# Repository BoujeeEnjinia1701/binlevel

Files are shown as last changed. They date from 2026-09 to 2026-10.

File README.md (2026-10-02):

# BinLevel

     

**Area:** Smart Cities · **TRL:** 3 of 9 (proof of concept on paper) · **Value-engineering target:** about $60 USD · **Difficulty:** 1 of 5

A fill-level sensor for public and communal bins that reports when bins need emptying so collection routes serve full bins, not empty ones.

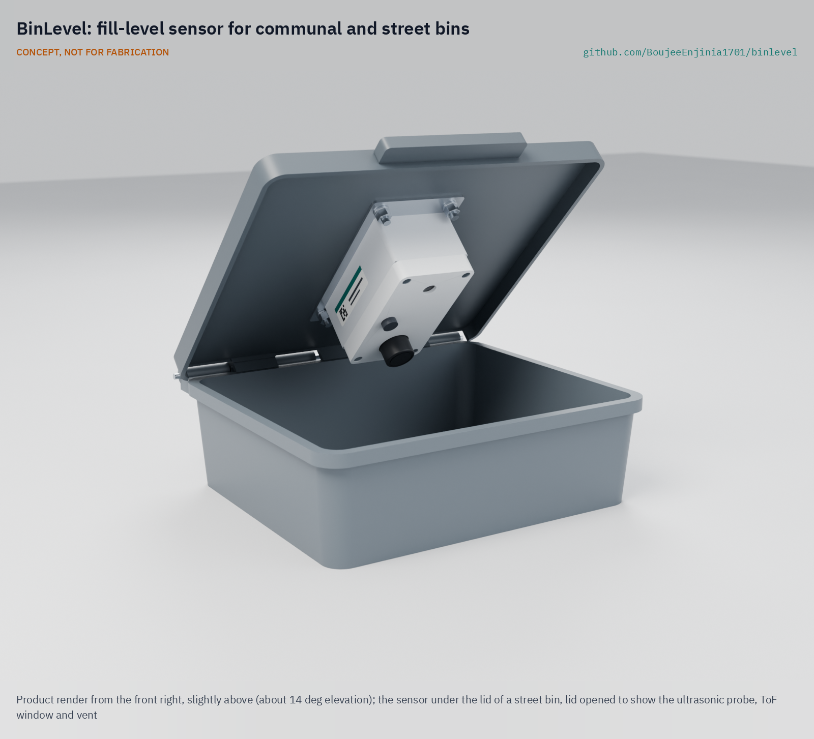
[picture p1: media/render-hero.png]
BinLevel: fill-level sensor for communal and street bins, product render


[Exploded render](media/render-exploded.png) · [Detail render](media/render-detail.png) · [Interactive 3D model](media/viewer.html) · [Concept blueprint (PDF)](media/concept-blueprint.pdf) · [General arrangement BNL-DWG-001 (PDF)](cad/drawings/BNL-DWG-001.pdf) · [Sizing note](docs/04-calcs/01-sizing.md) · [Prototype build plan](docs/05-build-plan.md) · [Design decisions](docs/06-design-decisions.md) · [Review note](docs/REVIEW.md)

## Concept rationale

A collection crew on a fixed timetable cannot tell a full bin from an empty one until it arrives. A small sensor under the lid that measures the distance down to the waste, and says so by radio a few times a day, gives the planner that knowledge before the truck leaves. BinLevel uses the same principle as commercial bin sensors (ultrasonic ranging, tilt and temperature) but adds a cheap time-of-flight sensor for the top of the bin, runs for a decade or more on one primary lithium cell (about 16 years in the worst radio case on paper), and sends only levels, never images or sound.

It is open and garage-buildable because the towns, campuses and community groups that most need better collection are least able to pay per-bin subscriptions for closed sensors. Every part is an off-the-shelf module in a stock enclosure, the payload format is documented, and it talks to any LoRaWAN network, including the lab's TwinKit gateway and The Things Network.

## Burning platform

The world produced about 2.56 billion tonnes of municipal waste in 2022, and the World Bank expects 3.86 billion tonnes by 2050 under business as usual ([World Bank, *What a Waste 3.0*](https://www.worldbank.org/en/publication/what-a-waste)). UNEP estimates the global direct cost of waste management at about USD 252 billion in 2020, rising to about USD 361 billion once the hidden costs of pollution, poor health and climate change are counted ([UNEP, 2024](https://www.unep.org/resources/global-waste-management-outlook-2024)).

The money does not reach everyone. Collection rates are as low as 31 % in Sub-Saharan Africa and 67 % in South Asia, and public spending on waste in most low- and middle-income countries is well below 0.15 % of GDP, against about 0.3 to 0.5 % needed for basic collection ([World Bank](https://www.worldbank.org/en/publication/what-a-waste)). With budgets this tight, a truck trip to a half-empty bin is a trip not made to an overflowing one.

## Where it could be used

### By industry

| Industry | Use |
| --- | --- |
| Municipal waste services and contractors | Plan daily routes around communal containers that are near full; confirm each emptying |
| Housing estates and property managers | Call for collection only when shared 660 to 1,100 L bins need it |
| Markets, ports and transport hubs | Watch high-turnover bins that fill unpredictably with trading and passenger peaks |
| Parks, beaches and tourism | Seasonal litter bins that sit empty in winter and overflow on summer weekends |
| Universities, hospitals and industrial sites | Campus bins and recycling points on private LoRaWAN networks |
| Recycling and deposit schemes | Glass, paper and textile banks that must be emptied before they overflow |

### By country or region

| Country or region | Why it matters there |
| --- | --- |
| Sub-Saharan Africa | Waste collection rates are as low as 31 % ([World Bank](https://www.worldbank.org/en/publication/what-a-waste)); sending scarce trucks to full communal points first stretches the service. |
| South Asia, including India | Collection rates are about 67 % ([World Bank](https://www.worldbank.org/en/publication/what-a-waste)); dense markets and housing produce fast, uneven fill that fixed timetables miss. |
| European Union | Each person generated about 517 kg of municipal waste in 2024 ([Eurostat](https://ec.europa.eu/eurostat/statistics-explained/index.php?title=Municipal_waste_statistics)); high labor costs make every avoided lift valuable. |
| England, United Kingdom | Councils dealt with 1.26 million fly-tipping incidents in 2024/25, 62 % of them household waste ([Defra](https://www.gov.uk/government/statistics/fly-tipping-statistics-for-england/fly-tipping-statistics-for-england-2024-to-2025)); clearing communal bins before they overflow helps keep side waste off the street. |
| United States | Americans generated 292.4 million tons of municipal waste in 2018, about 4.9 lb (2.2 kg) per person per day ([US EPA](https://www.epa.gov/facts-and-figures-about-materials-waste-and-recycling/national-overview-facts-and-figures-materials)); parks and campuses run large fleets of street bins. |

## What sparked the idea

The starting point was Philadelphia's 2009 rollout of 500 solar-powered BigBelly compactors, which replaced about 700 wire baskets on the promise that sensor-reported fullness would cut collections from 17 trips a week to five ([US EPA](https://archive.epa.gov/international/jius/web/html/bigbelly_trash_compactors.html)). In July 2010 City Controller Alan Butkovitz reported that collections averaged about 10 a week, that each compactor had cost about $3,700, and that the city had relied solely on the maker's claims without independent verification ([NBC10 Philadelphia](https://www.nbcphiladelphia.com/news/local/bigbelly-trash-compactors-a-big-fat-waste-of-money-controller/2140012/)). Both sides agreed that knowing how full a bin is saves trips; the dispute was over how much, and only the vendor held the data. BinLevel separates that knowledge from the bin: a sensor with about $55 of parts, roughly 1.5 % of the price of one of those compactors, that fits containers a city already owns, with an open payload so the city can check the savings itself.

## Problem

Fixed collection schedules empty half-full bins while others overflow. Cities and communities have no cheap, open way to know how full each bin is before the truck leaves.

## Concept

A sealed box under the bin lid measures the distance to the waste every 15 minutes with an ultrasonic transducer, backed by a time-of-flight sensor for the top of the bin. It sends fill level, temperature, emptying events and battery state in an 11-byte LoRaWAN uplink every hour (every 2 hours at SF12), or at once when the bin passes a set level (default 80 %). A primary lithium C cell lasts about 16 years in the worst radio case on paper, so the 10-year design life is set by seals and plastics. Parts cost $59.00 (indicative), within the $60 value-engineering target; the unit weighs about 350 g, inside its 400 g target. No camera, no microphone.

Full design precis: [docs/02-concept.md](docs/02-concept.md). Requirements, including those not yet met (IP69K washing and radio inside steel containers) and those at risk (accuracy on real waste and hot lids): [docs/03-requirements.md](docs/03-requirements.md). Sizing calculations: [docs/04-calcs/01-sizing.md](docs/04-calcs/01-sizing.md). Decisions by Amish: [docs/decisions/0001-trl2-review-decisions.md](docs/decisions/0001-trl2-review-decisions.md) and [docs/decisions/0002-recommendations-accepted.md](docs/decisions/0002-recommendations-accepted.md); design for construction, accepted on 2026-10-02: [docs/decisions/0003-design-for-construction.md](docs/decisions/0003-design-for-construction.md). Every open and made decision: [docs/06-design-decisions.md](docs/06-design-decisions.md).

## Key components

- Stock IP67 enclosure (115 x 65 x 55 mm) held on four press-in studs in a 2 mm aluminium plate, bolted under the lid with four stainless tamper-resistant M6 bolts
- Sealed 40 kHz ultrasonic transducer (main range, from about 0.25 m to the container floor)
- Near-range time-of-flight sensor (top 0.4 m of the bin, where the 80 % threshold lies)
- RAK3172 (STM32WL) LoRaWAN module, the same radio family as FieldNode
- Carrier board with accelerometer (emptying and lid events), temperature sensor and nanopower regulator
- Li-SOCl2 C cell, multi-year life
- Flexible antenna inside the box; the first pilot uses plastic containers only, and an external lid antenna for steel containers is a later option

The working bill of materials is in [bom/bom.csv](bom/bom.csv).

## Building the prototype

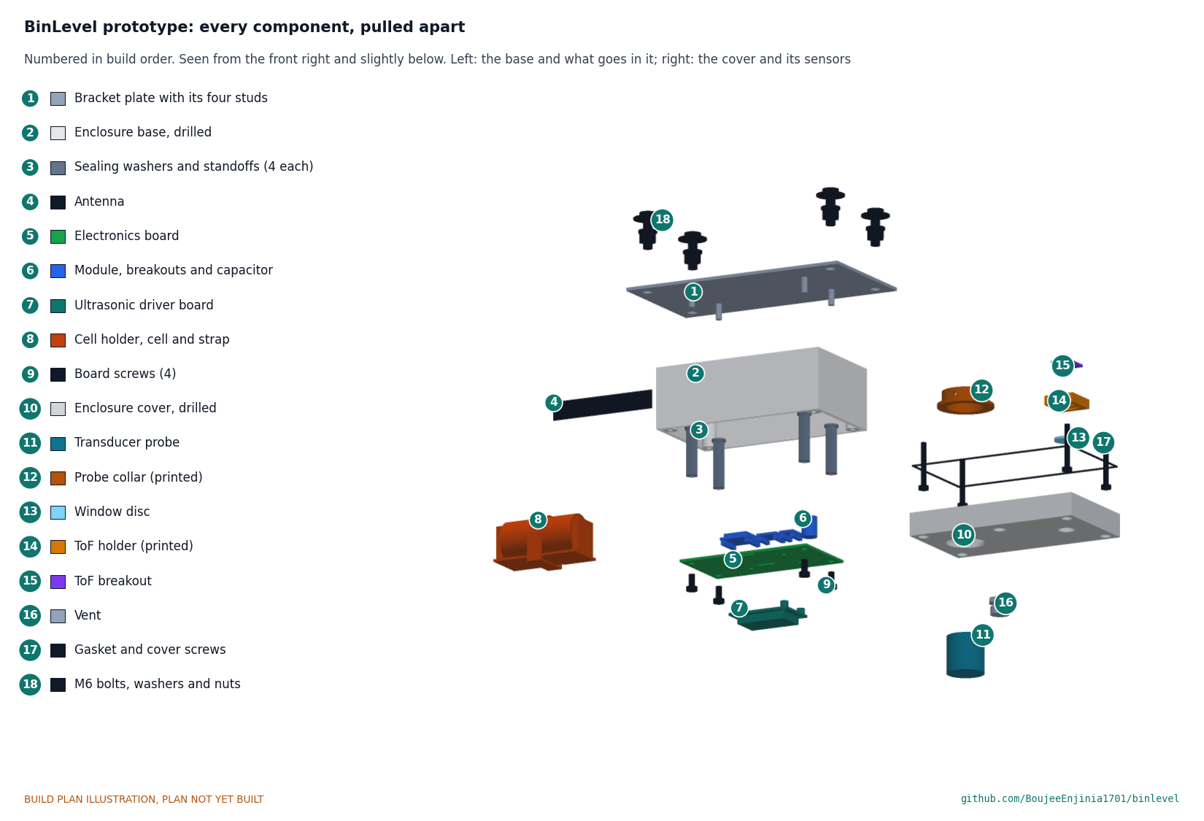
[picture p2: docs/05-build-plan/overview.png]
Every component of the BinLevel prototype, pulled apart and numbered in build order


The prototype build plan ([docs/05-build-plan.md](docs/05-build-plan.md)) shows how to make each component and fit it to the next, with a making sketch for every made part and a picture for every assembly step. The box hangs under a flat aluminium plate on four pressed-in studs; the electronics board, cell and antenna sit in the box's base, and the transducer, light sensor window and vent sit in its downward-facing cover. The work is drilling thin aluminium and plastic, two small 3D prints, bonding and soldering bought breakout boards, for about $59 in parts. It is a plan, not yet built: building and testing to it is TRL 4 work.

## Safety

> The Li-SOCl2 cell is a primary lithium cell: never charge, short, crush or overheat it, fuse it, and recycle spent cells through a battery collection point, never in the bin. Bins hold sharp objects and biological waste: install and service sensors only on emptied, cleaned containers with cut-resistant gloves and eye protection, and deburr drilled lids. The temperature alert is a maintenance aid, not fire detection.

## Repository layout

| Folder | Contents |
| --- | --- |
| `docs/` | Problem, concept, requirements, calculations and design decisions |
| `cad/src/` | build123d Python source, the source of truth for all geometry |
| `cad/step/`, `cad/stl/` | Exported models for FreeCAD, other CAD tools and printing |
| `cad/drawings/` | 2D sketches and dimensioned drawings |
| `bom/` | Bill of materials |
| `electronics/` | KiCad schematics and PCB layouts |
| `firmware/` | Microcontroller code |
| `media/` | Renders, perspectives and photos |
| `build-log/` | Dated prototyping notes |

## Documentation

Controlled documents follow the portfolio [documentation standard](.kit/STANDARDS.md). Each carries a document ID (BNL-PRC-001 for the precis), a version and a revision history. Branded PDFs are built with `python .kit/render.py` and attached to GitHub Releases when a document is tagged, for example `BNL-PRC-001/v1.0`.

## Credits

Designed by Amish Chadha. See [CONTRIBUTORS.md](CONTRIBUTORS.md) for roles. To cite this design, use [CITATION.cff](CITATION.cff) (GitHub shows it as "Cite this repository").

AI assistance (Claude) was used to accelerate concept renders, prototype documentation and first-pass sizing calculations. Design direction and all decisions are Amish Chadha's, recorded in this repository's decision records (`docs/decisions/`).

## Licenses

- **Hardware** (CAD, drawings, BOM, electronics): [CERN-OHL-S v2](LICENSE)
- **Software** (firmware, scripts, notebooks): [MIT](LICENSE-SOFTWARE)

A project of the [Design Molecule](https://designmolecule.com) lab.

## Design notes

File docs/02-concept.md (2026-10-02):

---
doc_id: BNL-PRC-001
title: BinLevel design precis
project: BinLevel
doc_type: Design precis
version: "0.7"
status: Draft
date: '2026-10-02'
author: Amish Chadha
license: CERN-OHL-S-2.0
revisions:
- version: "0.1"
  date: '2026-09-25'
  author: Amish Chadha
  change: Initial scaffold
- version: "0.2"
  date: '2026-09-25'
  author: Amish Chadha
  change: Concept for TRL 2 with components, first-order numbers, safety and open questions
- version: "0.3"
  date: '2026-09-25'
  author: Amish Chadha
  change: Design choices adopted for TRL 3 (BNL-DDR-001); numbers checked against BNL-CAL-001; 11-byte payload, nanopower regulator, 5 min temperature reads and cell strap added
- version: "0.4"
  date: '2026-09-25'
  author: Amish Chadha
  change: Recommendations accepted by Amish (DDR-002)
- version: "0.5"
  date: '2026-09-30'
  author: Amish Chadha
  change: Design for construction (BNL-DDR-003); 55 mm box, box fixings and printed sensor mounts added; mass, envelope and cost from BNL-CAL-001 v0.3
- version: "0.6"
  date: '2026-10-01'
  author: Amish Chadha
  change: Budget treated as a value-engineering target
- version: "0.7"
  date: '2026-10-02'
  author: Amish Chadha
  change: "Open decisions of 2026-10-02 carried in: steel containers out of the first pilot, galvanic isolation, data layer, fill rate left to the server, first partner to approach"
---

# BinLevel design precis

## Summary

BinLevel is a small sealed box bolted under the lid of a communal or public bin. Every 15 minutes it measures the distance down to the waste with a sealed ultrasonic transducer, backed by a time-of-flight (ToF) sensor for the top of the bin, and turns it into a fill percentage. It sends the level, temperature, tilt events and battery state by LoRaWAN every hour (every 2 hours at SF12), or at once when the bin passes a set level. A primary lithium C cell would last about 16 years in the worst radio case on paper, so seals and plastics, not the cell, set the 10-year design life. Parts cost is $59.00 (indicative), within the $60 value-engineering target, and the unit weighs about 350 g, inside the 400 g target (BNL-CAL-001). The design is constructable (BNL-DDR-003), and the prototype build plan BNL-BLD-001 shows how to build it. It carries no camera and no microphone.

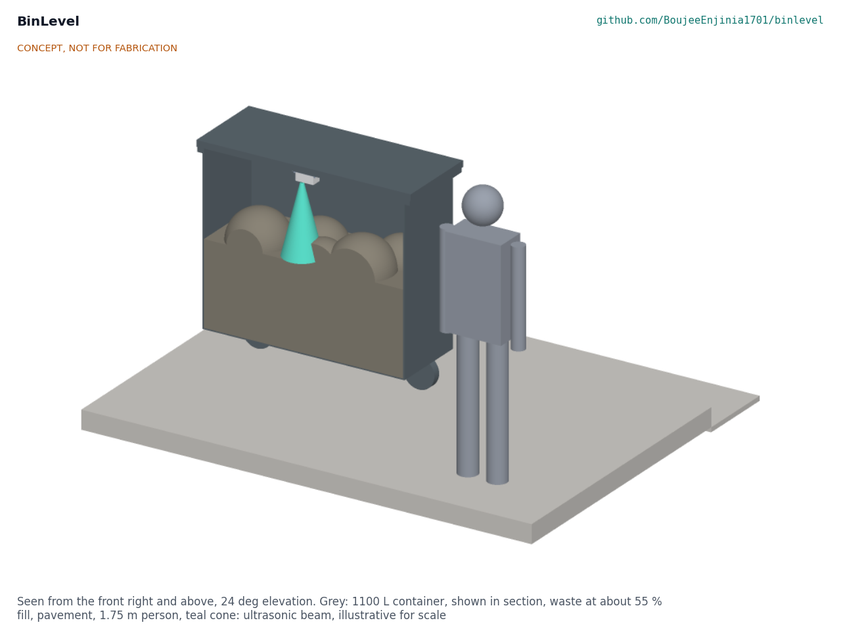
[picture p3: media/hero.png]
Figure 1. BinLevel under the lid of an 1,100 L communal container, shown in section, with a 1.75 m person for scale. Concept, not for fabrication.


## How it works

1. **Measure.** The microcontroller wakes every 15 minutes, switches on the ultrasonic transducer and takes five pings, then reads the ToF sensor. It keeps the median ultrasonic distance and uses the ToF reading when the surface is closer than the ultrasonic blind zone (about 0.25 m, estimate).
2. **Interpret.** Distance is converted to fill percentage against the empty depth stored at installation. A fill above the threshold (default 80 %) or an abnormal temperature, read every 5 min, triggers an immediate uplink. The heat rule is 70 °C, or a rise of 15 K in 15 min counted only while the unit is above 50 °C, so a sunny lid does not raise false alarms.
3. **Sense events.** A low-power accelerometer wakes the controller when the bin is tipped (emptying confirmed) or when the lid is opened (usage count), so the service gets proof of collection without a driver app.
4. **Report.** A LoRaWAN Class A uplink of 11 bytes carries fill %, raw distance, temperature, event counters and battery voltage. Any LoRaWAN network server can receive it: the lab's TwinKit gateway, The Things Network or a city network.
5. **Plan.** The server passes levels to a route planner, which schedules the bins that are full or will be full before the next round (Figure 2).

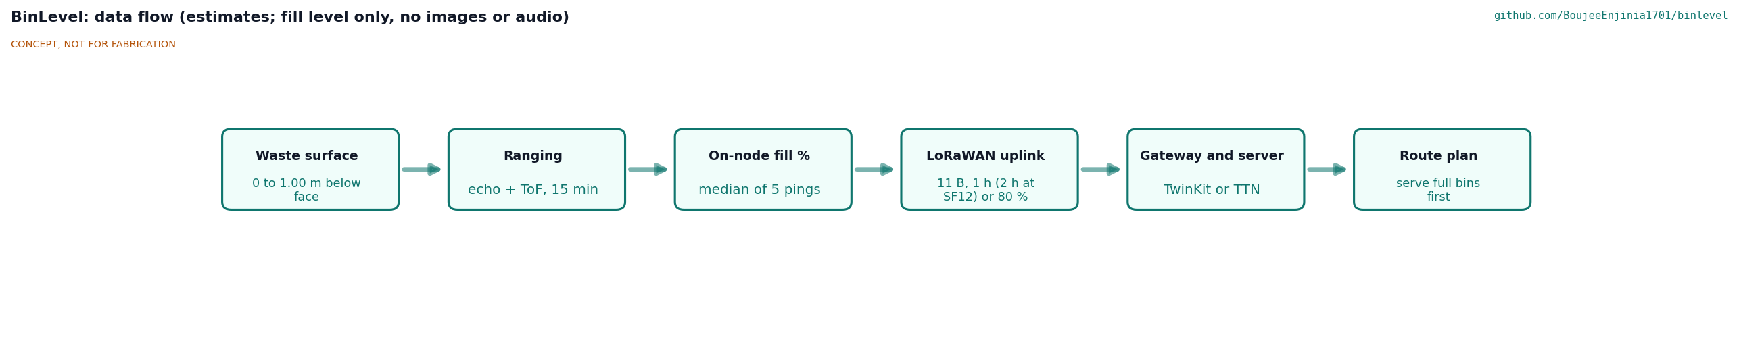
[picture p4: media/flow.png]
Figure 2. Data flow from waste surface to route plan. Values are estimates. Fill level only; no images or audio.


## Main components

Numbers match the exploded view (Figure 3) and `bom/bom.csv`. Main dimensions and interfaces are on the general arrangement drawing BNL-DWG-001 (`cad/drawings/BNL-DWG-001.pdf`), generated from `cad/src/model.py`.

| No. | Component | Role |
| --- | --- | --- |
| 1 | Enclosure, IP67 ABS or PC, about 115 x 65 x 55 mm, cover facing down | Protects electronics; holes for transducer, ToF window and vent in the cover |
| 2 | Aluminium bracket plate, 2 mm 5052 class, and four stainless tamper-resistant M6 x 20 bolts on a 130 x 60 mm pattern | Fixes the unit under the lid; bolts pass through the lid |
| 3 | Sealed 40 kHz ultrasonic transducer (JSN-SR04T class) with driver | Main range sensor, about 0.25 to 1.5 m (estimate) |
| 4 | Near-range ToF sensor (VL53L1X class) behind a window | Top of bin and overfill, about 0.03 to 0.4 m (estimate) |
| 5 | LoRaWAN module, RAK3172 (STM32WL) | Controller and radio in one module, as in FieldNode |
| 6 | Carrier board with accelerometer, temperature sensor, nanopower regulator, load switch and buffer capacitor (a prototyping board with breakouts for the first prototype) | Joins the parts; powers sensors only while measuring; keeps the module below 3.6 V |
| 7 | Li-SOCl2 primary cell, C size, 3.6 V, about 8.5 Ah nominal, with strapped holder and fuse | Multi-year energy store |
| 8 | Flexible 868/915 MHz antenna | Radio antenna inside the enclosure (external lid antenna for steel bins is a later option; not in the first pilot) |
| 9 | Gasket and vent membrane | Keeps water and condensation out |
| 10 | Box fixings: four press-in studs in the plate, sealing washers and standoffs | Hold the box to the plate and carry the board |
| 11 | Printed probe collar and ToF holder, window disc | Hold the sensors in the cover |

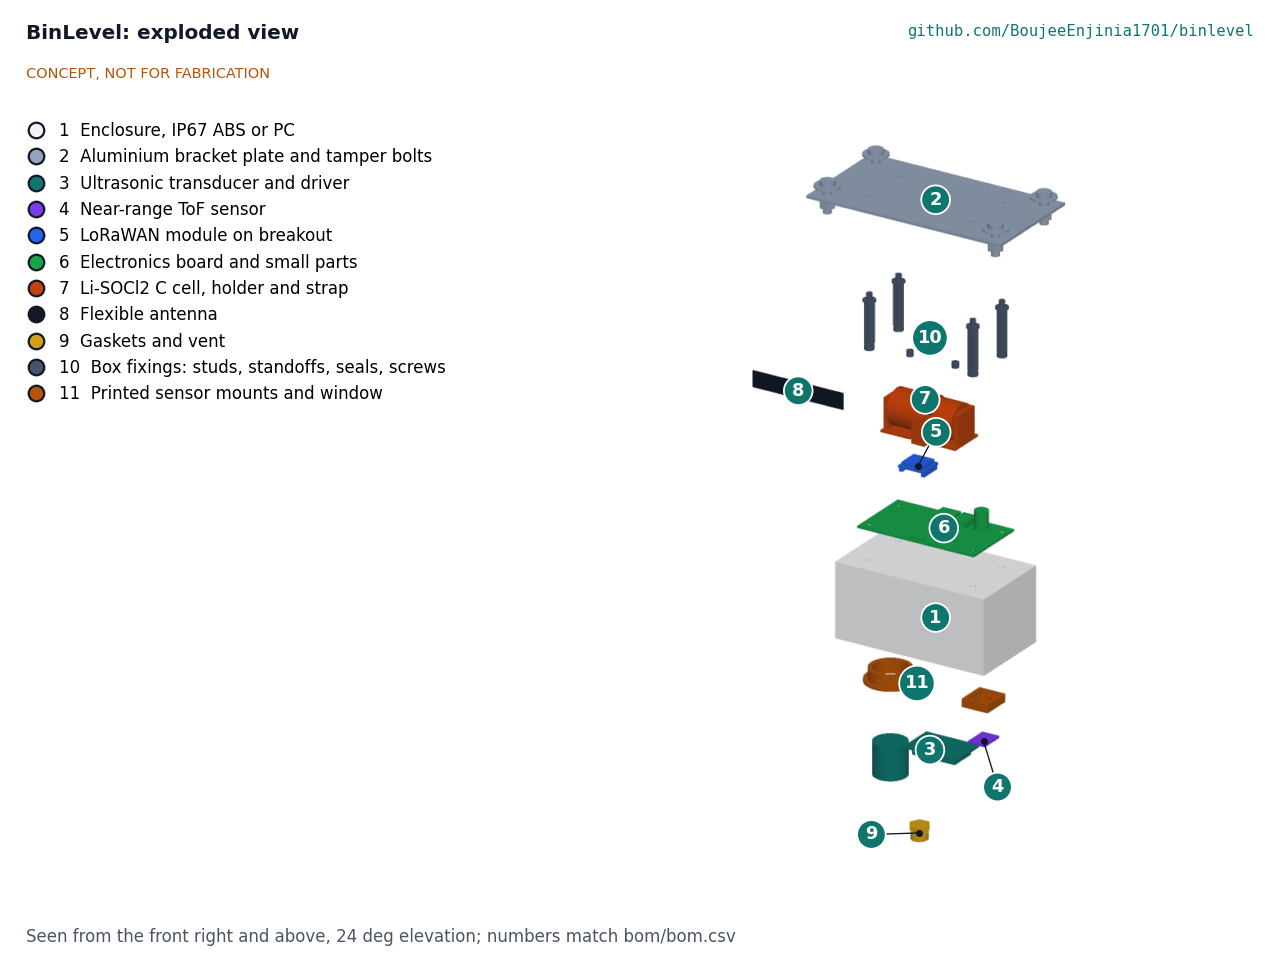
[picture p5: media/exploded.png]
Figure 3. Exploded view with BOM numbers. Concept, not for fabrication.


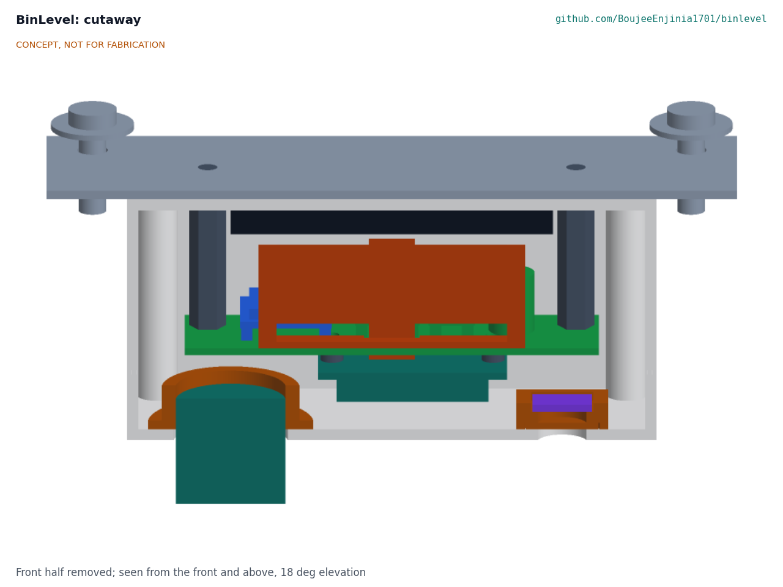
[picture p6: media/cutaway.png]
Figure 4. Cutaway of the sensor unit showing the cell, carrier PCB, module, transducer and ToF sensor. Concept, not for fabrication.


## First-order numbers

The numbers below are from the sizing note BNL-CAL-001, which checks every requirement against the parametric model `cad/src/model.py`. They are paper estimates, not measurements.

### Energy budget

Sleep current is 6.0 µA for the whole unit (module 2.0 µA, accelerometer 2.0 µA, temperature sensor 0.5 µA, regulator and leakage 0.5 µA, buffer capacitor 1.0 µA). Each ranging cycle takes 7.5 mAs; each uplink transmits at +14 dBm at an assumed 45 mA. Usable capacity is taken as 60 % of nominal, with self-discharge of 1 % of nominal a year.

Table 1. Daily charge use and life, with two alert uplinks a day (BNL-CAL-001, section C).

| Item | SF9, hourly uplink | SF12, uplink every 2 h |
| --- | --- | --- |
| Sleep (6.0 µA x 24 h) | 0.144 mAh | 0.144 mAh |
| Ranging (96 cycles) and temperature reads | 0.201 mAh | 0.201 mAh |
| Uplinks | 0.086 mAh (26 x 0.21 s airtime) | 0.278 mAh (14 x 1.48 s airtime) |
| Self-discharge (C cell) | 0.233 mAh | 0.233 mAh |
| **Total** | **0.664 mAh per day** | **0.856 mAh per day** |
| Life on C cell (5.1 Ah usable) | 21.0 years | 16.3 years |
| Life on AA cell (1.56 Ah usable) | 8.5 years | 6.2 years |

The cell is not the limit on life; seals, the transducer membrane and the enclosure plastic under UV and heat are. The design target is therefore stated as 10 years (R4). The AA cell would meet the 5-year minimum but not the 10-year target, which is why the C cell is adopted (DDR-001, D3).

A fresh Li-SOCl2 cell rests at 3.67 V, above the RAK3172 module's 3.6 V maximum ([RAK3172 datasheet](https://docs.rakwireless.com/product-categories/wisduo/rak3172-module/datasheet/)), so the carrier includes a nanopower 3.3 V regulator. The cell carries the transmit pulse; a 1,000 µF low-leakage capacitor covers the voltage delay of a passivated cell.

### Radio airtime

The payload is 11 bytes (it was 12 at TRL 2), so that it fits the 11-byte limit of the slowest US915 data rate. It takes about 0.21 s at SF9 and about 1.48 s at SF12 (125 kHz). Hourly uplinks with two alerts use about 5.4 s per day at SF9, well inside TTN's 30 s daily fair use, but 38.6 s at SF12, which would exceed it. SF11 hourly uses 21.4 s. The firmware therefore stretches the routine interval to 2 hours at SF12 only (20.8 s per day) and keeps threshold alerts immediate (DDR-001, D6, as refined by DDR-002).

### Link

With a 10 dB fade margin and an urban path-loss model, a sensor in an HDPE container reaches a gateway about 0.8 km away at SF9 and 1.3 km at SF12. Inside a steel container the range falls to about 0.35 km even at SF12; an external lid antenna restores 1.3 to 2.1 km. Steel containers are left out of the first pilot, which uses plastic containers only (decided by Amish, 2026-10-02; DDR-001, O1); the antenna is revisited once the link loss inside a steel container has been measured.

### Measurement

- The transducer face is 1.00 m above the floor of an 1,100 L container. At 80 % fill the surface is 0.20 m below the face, inside the ultrasonic blind zone (about 0.25 m, estimate), which is why the ToF sensor covers the top 0.4 m. The two sensors overlap between 60 % and 75 % fill.
- The instrument error, with speed of sound compensated from the on-board temperature, is about 10 mm for the ultrasonic sensor and 20 mm for the ToF sensor, against the ±101 mm (±10 % of depth) accuracy target. Accuracy on real waste is limited by the surface, not by the sensor.
- An ultrasonic beam of 15° half-angle (assumed) covers a patch about 0.54 m across at the floor. Mounted at the lid center, the beam clears the walls for half-angles up to about 26°.
- The temperature is read every 5 min (not only with each 15 min ranging), so a heat alert reaches the server within about 7.5 min.

### Mass and cost

- Mass about 350 g: enclosure 94 g, 2 mm aluminium plate 63 g, bolts, nuts and washers 36 g, box fixings 22 g, cell, holder and strap 59 g, transducer, board, module, printed mounts and small parts about 76 g. This is inside the 400 g limit of R16. The 1.5 mm stainless bracket of BNL-PRC-001 v0.3 weighed 183 g and made the unit about 435 g; Amish chose the aluminium bracket on 2026-09-25 (DDR-002).
- Envelope below the lid 150 x 80 x 71.5 mm.
- Parts cost $59.00 at prototype quantities (indicative prices; see `bom/bom.csv`), inside the $60 value-engineering target. The gateway is shared across many bins and not included.

## Key design choices (decided by Amish, 2026-09-25)

Each choice below was decided by Amish on 2026-09-25 (go with recommendation) and is recorded in [decisions/0001-trl2-review-decisions.md](decisions/0001-trl2-review-decisions.md) (BNL-DDR-001) and [decisions/0002-recommendations-accepted.md](decisions/0002-recommendations-accepted.md) (BNL-DDR-002).

1. **Ultrasonic plus ToF, rather than ultrasonic alone or ToF alone (D2).** Ultrasonic tolerates dust and dirt on the face and is the method used by commercial bin sensors ([Sensoneo](https://www.sensoneo.com/products/ultrasonic-bin-sensor/)). Low-cost sealed transducers cannot see the top 0.25 m, where the full threshold lies, so a ToF sensor covers that zone for about $5.
2. **Lid underside mounting (D8).** Keeps the unit out of the waste, out of sight and away from vandals. The cost is that lid opening moves the sensor, which the accelerometer detects and skips.
3. **Primary Li-SOCl2 C cell, not rechargeable or solar (D3).** No charging electronics, no panel to break on a tipped bin, and very low self-discharge.
4. **LoRaWAN on an STM32WL-class module (D4).** The RAK3172 shares the radio core and firmware approach adopted for FieldNode, so decoders and gateway set-up are common. The RAK3172-T variant (-40 to 85 °C) is named for sites colder than -20 °C (DDR-002). NB-IoT would avoid gateways but needs a SIM subscription per bin.
5. **Stock enclosure at TRL 2 to 3 (D9).** Keeps the build garage-friendly; a potted or IP69K design is a later option.
6. **Relationship to FieldNode and TwinKit (D5).** BinLevel does not use the FieldNode enclosure, panel or LiFePO4 cell: at $126 the FieldNode core costs more than twice the BinLevel value-engineering target and would not fit under a lid. It reuses FieldNode's radio module family, payload conventions and decoder so both sit on the same TwinKit gateway.
7. **First target container (D1), thresholds (D6) and temperature alert (D7).** The 660 to 1,100 L communal container is the design case; the default fill threshold is 80 %, the routine interval 1 h (2 h at SF12 only, DDR-002), and the heat alert 70 °C or a 15 K rise in 15 min. BNL-CAL-001 found that the ungated rate-of-rise trigger could fire when sun breaks through cloud, so under DDR-002 the rise counts only above 50 °C; the requirement R6 upper limit is also raised to 70 °C to match hot dark lids.
8. **Aluminium bracket (DDR-002).** A 2 mm 5052-class aluminium plate replaces 1.5 mm stainless, taking the unit from about 435 g to 334 g so that it meets R16 (350 g after the design for construction, BNL-DDR-003). The bolts stay stainless; galvanic isolation between them and the plate: nothing is fitted for the prototype, and for deployments the plate is anodised before the studs are pressed in (decided by Amish, 2026-10-02).

## Safety

> **Safety:** The Li-SOCl2 cell is a primary lithium cell with high energy density. Never charge it, short it, crush it or heat it above its rated limit; a damaged cell can vent toxic, corrosive gas or catch fire. Fit a fuse or PTC in series, use a holder that prevents reverse insertion, and dispose of spent cells through a battery recycler, never in the bin itself.

> **Safety:** Bins can hold sharp objects, needles, broken glass and biological waste. Fit and service sensors only on emptied and cleaned containers, wear cut-resistant gloves and eye protection, and keep drill swarf out of the container. Drilling a lid leaves sharp edges; deburr them.

> **Safety:** Bins can catch fire from hot ash or discarded batteries. The temperature alert in R9 is a maintenance aid and must not be relied on as fire detection. The unit itself contains a lithium cell, which adds fuel to a bin fire.

> **Safety:** Keep clear of the lifting mechanism of collection trucks when installing or testing on containers in service.

## Open questions

- [ ] Can a sealed low-cost transducer survive years of condensation and food acids, or is a potted industrial transducer needed?
- [ ] Does the ToF window fog or foul too quickly to be useful? A heater is ruled out (a 20 mW heater would use 156 times the energy budget, BNL-CAL-001); is a hydrophobic coating or a wiper enough?
- [ ] What is the real link loss inside HDPE and steel containers? BNL-CAL-001 assumes 10 dB and 30 dB. Steel containers are left out of the first pilot until this is measured (decided 2026-10-02; BNL-DDR-001, O1).
- [ ] Is IP67 enough for the first partner's washing practice? The first partner to approach is a municipal waste service or its contractor using EN 840 plastic communal containers in a city with public LoRaWAN coverage, by default a European city on EU868; its washing practice is asked before committing (decided 2026-10-02).
- [x] Which route planner and data layer should the pilot use? TwinKit as the data layer, feeding a standard open-source vehicle routing tool; a city system only if the pilot partner already runs one (decided 2026-10-02).
- [x] Should the payload also carry a rolling fill-rate estimate? No: the server estimates the fill rate from the history, and the spare payload byte stays free (decided 2026-10-02).

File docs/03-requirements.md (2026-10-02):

---
doc_id: BNL-REQ-001
title: BinLevel requirements
project: BinLevel
doc_type: Requirements
version: "0.7"
status: Draft
date: '2026-10-02'
author: Amish Chadha
license: CERN-OHL-S-2.0
revisions:
- version: "0.1"
  date: '2026-09-25'
  author: Amish Chadha
  change: Initial scaffold
- version: "0.2"
  date: '2026-09-25'
  author: Amish Chadha
  change: First measurable requirements for TRL 2, with status against the concept
- version: "0.3"
  date: '2026-09-25'
  author: Amish Chadha
  change: Status checked by calculation (BNL-CAL-001); adopted defaults from BNL-DDR-001 written into R3 and R9; 11-byte payload
- version: "0.4"
  date: '2026-09-25'
  author: Amish Chadha
  change: Recommendations accepted by Amish (DDR-002)
- version: "0.5"
  date: '2026-09-30'
  author: Amish Chadha
  change: Design for construction (BNL-DDR-003); R1, R14 and R16 figures updated from BNL-CAL-001 v0.3; no status changed
- version: "0.6"
  date: '2026-10-01'
  author: Amish Chadha
  change: Budget treated as a value-engineering target
- version: "0.7"
  date: '2026-10-02'
  author: Amish Chadha
  change: "R10 note: steel containers left out of the first pilot (decided 2026-10-02, BNL-DEC-001)"
---

# BinLevel requirements

These requirements are the TRL 3 design basis. The design choices behind them were decided by Amish on 2026-09-25 (go with recommendation; BNL-DDR-001 and BNL-DDR-002). Under DDR-002, R6's upper limit is raised from 60 to 70 °C, R9's rate-of-rise rule counts only above 50 °C, and R3's 2 h interval applies at SF12 only; no other target changed. Under BNL-DDR-003 (design for construction, 2026-09-30, accepted by Amish on 2026-10-02) the box grows to 55 mm and gains studs, standoffs and printed sensor mounts; the mass, envelope, geometry and cost figures below are updated and no requirement changed status. Status is from the sizing note BNL-CAL-001 v0.3, which checks each requirement against the parametric model: two are not met (R5, R10 in steel containers), two are at risk (R2, R6), two can only be settled by test (R7, R12) and ten are met (six by calculation, four by design). See the notes under Table 1.

Table 1. Requirements.

| ID | Requirement | Target | Verification (TRL 3 or later) | Status at TRL 3 (BNL-CAL-001) |
| --- | --- | --- | --- | --- |
| R1 | Measure distance from lid to waste surface over the full depth of the target container | 0.03 to 1.5 m below the sensor face | Calculation and datasheet review; later bench test in a container | Met: 0 to 1.00 m needed; ultrasonic from 0.25 m, ToF to 0.4 m, overlapping between 60 % and 75 % fill (datasheet ranges to confirm) |
| R2 | Report fill level accurately on real mixed waste | Within ±10 % of container depth for 90 % of readings | Error budget; later field comparison against manual dip readings | **At risk**: instrument error about 10 mm (ultrasonic) and 20 mm (ToF) of the ±101 mm allowance; the waste surface is unknown |
| R3 | Report often enough to plan routes, and quickly when full | Routine uplink at least every 2 h (default 1 h, 2 h at SF12 only); threshold alert within 20 min of crossing the set fill level (default 80 %) | Timing calculation | Met: worst-case alert 17.5 min |
| R4 | Run for years on one battery | 5 years or more in the worst radio case (SF12); 10 years design target | Power budget calculation | Met: 16.3 years on a C cell at SF12; enclosure and seals, not the cell, limit life |
| R5 | Survive rain, condensation and washing | IP67 minimum; IP69K target where containers are pressure washed | Enclosure datasheet; later spray test | **Not met for IP69K**: stock IP67 box (DDR-001, D9) |
| R6 | Operate across the climate range | -20 to +70 °C inside the container (raised from +60 °C, DDR-002); RAK3172-T for sites colder than -20 °C | Heat balance and datasheet review | **At risk**: a dark lid reaches about 67 °C on a 40 °C day, 3 K inside the limit; the standard module is rated only down to -20 °C; transducer rating and condensation unverified |
| R7 | Survive lifting, tipping and lid slams | Repeated shocks of the emptying cycle without loosening; target IK08 impact on the enclosure | Load calculation; later drop and shake test | Not verifiable at TRL 3: 85 N at 20 g against about 4,200 N per bolt; loosening and impact need a test |
| R8 | Detect and report emptying and lid events | Tip event from the accelerometer reported with the next uplink | Firmware logic review | Met by design |
| R9 | Warn of abnormal heat in the bin | Alert uplink within 15 min when temperature exceeds 70 °C, or rises more than 15 K in 15 min while above 50 °C (gate added, DDR-002) | Timing calculation and heat balance | Met on paper: alert within 7.5 min with temperature read every 5 min; sun through cloud starts the unit at about 43 °C, below the gate, and above it the worst sun rise is 10.9 K; maintenance aid only, not a fire detector |
| R10 | Connect over open LoRaWAN within radio rules | LoRaWAN 1.0.x Class A; EU868, US915 and IN865 plans; within duty cycle and TTN's 30 s per day fair use | Airtime and link calculation; later range test | **Not met in steel containers** with the internal antenna (about 0.35 km at SF12); met in HDPE containers: 20.8 s per day at SF12, 11-byte payload fits US915 DR0, about 0.8 to 1.3 km range |
| R11 | Protect privacy | No camera or microphone; payload limited to fill, distance, temperature, tilt, events and battery | Design review of BOM and payload | Met by design |
| R12 | Install without wiring or tools beyond a drill | Fit to a lid in 10 min or less with four bolts or rivets; no cables | Timed trial at TRL 4 | Not verifiable at TRL 3: four through-bolts on a 130 x 60 mm pattern, no cables |
| R13 | Resist casual tampering and theft | Mounted inside the lid; tamper-resistant fasteners | Design review | Met by design |
| R14 | Low cost and buildable | Parts cost at or under the $60 value-engineering target per sensor at prototype quantities (a hypothetical control target); no custom tooling | Priced BOM | Within the value-engineering target: $59.00 (indicative, $1.00 under, BNL-DDR-003); $67.00 with the external antenna option ($7.00 over) |
| R15 | Open and interoperable | Documented payload format and open decoder; works with any LoRaWAN network server | Documentation review | Met by design: candidate 11-byte layout in BNL-CAL-001 |
| R16 | Light and compact | 400 g or less; no larger than 160 x 90 x 100 mm below the lid, including bracket | Mass calculation from the model, then weighing | Met: about 350 g with a 2 mm aluminium plate and the 55 mm box (DDR-003; 334 g before, 435 g with 1.5 mm stainless); 150 x 80 x 71.5 mm |

Notes on requirements not met or at risk:

- **R2 at risk.** Ultrasonic echoes from bags, boxes and bulky items are uneven, and the waste surface is rarely flat. The mitigation is to take the median of several pings and to combine the two sensors, but accuracy on real waste is unknown until measured.
- **R5 not met for IP69K.** A low-cost stock enclosure is typically rated IP67. Where containers are washed with hot pressure water, a sealed potted design or an IP69K enclosure is needed, which raises cost.
- **R6 at risk.** The upper limit is now 70 °C (DDR-002), above the about 67 °C a dark lid reaches in hot sun, but the margin is only 3 K and the transducer's rating is unconfirmed. The RAK3172-T (-40 to 85 °C) is named for cold sites.
- **R10 not met in steel containers.** An antenna inside a steel container loses about 30 dB (assumed). HDPE containers are fine within about 1 km of a gateway. Amish decided on 2026-10-02 to leave steel containers out of the first pilot, which uses plastic containers only; the external lid antenna is revisited once the link loss inside a steel container has been measured (DDR-001, O1; BNL-DEC-001). R10 stays not met in steel containers.

## Assumptions

- Target container: 1,100 L four-wheel communal container (DDR-001, D1), lid underside 1.07 m above the inner floor and transducer face 1.00 m above it (from the parametric model).
- Fill level is reported as a percentage of the distance from the sensor face to the container floor, measured at installation.
- Worst radio case is spreading factor 12 at 125 kHz with an 11-byte payload (1.48 s airtime per uplink); typical urban case is SF9 (0.21 s).
- A dark lid may reach about 67 °C on a 40 °C day in full sun (BNL-CAL-001, section H; to be measured).

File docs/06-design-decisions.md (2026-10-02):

---
doc_id: BNL-DEC-001
title: BinLevel design decisions register
project: BinLevel
doc_type: Design decisions register
version: "0.3"
status: Draft
date: '2026-10-02'
author: Amish Chadha
license: CERN-OHL-S-2.0
revisions:
  - version: "0.1"
    date: '2026-09-30'
    author: Amish Chadha
    change: Register opened with the open decisions from the review note, the decision records and the build plan work
  - version: "0.2"
    date: '2026-10-01'
    author: Amish Chadha
    change: Budget treated as a value-engineering target
  - version: "0.3"
    date: '2026-10-02'
    author: Amish Chadha
    change: Amish approved the recommendations for open decisions 1 to 8 (BNL-DDR-003 accepted); moved to decisions made
---

# BinLevel design decisions register

Every design decision still to be made, and every decision made, in one place. Each decision is argued in full in its decision record under `docs/decisions/`; this register is the index Amish works from. The build plan (`docs/05-build-plan.md`) describes the design as it stands and does not list open decisions.

## Open decisions

None. All open decisions were decided on 2026-10-02.

## To confirm when parts are bought

| # | What to confirm | Why it matters | Source |
| --- | --- | --- | --- |
| 1 | The stock box: 115 x 65 x 55 mm outside, a 15 mm deep cover, corner towers about 9 mm across at about 51 and 26 mm from the centre lines, and a flat base floor | The board size, the stud positions and the sealing washers depend on it | BNL-DDR-003, P1, P4 and P8 |
| 2 | The transducer probe's diameter (24 mm assumed), its cable plug and its temperature rating | Sets the 25 mm hole and the collar bore; R6 is at risk on the rating | BNL-DDR-003, P5; BNL-CAL-001, section H |
| 3 | The driver board's size and mounting holes (about 41 x 28 mm assumed) | Sets the four driver holes in the electronics board and its clearance to the probe and the holder | BNL-DDR-003, P3 |
| 4 | The light sensor breakout's size, holes and sensor position (13 x 18 mm, sensor underneath, assumed) | Sets the holder pocket | BNL-DDR-003, P6 |
| 5 | The press-in stud's hole size, minimum sheet thickness and push-out rating in 2 mm 5052 aluminium (4.2 mm and about 900 N assumed) | The plate holes and the fixing check | BNL-CAL-001, [J3] |
| 6 | The cell holder takes a C cell with room for the strap slots | Cell retention at 20 g | BNL-CAL-001, [J2] |

## Value engineering

Value-engineering target: USD 60 (a hypothetical control target, not a limit). Estimated cost of the constructable design: USD 59 (USD 1 under the target). Main cost drivers and savings worth trying:

- The largest lines are the primary lithium cell and holder (USD 9), the LoRaWAN module (USD 9), the electronics board and small parts (USD 8), the ultrasonic transducer with driver (USD 7) and the enclosure (USD 6).
- Making the design constructable (BNL-DDR-003) took the parts from USD 55 to USD 59, adding box fixings (USD 2.50) and printed sensor mounts and window (USD 1.50) and respecifying lines 1, 2, 3, 6, 7 and 9.
- The external lid antenna for steel containers would add about USD 8 and bring the estimate to USD 67, USD 7 over the target. Steel containers are left out of the first pilot (decided 2026-10-02), so it is not in the estimate.
- Savings worth trying: confirm prices at TRL 4, and a cheaper generic box.

## Decisions made

| Date | Decision | Decided by | Record |
| --- | --- | --- | --- |
| 2026-09-25 | TRL 2 review items D1 to D10: communal containers first, ultrasonic plus ToF, C cell, LoRaWAN on RAK3172, FieldNode and TwinKit reuse, 80 % and 1 h defaults, heat alert, lid mounting with four tamper bolts, stock IP67 box, no budget change | Amish: "i accept all your recommendations, go with them across all repos." | [BNL-DDR-001](decisions/0001-trl2-review-decisions.md), [BNL-DDR-002](decisions/0002-recommendations-accepted.md) |
| 2026-09-25 | 2 mm 5052-class aluminium bracket; R6 upper limit 70 °C with the RAK3172-T for cold sites; heat rate rule counted only above 50 °C; 11-byte payload and 5 min temperature reads; 2 h interval at SF12 only; budget stays $60 | Amish, same instruction | [BNL-DDR-002](decisions/0002-recommendations-accepted.md), N1 to N6 |
| 2026-09-30 | Design for construction: box held on four studs and standoffs, no tabs, M6 x 20 bolts, 55 mm box, prototyping board on standoffs, printed sensor mounts, vent, plugged sensor leads | Made under Amish's 2026-09-30 instruction to make the design physically buildable ("fix the design assumptions to match and be physically feasible"); open for his review. The changes themselves were accepted on 2026-10-02 (below) | [BNL-DDR-003](decisions/0003-design-for-construction.md) |
| 2026-10-02 | Design for construction accepted: the changes P1 to P11 (box on studs and standoffs, no tabs, M6 x 20 bolts, 55 mm box, prototyping board, printed sensor mounts, vent, plugs), as made | Amish: "i approve your recommendations for all 555 open decisions." | BNL-DDR-003 |
| 2026-10-02 | Cell swap: accepted that a swap means lowering the electronics board on its four screws, since the cell lasts about 16 years | Amish: "i approve your recommendations for all 555 open decisions." | BNL-DDR-003, A2 |
| 2026-10-02 | Steel containers are left out of the first pilot, which uses plastic containers only; the external lid antenna is revisited once the link loss inside a steel container has been measured | Amish: "i approve your recommendations for all 555 open decisions." | BNL-DDR-001 and BNL-DDR-002, O1 |
| 2026-10-02 | First partner to approach: a municipal waste service or its contractor using EN 840 plastic communal containers in a city with public LoRaWAN coverage, by default a European city on the EU868 band; ask how the containers are washed before committing | Amish: "i approve your recommendations for all 555 open decisions." | BNL-DDR-001 and BNL-DDR-002, O2 |
| 2026-10-02 | Galvanic isolation: nothing fitted for the prototype; for deployments the plate is anodised before the studs are pressed in | Amish: "i approve your recommendations for all 555 open decisions." | BNL-DDR-002, Consequences; review note 2026-09-25 |
| 2026-10-02 | Pilot data layer: TwinKit, feeding a standard open-source vehicle routing tool; a city system only if the pilot partner already runs one | Amish: "i approve your recommendations for all 555 open decisions." | BNL-PRC-001, open questions |
| 2026-10-02 | Fill-rate estimate: left to the server; the spare payload byte stays free | Amish: "i approve your recommendations for all 555 open decisions." | BNL-PRC-001, open questions |
| 2026-10-02 | Renders: the 45 degree pose and the street bin accepted for renders only; the device label added as a note under BOM line 1; the renders are redrawn to the constructable design at the next render session | Amish: "i approve your recommendations for all 555 open decisions." | Review note 2026-09-26, items 1, 2 and 7 |

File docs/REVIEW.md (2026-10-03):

# Review note: BinLevel

## Session 2026-09-25: /populate to a strong TRL 2

### What was done

- `docs/01-problem.md` (BNL-PRB-001 v0.2): problem, why it matters (cited), users and context, target containers, operating environment, constraints (including privacy and LoRaWAN airtime rules), out of scope, prior work with sources, open questions; co-design checklist kept.
- `docs/03-requirements.md` (BNL-REQ-001 v0.2): 16 measurable requirements (R1 to R16) with targets, verification and concept status; assumptions.
- `docs/02-concept.md` (BNL-PRC-001 v0.2): how it works, numbered components, energy budget, radio airtime, measurement geometry, mass and cost, proposed design choices, safety, open questions.
- `cad/src/concept_media.py`: massing model of the lid-mounted sensor unit (nine BOM parts) with an 1,100 L communal container shown in section, waste, pavement, an illustrative ultrasonic beam and a 1.75 m person as context. The sensor is modeled at the origin and the context is shifted, because the kit's cutaway cutter is centered on z = 0.
- `media/`: `hero.png`, `concept-blueprint.png`, `.pdf` and `.svg`, `cutaway.png`, `exploded.png` with BOM callouts, `flow.png` (data flow, estimates), `model.glb` and `viewer.html`. Temporary `media/_views*` folders removed.
- `bom/bom.csv`: nine lines numbered to match the exploded view, with indicative USD prices; `bom/bom-notes.md` updated.
- `README.md`: hero image and links line; Concept rationale, Burning platform, Where it could be used (by industry, by country or region), What sparked the idea expanded with cited figures; Problem, Concept and Key components updated; Safety section added.
- `docs/pdf/`: branded PDFs of the three controlled documents.

### Key results (estimates, to be checked at TRL 3)

| Quantity | Estimate | Requirement |
| --- | --- | --- |
| Range coverage | Ultrasonic 0.25 to 1.5 m plus ToF 0.03 to 0.4 m | R1 met by design |
| Reading and report interval | Ranging every 15 min; uplink every 1 h (SF9) or 2 h (SF11 to SF12); alert at once on threshold | R3 met |
| Daily charge use | about 0.61 mAh (SF9) to 0.76 mAh (SF12) | |
| Battery life, C cell | about 23 years (SF9) to 18 years (SF12); seals limit life, so 10 years is the design target | R4 met on paper |
| Battery life, AA cell option | about 10 years (SF9) to 7 years (SF12) | R4 minimum met |
| Uplink airtime | about 5 s per day (SF9 hourly); about 18 s per day (SF12, 2-hourly); TTN limit 30 s | R10 met on airtime |
| Mass and size | about 250 g; 150 x 80 x 63 mm below the lid | R16 met |
| Parts cost | about $55 per sensor, gateway excluded | R14 met, within $60 budget |

Requirements not met or at risk:

- **R2 (accuracy on real waste) at risk:** uneven surfaces, bags and cardboard scatter the echo; no data yet.
- **R5 (IP69K for pressure washing) not met:** the stock enclosure is IP67.
- **R10 (radio) at risk in steel containers:** an internal antenna under a steel lid will be heavily shielded; an external antenna is needed.
- **R6 and R7 unverified:** transducer and ToF window condensation, and shock from tipping, are not yet assessed.

### Proposed, awaiting Amish

Update 2026-09-25: items 1 to 7 are "Decided by Amish, 2026-09-25: go with recommendation" (BNL-DDR-001, BNL-DDR-002). Items 8 and 9 had no recommendation and remain "Proposed, awaiting Amish".

1. **First target container.** Options: (a) 660 to 1,100 L four-wheel communal containers; (b) street litter bins of 50 to 240 L; (c) both from the start. Recommendation: (a), because each container serves many households and a lift is costly; (b) follows with the same electronics and a smaller bracket.
2. **Sensing method.** Options: (a) ultrasonic plus near-range ToF (about $5 more); (b) ultrasonic only, with any reading inside the blind zone reported as "full or blocked"; (c) ToF only (cheapest and smallest, but sensitive to a fouled window). Recommendation: (a), because the default 80 % threshold on an 1,100 L container lies inside the ultrasonic blind zone.
3. **Cell size.** Options: (a) C-size Li-SOCl2 (about $9, about 18 years worst case); (b) AA-size (about $4, about 7 years worst case). Recommendation: (a) for margin in cold climates and a 10-year service interval; revisit (b) for litter bins.
4. **Radio.** Options: (a) LoRaWAN on an STM32WL-class module shared with FieldNode; (b) NB-IoT (no gateway, but a SIM subscription per bin); (c) both variants. Recommendation: (a).
5. **Relationship to FieldNode and TwinKit.** Proposed: reuse FieldNode's radio module family, payload conventions and decoder, but not its enclosure, panel or cell; use TwinKit as the reference gateway and data layer. Both repos should be checked for consistency when their READMEs settle.
6. **Default fill threshold and reporting interval:** 80 % and 1 h (2 h at SF11 to SF12).
7. **Temperature alert:** 70 °C or a rise of 15 K in 15 min, as a maintenance aid only.
8. **Steel containers:** external lid antenna as an optional variant, or exclude steel containers from the first pilot.
9. **First partner and region for co-design and a pilot.**

No change to `project.yaml`: the pitch and problem remain accurate, and the parts cost is within `budget_usd` ($60).

### Safety concerns

- Primary lithium (Li-SOCl2) cell: must never be charged; fused; can vent toxic, corrosive gas or ignite if crushed, shorted or overheated; must be recycled, not binned.
- Sharp objects, needles and biological waste inside bins during installation and service; sharp edges on drilled lids.
- Bin fires: the unit adds a lithium cell to a fire-prone location, and its temperature alert must not be presented as fire detection.
- Work near collection trucks' lifting gear.

### Problems and notes

- The kit's `cutaway_parts` builds its cutter centered on z = 0, so parts far above the origin were not cut. The model keeps the sensor at the origin and shifts the context instead. Worth fixing in the kit (suggestion only).
- The hero note line is generated by the kit and reads "Grey: ... teal cone: ultrasonic beam (illustrative) for scale"; the beam is not a scale reference. Cosmetic.
- WebSearch was unavailable; every cited figure was checked by fetching the source page. No independent (non-vendor) study of collection savings from fill sensors was verified, so vendor savings figures appear only as labeled vendor claims in the problem statement, not in the burning platform.
- The legacy `cad/src/model.py` placeholder is untouched (TRL 3 work).

### Recommended next step

Review this note and the media, then decide items 1 to 3. If approved, run `/advance-trl3` to check the energy budget against named part datasheets, the link budget through plastic and steel lids, and the blind-zone geometry, and to produce the parametric model and drawing sheet.

## Session 2026-09-25: TRL 3

### What was done

- `docs/decisions/0001-trl2-review-decisions.md` (BNL-DDR-001 v0.1): ten items (D1 to D10) adopted as recommended for TRL 3 under Amish's 2026-09-25 instruction, open for his review; two items (O1, O2) remain "Proposed, awaiting Amish".
- `docs/04-calcs/01-sizing.md` (BNL-CAL-001 v0.1) and `docs/04-calcs/sizing.py`: measurement geometry, instrument accuracy, energy and battery life, supply voltage and pulses, airtime and payload, link budget, timing, lid temperature, mass, shock and cost, with a results table for R1 to R16. The script imports the model and reads the BOM and budget; every quoted number carries a tag from its output.
- `cad/src/model.py`: parametric build123d model of the nine BOM parts and a lid patch, with `PARAMS` and `derived()`. Exports `cad/step/` and `cad/stl/` for `binlevel-assembly`, `sensor-unit` and `bracket`.
- `cad/src/sheets.py` and `cad/drawings/BNL-DWG-001.svg`, `.pdf` and `.png`: general arrangement at Rev P1, 1:2, marked "CONCEPT, NOT FOR FABRICATION" and "PRELIMINARY, NOT FOR FABRICATION". The concept blueprint keeps BNL-DWG-010, so DWG-001 was free.
- `bom/bom.csv` and `bom/bom-notes.md`: all nine lines priced with a supplier or supplier type; total $55.00 against the $60 budget.
- `cad/src/concept_media.py` now builds from `model.py`; all media refreshed (hero, blueprint, cutaway, exploded, flow, GLB viewer), checked by eye, and temporary `media/_views*` folders removed.
- BNL-PRB-001, BNL-PRC-001 and BNL-REQ-001 moved to v0.3; `README.md` and `project.yaml` (trl: 3, trl_target: 3, evidence list) updated; PDFs rebuilt in `docs/pdf/`.

### Requirements at TRL 3 (BNL-CAL-001, Table 6)

| Status | Requirements | Key value |
| --- | --- | --- |
| **Not met** | R5 sealing | Stock IP67 box; IP69K not reached |
| **Not met** | R10 radio, steel containers | Internal antenna: about 0.35 km at SF12 with 10 dB fade margin; HDPE containers 0.8 km (SF9) to 1.3 km (SF12) |
| **Not met** | R16 mass | About 435 g against 400 g (1.5 mm stainless bracket 183 g); size met at 150 x 80 x 61 mm |
| At risk | R2 accuracy on waste | Instrument error 9.6 mm (ultrasonic), 20 mm (ToF) of 101 mm; waste surface unknown |
| At risk | R6 climate range | Dark lid about 67 °C on a 40 °C day; standard module rated only to -20 °C |
| At risk | R9 heat alert | Latency 7.5 min with 5 min reads, but sun through cloud raises the unit 15.4 K in 15 min |
| Not verifiable at TRL 3 | R7 shock, R12 install time | 85 N at 20 g against about 4,200 N per bolt |
| Met | R1, R3, R4, R14 (calculation); R8, R11, R13, R15 (design) | Alert 17.5 min; 16.3 years on a C cell at SF12; $55.00 |

Key numbers: worst-case draw 35.7 µA including self-discharge; 1.48 s per SF12 uplink and 20.8 s per day; transducer face 1.01 m above the floor and 80 % fill 0.20 m below it.

Changes to the TRL 2 concept that follow from the calculations: payload 12 to 11 bytes (US915 DR0 limit); nanopower regulator on the carrier (fresh cell 3.67 V against the module's 3.6 V maximum); temperature read every 5 min so the heat alert meets 15 min; cell strapped in its holder; bracket modeled at 1.5 mm, the thinnest in the TRL 2 range. TRL 2 life and mass estimates were optimistic (18 years and 250 g became 16.3 years and 435 g).

### Decisions recorded (BNL-DDR-001)

Decided by Amish, 2026-09-25: go with recommendation (previously adopted for TRL 3, open for his review): D1 660 to 1,100 L communal containers first; D2 ultrasonic plus ToF; D3 C-size Li-SOCl2 cell; D4 LoRaWAN on an STM32WL-class module; D5 reuse FieldNode's radio family, payload conventions and decoder, with TwinKit as reference gateway; D6 80 % threshold and 1 h interval (2 h at SF11 and SF12); D7 heat alert at 70 °C or 15 K in 15 min, maintenance aid only; D8 lid underside mounting; D9 stock IP67 enclosure; D10 no change to budget, pitch or problem (none was recommended).

### Still awaiting Amish

Update 2026-09-25: items 3 to 7 are "Decided by Amish, 2026-09-25: go with recommendation" (BNL-DDR-002). O1 and O2 remain "Proposed, awaiting Amish".

1. **O1, steel containers.** (a) External lid antenna variant (about $8, total $63.00, over budget) or (b) exclude steel containers from the first pilot. No recommendation was made.
2. **O2, first partner and region** for co-design and a pilot; also sets the radio plan. No preference stated.
3. **New, R16 mass.** Options: (a) 2 mm aluminium bracket, unit about 334 g; (b) relax R16 to 450 g and keep stainless; (c) perforated stainless bracket. Recommendation: (a). Decided by Amish, 2026-09-25: go with recommendation; applied.
4. **New, R6 upper limit.** Recommendation: raise to 70 °C to match dark lids in hot sun, and name the RAK3172-T for cold sites. Decided by Amish, 2026-09-25: go with recommendation; applied.
5. **New, R9 rate-of-rise rule.** Recommendation: count the 15 K rise only when the temperature is already above 50 °C, keeping the 70 °C absolute alert. Decided by Amish, 2026-09-25: go with recommendation; applied.
6. **New, payload of 11 bytes and 5 min temperature reads.** Applied to the design basis because R10 (US915) and R9 (15 min) require them. Decided by Amish, 2026-09-25: go with recommendation.
7. Suggestion only: SF11 hourly uses 21.4 s a day, inside TTN's 30 s, so the 2 h stretch could apply at SF12 only. Decided by Amish, 2026-09-25: go with recommendation; applied.

### Cross-repo consistency

- FieldNode (FND REVIEW, TRL 3): STM32WL-class module, LoRaWAN, TwinKit first; consistent with D4 and D5. FieldNode's 20-byte payload exceeds the 11-byte US915 DR0 limit found here; FieldNode's own rule stretches the interval from SF10. Noted, FieldNode not edited.
- TwinKit (TWK REVIEW): 8-channel LoRaWAN concentrator; consistent. Its budget question (O1 there) does not affect BinLevel, whose gateway is outside the BOM.

### Safety concerns

- Li-SOCl2 cell: never charge; fused; strapped so it cannot shake loose under the emptying shock; can vent toxic, corrosive gas if crushed, shorted or overheated; recycle, never bin.
- Hot lids: about 67 °C on dark lids in hot sun, still below the cell's rating but hot to touch during service.
- The heat alert may give false alarms (R9) and must never be presented as fire detection.
- Sharp objects and biological waste in bins; deburr drilled lids; keep clear of truck lifting gear.

### Gaps and notes

- No citations were flagged as unchecked in the TRL 2 note. WebFetch confirmed the RAK3172 supply range, sleep current and temperature ratings, the VL53L1X field of view and 4 m maximum, and the TTN note on the US915 400 ms dwell limit. The 11-byte US915 DR0 limit is from the LoRaWAN Regional Parameters and could not be re-fetched this session (the TTN page request was not approved in time). The JSN-SR04T range, beam angle and temperature rating are estimates, not checked against a datasheet.
- The kit's cutaway cuts at the mean Y of the parts; with the sensor at the origin and the container shifted, the section shows the cell, board, module, transducer and antenna, as at TRL 2. The hero note line is generated by the kit and ends "for scale" after the beam cone, which is not a scale reference (cosmetic, kit unchanged).
- Existing material beyond TRL 3: `build-log/README.md` (scaffold) is present, untouched and not extended. `electronics/` and `firmware/` are empty. The payload layout in BNL-CAL-001 is a sketch, not firmware.

### Recommended next step

TRL 4 is on hold by Amish's instruction; this repo stops at TRL 3. Amish's review is needed on D1 to D10, on O1 and O2, and on new items 3 to 6 above. For the record only, TRL 4 would need: a bench build of the sensor unit; a lab test report (TST, `environment: lab`) covering ranging on real waste in a container against dip readings, sleep and uplink current, cold-start at -20 °C, link loss inside HDPE and steel containers, lid temperature in sun, and shake and drop of the fixing; and build log entries. None of this has been started.

## Session 2026-09-25: recommendations accepted

Amish wrote on 2026-09-25: "i accept all your recommendations, go with them across all repos." Every item with a recommendation is now "Decided by Amish, 2026-09-25: go with recommendation", recorded in `docs/decisions/0002-recommendations-accepted.md` (BNL-DDR-002 v0.1). TRL stays at 3.

### Decisions applied and what changed

| Item | Decision | Before | After |
| --- | --- | --- | --- |
| D1 to D10 (BNL-DDR-001) | As recommended | Adopted for TRL 3, open for review | Decided; BNL-DDR-001 to v0.2; no design change |
| R16 mass (new item 3) | (a) 2 mm 5052-class aluminium bracket | 1.5 mm stainless, bracket 183 g, unit 435 g, R16 not met | 2.0 mm aluminium, bracket 83 g, unit 334 g, R16 met; envelope 61.0 to 61.5 mm below the lid; shock load 85 to 66 N |
| R6 upper limit (new item 4) | Raise to 70 °C; RAK3172-T for cold sites | -20 to +60 °C | -20 to +70 °C; dark lid 67 °C now inside the limit (3 K margin); still at risk on the transducer rating |
| R9 rate rule (new item 5) | Count the 15 K rise only above 50 °C; keep 70 °C | Sun step raises the unit 15.4 K, false alarm, at risk | Unit about 43 °C under cloud (below the gate); worst rise above the gate 10.9 K; met on paper |
| Payload and reads (new item 6) | Keep 11 bytes and 5 min reads | Applied, open for review | Decided |
| Interval stretch (suggestion 7) | 2 h at SF12 only | 2 h at SF11 and SF12 | 1 h to SF11 (21.4 s a day), 2 h at SF12 (20.8 s a day); worst-case life unchanged at 16.3 years |
| Budget | No change recommended | $60 | $60; parts $55.00 |

Files changed: `cad/src/model.py` (plate 2.0 mm, `plate_mat` aluminium) with STEP and STL re-exported; `bom/bom.csv` item 2 and `bom/bom-notes.md`; `cad/src/sheets.py` and BNL-DWG-001 at Rev P2; `cad/src/concept_media.py` key figures and all media regenerated; `docs/04-calcs/sizing.py` (R6 range, new H3 and H4, material-aware mass) and BNL-CAL-001 v0.2; BNL-REQ-001, BNL-PRC-001 and BNL-PRB-001 v0.4; README (Concept, Key components, decision links, new "What sparked the idea"); `project.yaml` evidence list (budget, pitch and problem unchanged).

### Requirement status (BNL-CAL-001 v0.2)

| Status | Requirements |
| --- | --- |
| **Not met** | R5 (stock IP67, not IP69K); R10 in steel containers (about 0.35 km at SF12 with the internal antenna) |
| At risk | R2 accuracy on real waste; R6 climate range (3 K margin at 70 °C; transducer rating unconfirmed) |
| Not verifiable at TRL 3 | R7 shock and loosening; R12 installation time |
| Met | R1, R3, R4, R9, R14, R16 by calculation; R8, R11, R13, R15 by design |

### Still awaiting Amish

1. **O1, steel containers:** external lid antenna ($63.00, over budget) or exclude steel containers from the first pilot. No recommendation.
2. **O2, first partner and region** for co-design and a pilot (sets EU868, US915 or IN865). No preference stated.

### Cross-repo actions

- **FieldNode:** its 20-byte payload exceeds the 11-byte US915 DR0 limit, and its interval stretch starts at SF10. Raise with FieldNode so the shared payload conventions and decoder (D5) fit US915 DR0. FieldNode not edited.
- Kit (suggestion only): the cutaway cutter centers on z = 0, and the hero note ends "for scale" after the beam cone. Not edited.

### Other changes this session

- README "What sparked the idea" rewritten: the starting point is now Philadelphia's 2009 BigBelly rollout and the City Controller's July 2010 report (collections averaged about 10 a week against a promised five; about $3,700 per unit), cited to the US EPA and NBC10 Philadelphia. The earlier text about a review of the lab's research areas was removed.
- All PDFs, drawings and media regenerated with the designmolecule.com footer.

### Notes and suggestions

- Stainless bolts through an aluminium plate outdoors invite galvanic corrosion around the holes; an anodized plate or insulating washers should be considered. Not applied.
- The gated rate rule means a fire starting from a cool bin is reported only at 70 °C or once above 50 °C; the alert remains a maintenance aid, never fire detection.

### Safety

Unchanged: the Li-SOCl2 cell must never be charged, shorted or crushed and must be fused, strapped and recycled; bins hold sharps and biological waste; hot dark lids (about 67 °C); keep clear of truck lifting gear; the heat alert is not fire detection.

### TRL 4

TRL 4 remains on hold by Amish's instruction. No build, test, PCB, firmware or purchasing work was started.

## Session 2026-09-26: product appearance model and photoreal renders

Amish chose this repo for the first batch of product renders on 2026-09-26.

### What was done

- `cad/src/product_model.py` (new): `product_parts()`, `TITLE` and `RENDER_VIEWS` (hero, exploded, detail) for the kit's photoreal renderer. It imports PARAMS and derived() from `cad/src/model.py` and keeps every main dimension and interface: enclosure envelope and split height, sensor apertures, bracket plate, tabs and bolt pattern, lid thickness, board, module, cell and antenna positions. It adds:
  - enclosure with rounded corners and filleted edges, a parting-line groove with the cover gasket showing, four cover screws in counterbores and matching bosses;
  - sealed ultrasonic probe with seal ring and inner lock ring; ToF window (clear) with seal ring, spacer, breakout board and sensor chip;
  - ePTFE pressure vent on the side wall; a device label with a QR code, print lines and a teal band (#0F766E);
  - aluminium bracket with filleted tab corners; tamper-resistant button-head bolts with pin-hex sockets, sealing washers and nyloc nuts;
  - carrier board with ICs, buffer capacitor and connectors; LoRaWAN module with shield can and u.FL; C cell with terminals, holder and a fabric retaining strap; flexible antenna with trace;
  - context: the upper part of a simple street bin with its hinged lid opened 45 degrees, so the sensor face shows.
- `README.md`: hero image now `media/render-hero.png`; "Exploded render" link added at the start of the links line. The render files are produced later by the orchestrator.
- Self-check previews (matplotlib, clear parts omitted) were reviewed outside the repo.

### Differences from model.py (Proposed, awaiting Amish)

1. **Render pose.** The unit and lid are turned together by 45 degrees about the lid hinge (a line parallel to Y) so the sensor face is visible; all sizes and relative positions are unchanged. The exploded and detail views show the unit at the same angle. Recommendation: accept for renders only.
2. **Context bin.** The renders show a compact street bin (250 x 290 mm lid, 85 mm of body below the rim) instead of the 1,100 L container that PARAMS describes for the calculations, so the sensor fills more of the frame. Recommendation: accept; the pitch covers communal and street bins, and the concept media keep the 1,100 L container.
3. **Sealing washers.** An 18 mm sealing washer (BOM 2) sits under each bolt head, which raises the heads 1.2 mm above the model.py position. Recommendation: add the washer to model.py at the next CAD update.
4. **Bolt shank.** In model.py the bolt shank runs to z = 58 mm, 2.7 mm above the top of the head (z = 55.3 mm). The appearance model ends the shank at the head. Recommendation: correct model.py.
5. **Nyloc nuts.** Placed directly under the bracket (z = 39 to 45 mm); in model.py the nut (z = 42 to 47 mm) overlaps the 2 mm plate. Recommendation: correct model.py.
6. **Board corners.** The carrier board corners are notched around the cover screw bosses that a stock IP67 box has; model.py shows a full 105 x 55 mm rectangle. Recommendation: keep as an open item for the board outline against the chosen enclosure; no layout work until TRL 4 is released.
7. **Label and cover screws.** The device label (QR code for the device identity) has no BOM line; the four cover screws are counted with the stock enclosure (BOM 1). Recommendation: add the label as a note under BOM 1 if Amish wants it in the design.

### Scope and TRL

This is an appearance model only: no tolerances, no fabrication detail, no PCB layout. `trl` stays 3 and TRL 4 remains on hold. `model.py`, the BOM and the controlled documents were not changed.

## Session 2026-09-27: kit 1.5.0 and image quality

- Kit 1.5.0 synced: STANDARDS v1.5 (sections 12 to 15: product renders, storefront images and image quality, public release, authorship and signing), `.kit/cards.py`, `.kit/image_qc.py`, `.kit/release_gate.py`, issue templates, and the `/render-product` and `/release` commands. `CLAUDE.md` now matches `.kit/CLAUDE.md`.
- Every `media/render-*.png` recaptioned from its original render with the new layout: the title, concept label and repository sit in a band above the render and the view note in a band below it, each line wrapped to the image width, so no text overlaps other text or the render or runs off the image. `media/card.png` and `media/social-preview.png` regenerated with the same rules.
- `python .kit/image_qc.py` and `python .kit/release_gate.py` pass. trl stays 3.

## Session 2026-09-30: kit 1.7.0, design for construction and prototype build plan

Amish approved the FieldNode build plan format on 2026-09-30 and asked for it across all repos, with outstanding decisions kept out of the build plan and in a separate design decisions register.

### What was done

- Kit 1.7.0 installed (`.kit/`, `.claude/commands/`); `CLAUDE.md` now matches `.kit/CLAUDE.md`.
- Constructability review of `cad/src/model.py` with build123d. The model now builds every component by name (`build_components()`) and runs 192 constructability checks (`python cad/src/model.py --check`): no overlaps, 32 required contacts, one sealed gap, 22 clearances, nothing floating, R16 envelope. All pass.
- `docs/decisions/0003-design-for-construction.md` (BNL-DDR-003 v0.1, Draft, made under Amish's 2026-09-30 instruction to make the design physically buildable; open for his review).
- `bom/bom.csv`: lines 1, 2, 3, 6, 7 and 9 respecified; lines 10 (box fixings) and 11 (printed sensor mounts and window) added; `bom/bom-notes.md` updated.
- `docs/04-calcs/sizing.py` and BNL-CAL-001 v0.3 re-run: geometry, mass, size, fixing (new check J3) and cost. BNL-REQ-001 v0.5 and BNL-PRC-001 v0.5 figures updated.
- STEP and STL re-exported; BNL-DWG-001 to Rev P4; concept media regenerated (`media/hero.png`, `concept-blueprint`, `cutaway.png`, `exploded.png`, `flow.png`, `model.glb`).
- `cad/src/build_plan_media.py` (new): overview, six making sketches BNL-DWG-101 to 106, two drilling layouts, eight joint close-ups, 13 assembly step pictures and a block wiring diagram.
- `docs/05-build-plan.md` (BNL-BLD-001 v0.1) and `docs/06-design-decisions.md` (BNL-DEC-001 v0.1) written; both added to `trl_evidence`; `design_state: constructable` in `project.yaml`; README links line and a "Building the prototype" section added.

### Design changes made for construction (BNL-DDR-003)

1. Box fixing: the end tabs (which held nothing and could not be folded from a flat blank) are removed; four M4 press-in studs in the plate, M4 bonded sealing washers and M4 x 30 hex standoffs clamp the base to the plate.
2. Tamper bolts: M6 x 40 to M6 x 20, with the 18 mm sealing washer under the head and a plain washer and nyloc nut under the plate, 1.5 mm clear of the box (fixes review items 3, 4 and 5 of 2026-09-26).
3. Box height 45 to 55 mm, so the ultrasonic driver board (missing from the model) fits under the electronics board.
4. Electronics board: a 90 x 50 mm prototyping board with bought breakouts on the four standoffs, clear of the stock box's corner towers (resolves review item 6 of 2026-09-26 for the prototype).
5. Transducer held by a printed collar bonded inside the cover, with a grub screw; silicone in the 0.5 mm gap.
6. ToF window: a printed holder bonded over the 11 mm hole holds a 16 mm window disc and the breakout.
7. M8 vent added to the model, in the cover floor facing down.
8. Box modelled as base and cover with towers, cover screws and the gasket in the rim groove; the cover with the sensors faces down.
9. Cell in a holder with a strap through two board slots; module on its breakout; plugs on both sensor leads.

### Key results

- Mass 334 to 350 g (R16 limit 400 g); envelope below the lid 150 x 80 x 71.5 mm (was 61.5; limit 100); transducer face to floor 1,000 mm; parts $55.00 to $59.00 against the $60 value-engineering target ($1.00 under); with the external antenna (O1) $67.00.
- Requirement status unchanged: not met 2 (R5 IP69K, R10 in steel containers), at risk 2 (R2, R6), not verifiable at TRL 3 2 (R7, R12), met 10.

### Proposed, awaiting Amish

All in the design decisions register (`docs/06-design-decisions.md`): review of BNL-DDR-003; the value-engineering note on the $1.00 under the target; the cell swap now needing the board lowered; O1 steel containers; O2 partner and region; galvanic isolation; route planner; fill-rate in the payload; the render choices of 2026-09-26.

### Stale until regenerated on Amish's Mac

The design changed visibly (taller box, no tabs, studs). `media/render-hero.png`, `media/render-exploded.png`, `media/render-detail.png`, `media/card.png`, `media/social-preview.png` and the appearance model `cad/src/product_model.py` (which still draws the tabs and the 45 mm box) are stale. `media/render-hero.png` is also missing from this cloud copy.

### Safety

Unchanged hazards: the Li-SOCl2 cell (never charge, short or heat; the build plan's stop S3 keeps the bench supply and the cell apart, because a supply across a primary cell would charge it); sharps and biological waste in bins; truck lifting gear; the heat alert is not fire detection. New: ASA printing, epoxy and silicone need ventilation.

### Recommended next step

Amish reviews BNL-DDR-003 and the register. TRL 4 (building and testing to the plan) stays on hold.

## Session 2026-10-02: open decisions decided

On 2026-10-02 Amish approved every recommendation written for the open decisions: "i approve your recommendations for all 555 open decisions." Nothing was built or tested; TRL 4 remains on hold.

### Decisions recorded

8 decisions moved from "Open decisions" to "Decisions made" in the design decisions register, dated 2026-10-02. Design for construction (BNL-DDR-003) accepted with its item A2; steel containers left out of the first pilot; a European municipal waste service on EU868 named as the first partner to approach; deployment plates anodised; TwinKit plus an open-source routing tool for the pilot; fill rate left to the server; render choices accepted.

### Documents changed

- `docs/01-problem.md` (BNL-PRB-001 v0.5)
- `docs/02-concept.md` (BNL-PRC-001 v0.7)
- `docs/03-requirements.md` (BNL-REQ-001 v0.7)
- `docs/05-build-plan.md` (BNL-BLD-001 v0.2)
- `docs/06-design-decisions.md` (BNL-DEC-001 v0.3)
- `docs/decisions/0001-trl2-review-decisions.md` (BNL-DDR-001 v0.3)
- `docs/decisions/0002-recommendations-accepted.md` (BNL-DDR-002 v0.2)
- `docs/decisions/0003-design-for-construction.md` (BNL-DDR-003 v0.3)
- `README.md` (not a controlled document)
- `bom/bom-notes.md` (not a controlled document)
- `docs/pdf/`: every controlled document re-rendered.

### Follow-up actions to carry approved decisions into the design

The model, drawings, build plan pictures, BOM quantities and prices, and calculations were not changed in this session. These actions carry the approved decisions into them:

1. Decision 3 (calcs): BNL-CAL-001 sections F and K still call the external lid antenna "open item O1"; at the next re-run, say steel containers are left out of the first pilot (R10 status unchanged).
2. Decision 5 (drawings): BNL-DWG-001 and making sketch of the bracket plate: add a finish note, "prototype: none; deployments: anodise before pressing in the studs".
3. Decision 5 (bom): BOM line 2 description: add the deployment finish (anodised) when the BOM is next revised; no price change for the prototype.
4. Decision 8 (pictures): Redraw the photoreal renders (render-hero, render-exploded, render-detail), card.png and social-preview.png from an updated cad/src/product_model.py at the next render session on Amish's Mac: 55 mm box, no end tabs, studs and prototyping board, 45 degree pose, street bin context.
5. Decision 8 (bom): Device label: kept as a note under BOM line 1 (bom-notes.md); add it to the bom.csv line 1 description at the next BOM revision.
6. Decision 6 (docs): When the firmware and server work starts (TRL 4), document the TwinKit to routing-tool interface; nothing to change at TRL 3.

### Points found in the review

Raised when the recommendations were written (2026-10-01) and not yet acted on:

- Open decision 6 is largely settled already: the problem statement names TwinKit as the proposed data layer and decision D5 adopted TwinKit reuse.
- BNL-DDR-002 and the older REVIEW sections still quote the steel-container variant at USD 63; the current figure is USD 67.
- The photoreal renders, card and social preview still show the 45 mm box, end tabs and full-size board removed by BNL-DDR-003.

## Session 2026-10-02: approved follow-ups carried out

On 2026-10-02 Amish approved carrying out every follow-up action from the open-decision sign-off ("APPROVED CHANGES, COMPLETE THESE") and preparing the render scenes for the photoreal renders on his Mac. Nothing was built or tested; TRL 4 remains on hold.

### Follow-ups carried out

1. **Decision 3 (calcs): done.** BNL-CAL-001 sections F and K no longer call the external lid antenna "open item O1"; they say steel containers are left out of the first pilot and the antenna is revisited once the link loss inside a steel container has been measured. The script's [K2] line now prints the same wording. R10 status unchanged (not met in steel containers; met for HDPE). Section I's corrosion paragraph now records the decided finish. `docs/04-calcs/sizing.py` re-run.
2. **Decision 5 (drawings): done.** Finish note "prototype: none; deployments: anodise before pressing in the studs" added to BNL-DWG-001 (Rev P5) and to the bracket plate making sketch BNL-DWG-101 (Rev P2). The build plan's bracket plate step (section 3.1) gains a matching "Finish" paragraph.
3. **Decision 5 (BOM): done.** BOM line 2 description now states the finish (none for the prototype, anodised before the studs are pressed in for deployments); price unchanged at $5.00.
4. **Decision 8 (pictures): scenes prepared; renders not made here.** `cad/src/product_model.py` rebuilt to the constructable design (55 mm box, no end tabs, four studs with standoffs and sealing washers, prototyping board with breakouts, driver board, printed collar and ToF holder, vent in the cover floor), 45 degree pose and street bin context kept. Render scenes exported to `/home/claude/renders/binlevel` (hero, exploded, detail). The photoreal renders, `media/card.png` and `media/social-preview.png` are redrawn on Amish's Mac next.
5. **Decision 8 (BOM): done.** The device label is now in the BOM line 1 description; no separate line and no price change. `bom/bom-notes.md` updated to match.
6. **Decision 6 (docs): not done, by design.** The TwinKit to routing-tool interface is documented when the firmware and server work starts at TRL 4; nothing to change at TRL 3.

Also tidied while carrying these in: BOM line 8 note no longer calls the steel-container antenna "open item O1"; `bom/bom-notes.md` gave the aluminium plate as 83 g (the tabbed plate) and now gives 63 g; the unused `tab` parameter was removed from `cad/src/model.py` now that the appearance model has no tabs.

### Documents and files changed

- `docs/04-calcs/01-sizing.md` (BNL-CAL-001 v0.4 to v0.5) and `docs/04-calcs/sizing.py`
- `docs/05-build-plan.md` (BNL-BLD-001 v0.2 to v0.3)
- `cad/drawings/BNL-DWG-001` Rev P4 to P5 (`cad/src/sheets.py`); `cad/drawings/BNL-DWG-101` Rev P1 to P2 (`cad/src/build_plan_media.py`, which can now draw one sketch, for example `sheets 101`)
- `bom/bom.csv` (lines 1, 2 and 8) and `bom/bom-notes.md`
- `cad/src/model.py` (`tab` parameter removed; no geometry change); STEP and STL re-exported; constructability checks 192 passed, 0 failed
- `cad/src/product_model.py` (appearance model rebuilt from `build_components()`)
- `cad/src/concept_media.py` (key figure cites BNL-CAL-001 v0.5); concept media regenerated
- `docs/pdf/`: every controlled document re-rendered

### Key results

- No requirement changes status: met 10, at risk 2 (R2, R6), not met 2 (R5 IP69K; R10 in steel containers, which are left out of the first pilot), not verifiable at TRL 3 2 (R7, R12).
- Cost: value-engineering target USD 60; estimated cost of the constructable design USD 59 (USD 1 under the target). With the external lid antenna for steel containers it would be USD 67. `budget_usd` unchanged.
- Mass: the script now prints 349 g ([I1]; 350 g before from rounding of the same geometry), about 350 g, inside R16's 400 g. Envelope below the lid 150 x 80 x 71.5 mm.

### Appearance model: differences from model.py (Proposed, awaiting Amish)

Every part except those listed is the solid from `build_components()` in `cad/src/model.py`.

1. Rounded vertical corners on the box (6 mm) and on the plate (3 mm, as on BNL-DWG-101). Recommendation: accept for renders.
2. A face ring on the probe, the bolt heads with pin-hex sockets and filleted tops, and the LoRaWAN module drawn as breakout, shield can and header pins. Recommendation: accept for renders.
3. The device label with a QR code and teal band on the front of the base (now in the BOM line 1 description). The prototyping board is drawn plain, without its hole grid, to keep the meshes light. Recommendation: accept.
4. The hinge height of the context lid now follows the lid underside in `model.py`, so the taller box sits correctly in the street bin. Recommendation: accept.

### Cross-repo actions

- TwinKit: at TRL 4, document the interface from TwinKit to the open-source routing tool used for the pilot (decision 6). Nothing to change at TRL 3, and no other repo was edited.

### Still open from the review points

- BNL-DDR-002 and the older REVIEW sections still quote the steel-container variant at USD 63; the current figure is USD 67. Left unchanged, because they are historical records; suggestion: add a note to BNL-DDR-002 at its next revision.

### Safety

Unchanged: the Li-SOCl2 cell (never charge, short or heat it); sharps and biological waste in bins; truck lifting gear; the heat alert is not fire detection; ASA printing, epoxy and silicone need ventilation.

### Recommended next step

Render the three views from `/home/claude/renders/binlevel` on Amish's Mac, caption them, and run `python .kit/cards.py .`. TRL 4 stays on hold.

## 2026-10-02: photoreal renders redone on the constructable design

Rendered with Blender Cycles on Amish's Mac from the updated appearance model (`cad/src/product_model.py`); captioned with `.kit/photo_caption.py`; `media/card.png` and `media/social-preview.png` regenerated with `.kit/cards.py`. Views: hero, exploded, detail. image_qc passes. Appearance deviations are those logged above as proposed, awaiting Amish.

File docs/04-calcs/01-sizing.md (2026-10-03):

---
doc_id: BNL-CAL-001
title: BinLevel sizing calculations
project: BinLevel
doc_type: Calculation
version: "0.5"
status: Draft
date: '2026-10-02'
author: Amish Chadha
license: CERN-OHL-S-2.0
revisions:
- version: "0.1"
  date: '2026-09-25'
  author: Amish Chadha
  change: First issue for TRL 3 (measurement geometry, accuracy, energy, supply, airtime and payload, link budget, timing, lid temperature, mass, shock, cost)
- version: "0.2"
  date: '2026-09-25'
  author: Amish Chadha
  change: Recommendations accepted by Amish (DDR-002); 2 mm aluminium bracket, R6 to 70 °C, gated rate-of-rise rule, 2 h interval at SF12 only
- version: "0.3"
  date: '2026-09-30'
  author: Amish Chadha
  change: Design for construction (BNL-DDR-003); 55 mm box, no tabs, studs and standoffs, M6 x 20 bolts; geometry, mass, size, fixing and cost re-run; new check J3
- version: "0.4"
  date: '2026-10-01'
  author: Amish Chadha
  change: Budget treated as a value-engineering target
- version: "0.5"
  date: '2026-10-02'
  author: Amish Chadha
  change: Approved decisions of 2026-10-02 carried in; steel containers left out of the first pilot (sections F and K, no longer open item O1); deployment plates anodised (section I); script re-run, no requirement changes status
---

# BinLevel sizing calculations

On paper, BinLevel meets ten of its sixteen requirements (six by calculation and four by design), has two at risk, misses two and leaves two that only a test can settle. The two misses are R5 (the stock enclosure is IP67, not IP69K) and R10 in steel containers (an antenna inside a steel container loses the link beyond about 0.35 km; steel containers are left out of the first pilot, decided by Amish on 2026-10-02, and the external lid antenna is revisited once the link loss inside a steel container has been measured). The two at risk are accuracy on real waste (R2) and the climate range (R6: a dark lid reaches about 67 °C against the new 70 °C limit, and the transducer's rating is unconfirmed). Version 0.2 applies the recommendations Amish accepted on 2026-09-25 (BNL-DDR-002): a 2 mm aluminium bracket brings the unit from about 435 g to 334 g, so R16 is now met; R6's upper limit rises from 60 to 70 °C; the 15 K rate-of-rise heat trigger counts only above 50 °C, which removes the false alarm when sun breaks through cloud, so R9 is now met on paper; and the routine interval stretches to 2 h at SF12 only. Version 0.3 re-runs the geometry, mass, size, fixing and cost checks for the constructable design of BNL-DDR-003 (a 55 mm tall box held on four studs and standoffs, no tabs, shorter bolts and the parts added for construction): the unit is now about 350 g and 71.5 mm below the lid, still inside R16, parts cost $59.00 against $60, and no requirement changes status. Version 0.5 carries in the decisions Amish made on 2026-10-02: steel containers are left out of the first pilot, so the external lid antenna is no longer an open item, and deployment plates are anodised; the script was re-run and no requirement changes status. Battery life is not a constraint: a C cell lasts about 16 years in the worst radio case. The calculations changed four details of the TRL 2 concept: the payload shrinks from 12 to 11 bytes so that it fits the slowest US915 data rate, the carrier gains a nanopower regulator because a fresh cell exceeds the module's 3.6 V limit, the temperature is read every 5 min so that the heat alert arrives within 15 min, and the cell is strapped rather than held by clips alone. Every number in this note is printed by `docs/04-calcs/sizing.py`; the tag in brackets, for example [C3], is the line of that script's output that carries it.

> **Safety:** These are first-principles estimates for a paper proof of concept. The temperature alert is a maintenance aid and not fire detection. Nothing here replaces checks of the lithium cell's fusing and retention, or safe working practice around bins and collection vehicles. See BNL-PRC-001, Safety.

## Scope and method

The note checks every requirement in BNL-REQ-001 v0.7 against the design in BNL-PRC-001 v0.7 and the parametric model `cad/src/model.py`. The script imports the model's `PARAMS`, `derived()` and part solids, so the container depth, sensor positions, bracket volume and envelope used here are the ones in the STEP files and in drawing BNL-DWG-001. The script also reads `bom/bom.csv` and `budget_usd` in `project.yaml`. Run it from the repo root with `python docs/04-calcs/sizing.py`.

The design case is an 1,100 L four-wheel communal container (DDR-001, D1) with the sensor at the center of an HDPE lid, ranging every 15 min, reporting hourly (2 h at SF12 only, DDR-002) and on alerts (D6), on a LoRaWAN network with a TwinKit or public gateway (D4, D5).

## Assumptions

*Table 1. Main assumptions.*

| Area | Assumption | Basis |
| --- | --- | --- |
| Container | Body 1,300 x 1,000 mm outside, 8 mm wall, inner floor 228 mm and rim 1,300 mm above ground; lid wall 5 mm HDPE | Typical EN 840 1,100 L size (estimate), as in the model |
| Sensing | Ultrasonic blind zone 0.25 m and range to 4 m; effective beam half-angle 15°; ToF used to 0.4 m with a 27° field of view and ±20 mm error including the window | JSN-SR04T-class figures are estimates to confirm; the VL53L1X field of view and 4 m maximum are from the [ST product page](https://www.st.com/en/imaging-and-photonics-solutions/vl53l1x.html) |
| Accuracy | Air temperature known to ±5 K from the on-board sensor; echo detection jitter of half a wavelength; 1 µs timer | Assumed |
| Module | RAK3172: 2.0 to 3.6 V supply, 1.69 µA sleep, -20 to 85 °C (the -T variant -40 to 85 °C) | [RAK3172 datasheet](https://docs.rakwireless.com/product-categories/wisduo/rak3172-module/datasheet/) |
| Currents | Transmit 45 mA at +14 dBm (the datasheet gives only 87 mA at +20 dBm); receive 6 mA for at least 0.1 s or 8 symbols per window; 0.5 s of processing at 3 mA per uplink; sleep 6.0 µA in all (Section C) | Assumed, to be measured |
| Ranging cycle | MCU 3 mA for 0.5 s; ultrasonic module 10 mA for 0.4 s (power-up and five pings 60 ms apart); ToF 20 mA for 0.1 s | Assumed typical module figures |
| Traffic | Two extra uplinks a day for alerts and tip events | Assumed |
| Cell | Li-SOCl2 C (ER26500 class) 8.5 Ah or AA (ER14505 class) 2.6 Ah nominal; 60 % usable for pulses, cold and end-of-life voltage; self-discharge 1 % of nominal a year; 3.67 V open circuit | Typical bobbin-cell data |
| Radio | 11-byte payload plus 13 bytes of LoRaWAN overhead; 125 kHz; coding rate 4/5; 8-symbol preamble; low data rate optimization at SF11 and SF12; US915 slowest rate (DR0, SF10) carries at most 11 bytes of application payload and a 400 ms dwell limit ([TTN](https://www.thethingsnetwork.org/docs/lorawan/regional-limitations-of-rf-use/) for the dwell limit; the 11-byte figure is from the LoRaWAN Regional Parameters and was not re-fetched this session) | LoRaWAN defaults, as in FND-CAL-001 |
| Link | +14 dBm; 0 dBi node antenna with 0.5 dB loss; 2 dBi gateway antenna with 2 dB feeder loss, 30 m high; node 1.3 m high; 6 dB noise figure; Okumura-Hata urban model at 868 MHz; container penalty 10 dB (HDPE, antenna under the lid), 30 dB (steel, antenna inside), 3 dB (steel, external lid antenna); 10 dB fade margin | Screening values; container penalties are assumptions to be measured |
| Lid heat | 40 °C ambient; 900 W/m² sun (100 W/m² under cloud); absorptance 0.9 (dark lid) or 0.5 (light lid); 25 W/m²K above and 5 W/m²K below the lid; unit heat capacity 400 J/K coupled to the lid at 0.75 W/K | Handbook ranges; assumed coupling |
| Shock | 20 g peak when the container strikes the lifter stop; HDPE shear strength 20 MPa; 18 mm washers; M6 stress area 20.1 mm² at 210 MPa | Assumed; the 20 g figure needs measurement |
| Mass | ABS 1.05, stainless 7.9, aluminium 2.68 and FR-4 1.85 g/cm³ applied to model volumes, with ASA 1.07 and PMMA 1.19 g/cm³ for the printed mounts and window; bracket 2.0 mm 5052-class aluminium (DDR-002), no tabs (DDR-003); bought-in parts 174 g (Section I) | Assumed part masses |

## A. Measurement geometry (R1)

- **Depth.** The lid underside is 1,072 mm above the inner floor, and the transducer face sits 1,000 mm above it (1,011 mm before the box grew 10 mm taller under BNL-DDR-003) [A1].
- **Blind zone.** At the adopted 80 % threshold (D6) the waste surface is 200 mm below the face, inside the 250 mm ultrasonic blind zone, so the ultrasonic sensor alone reads fill only up to 75.0 % [A2]. This confirms decision D2.
- **Coverage.** The ToF sensor, used to 400 mm, covers fill from 60.0 % to 100 %, which leaves a 150 mm overlap band where both sensors read and can be compared [A3]. Together they cover the 0 to 1.00 m needed, inside the R1 target of 0.03 to 1.5 m [A4].
- **Beam.** A 15° beam spreads to 0.54 m across at the floor, which averages over uneven waste; the ToF footprint at 0.4 m is 192 mm across [A5]. Mounted at the lid center, the transducer is 492 mm from the nearest wall, so the beam clears the walls down to the floor for half-angles up to 26.2° [A6]. An off-center mount would see echoes from the walls sooner.

## B. Instrument accuracy (R2)

- **Speed of sound.** Over the revised R6 range of -20 to 70 °C the speed of sound runs from 318.9 to 371.3 m/s; without compensation the distance error would be -7.1 % to +8.2 % [B1]. The on-board temperature reading removes most of it.
- **Error budget.** With a 5 K error between the sensor and the air column, the residual is 0.85 %, or 8.5 mm at full depth; echo jitter adds 4.3 mm and the timer 0.17 mm [B2]. The ultrasonic instrument error is 9.5 mm and the ToF error 20 mm, against a ±100 mm allowance (±10 % of depth), so the instruments use 10 % and 20 % of it [B3].
- **Conclusion.** R2 is decided by the waste surface (bags, cardboard, voids and slopes), not by the sensors. No calculation settles it, so R2 stays at risk.

## C. Energy and battery life (R4)

*Table 2. Sleep current [C1].*

| Item | Current |
| --- | --- |
| Module in stop mode (datasheet 1.69 µA, rounded up) | 2.0 µA |
| Accelerometer in wake-on-motion mode (LIS2DH12 class) | 2.0 µA |
| Temperature sensor in shutdown | 0.5 µA |
| Nanopower regulator, load switch and divider leakage | 0.5 µA |
| Buffer capacitor leakage | 1.0 µA |
| **Total** | **6.0 µA** |

- **Daily use.** Sleep takes 0.144 mAh a day; each ranging cycle takes 7.50 mAs, or 0.200 mAh a day at 96 cycles; temperature reads every 5 min add 0.0012 mAh a day [C1]. An uplink takes 3.32 µAh at SF9 and 19.82 µAh at SF12; with two alerts a day the uplinks use 0.086 mAh (SF9, hourly) or 0.278 mAh (SF12, 2-hourly) a day [C2].

*Table 3. Daily charge and life on 60 % of nominal capacity [C3].*

| Case | C cell (8.5 Ah) | AA cell (2.6 Ah) |
| --- | --- | --- |
| SF9, hourly | 0.664 mAh/day; 21.0 years | 0.503 mAh/day; 8.5 years |
| SF12, every 2 h | 0.856 mAh/day; 16.3 years | 0.694 mAh/day; 6.2 years |

- **R4 is met.** The worst case averages 35.7 µA including self-discharge and gives 16.3 years on a C cell and 6.2 years on an AA cell, against 5 years minimum and a 10-year design target [C4]. The TRL 2 estimates (about 23 and 18 years) were optimistic by the extra sleep current and the alert traffic, but the conclusion stands: seals and plastics, not the cell, set the service life. The AA cell meets the 5-year minimum but not the 10-year target, which supports decision D3.

## D. Supply voltage, pulses and heating (R6, R4)

- **Regulator.** A fresh Li-SOCl2 cell rests at 3.67 V, 70 mV above the RAK3172's 3.6 V maximum [D1]. The carrier therefore needs a nanopower 3.3 V regulator (quiescent current well under 1 µA, included in Table 2). This is a change from TRL 2, added to BOM item 6 at no change in its indicative price.
- **Pulse load.** Buffering a whole SF12 uplink (45 mA for 1.48 s) in a capacitor with 0.5 V droop would need 0.133 F [D2], and a supercapacitor of that size leaks several microamperes. The design lets the cell carry the pulse, specifies a cell rated for at least 100 mA pulses, and adds a 1,000 µF low-leakage buffer to cover the voltage delay of a passivated cell. Cold-start voltage delay at -20 °C remains to be tested.
- **Heating is not an option.** A 20 mW heater to keep the ToF window above the dew point would use 133 mAh a day, 156 times the whole budget [D3]. Condensation must be handled by venting, a hydrophobic window and the ultrasonic sensor's tolerance to it.

## E. Airtime, payload and radio rules (R10, R3)

*Table 4. Time on air for an 11-byte uplink (24 bytes on air) at 125 kHz, with two alerts a day [E1].*

| SF | Per uplink | Hourly (s/day) | Every 2 h (s/day) | EU868 1 % off-time |
| --- | --- | --- | --- | --- |
| 7 | 62 ms | 1.6 | 0.9 | 6 s |
| 8 | 113 ms | 2.9 | 1.6 | 11 s |
| 9 | 206 ms | 5.4 | 2.9 | 20 s |
| 10 | 371 ms | 9.6 | 5.2 | 37 s |
| 11 | 823 ms | 21.4 | 11.5 | 82 s |
| 12 | 1,483 ms | 38.6 | 20.8 | 147 s |

- **Payload size.** The TRL 2 concept used 12 bytes. The slowest US915 rate (DR0, SF10) carries at most 11 bytes of application payload, so a 12-byte payload could not be sent from a US915 sensor at the edge of coverage. The payload is cut to 11 bytes, which fits [E2]; the airtimes are unchanged from TRL 2 because the symbol count does not change. At SF10 an uplink takes 371 ms, inside the 400 ms US915 dwell limit [E3].
- **Fair use.** Hourly reporting at SF12 would use 38.6 s a day, over TTN's 30 s, while SF11 hourly uses only 21.4 s. The routine interval therefore stays at 1 h up to SF11 and stretches to 2 h at SF12 only (DDR-002; D6 had stretched it at SF11 as well), which keeps SF12 at 20.8 s [E4]. Battery life is unchanged, because SF12 at 2 h remains the worst case in Section C.
- **Payload layout.** A candidate 11-byte layout, for the decoder shared with FieldNode (D5): 1 byte version and flags (alert, tip, lid, low battery, sensor used), 1 byte fill in 0.5 % steps, 2 bytes distance in millimeters, 1 byte temperature in degrees Celsius (signed), 1 byte lid-open count, 1 byte tip count, 1 byte battery voltage in 10 mV steps above 2.0 V, 2 bytes minutes since the last emptying and 1 byte spare. This is a sketch for review, not firmware.

## F. Link budget (R10)

*Table 5. Link margin at 1 km and range with a 10 dB fade margin [F1, F2].*

| Case | SF9 (143.0 dB budget) | SF12 (150.5 dB budget) |
| --- | --- | --- |
| HDPE container, antenna under the lid (10 dB) | 6.5 dB; 0.80 km | 14.0 dB; 1.30 km |
| Steel container, antenna inside (30 dB) | -13.5 dB; 0.22 km | -6.0 dB; 0.35 km |
| Steel container, external lid antenna (3 dB) | 13.5 dB; 1.26 km | 21.0 dB; 2.06 km |

- Urban path loss at 1 km is 126.5 dB; gateway sensitivity is -129.5 dBm at SF9 and -137.0 dBm at SF12 [F1].
- **Plastic containers** work to about 0.8 km at SF9 and 1.3 km at SF12 with a 10 dB fade margin. A pilot should place gateways within about 1 km of the containers, or accept SF12 and the 2 h interval.
- **Steel containers with the internal antenna do not meet R10:** even at SF12 the range is only about 0.35 km. An external lid antenna would restore 1.3 to 2.1 km. Steel containers are left out of the first pilot, which uses plastic containers only (decided by Amish, 2026-10-02); the external antenna is revisited once the link loss inside a steel container has been measured. R10 stays not met for steel containers.

## G. Timing (R3, R9)

- **Fill alert.** In the worst case the surface crosses 80 % just after a reading: 15 min to the next reading, up to 147 s of EU868 off-time after a previous SF12 uplink, and 1.5 s of airtime give 17.5 min, inside R3's 20 min [G1].
- **Heat alert.** Read only with the 15 min ranging, a heat alert could take 17.5 min, which misses R9's 15 min. Reading the temperature every 5 min (0.0012 mAh a day [C1]) brings it to 7.5 min [G2]. This is a change from TRL 2.

## H. Temperature under the lid (R6, R9)

- **Hot lids.** In 900 W/m² sun at 40 °C ambient a dark lid reaches about 67 °C and a light lid about 55 °C [H1]. The unit is bolted to the lid underside and runs close to lid temperature, so on dark lids in hot climates it exceeded R6's former 60 °C limit. R6's upper limit is now 70 °C (DDR-002), which covers this with 3 K of margin. The module (to 85 °C) and cell tolerate it; the ultrasonic module's rating must be confirmed, so R6 stays at risk.
- **Cold.** The standard RAK3172 is rated to -20 °C, exactly R6's lower limit; the RAK3172-T (-40 to 85 °C) is named for cold sites (DDR-002).
- **False heat alarms.** The lid's time constant is 5.0 min and the unit's 8.9 min. When 800 W/m² sun breaks through cloud, a dark lid rises 24 K and the unit 15.4 K within 15 min [H2], just over the 15 K rate-of-rise trigger (D7). With the original rule the rate trigger could fire on a sunny afternoon with no fire.
- **Gated rate rule (DDR-002).** The 15 K rise now counts only when the unit is already above 50 °C; the 70 °C absolute alert is kept. Under cloud the unit sits at about 43 °C, below the gate, so the sun step does not trigger, and the steady dark lid (about 67 °C) stays below 70 °C [H3]. In the worst case above the gate, a unit already at 50 °C that then sees full sun rises 10.9 K in 15 min, below the 15 K trigger [H4]. R9 is met on paper; the thermal model is a screening estimate and must be checked by measurement. The alert remains a maintenance aid, not fire detection.

## I. Mass and size (R16)

- **Mass.** Enclosure 94 g (base and cover, 55 mm tall), bracket plate 63 g (2.0 mm 5052-class aluminium, no tabs), electronics board 13 g, printed collar and ToF holder with the window 5 g, and bought-in parts 174 g (now including the box fixings, 22 g, and the shorter bolts, 36 g) give 349 g, about 350 g, inside R16's 400 g [I1]. **R16 is met.** Version 0.2 gave 334 g with the 45 mm box and tabs; version 0.1 used a 1.5 mm stainless bracket (unit 435 g). A 2.0 mm stainless plate would make the unit 473 g [I2].
- **Size.** Below the lid the unit measures 150 x 80 x 71.5 mm (61.5 mm before the box grew 10 mm taller), inside the 160 x 90 x 100 mm limit [I3].
- **Corrosion.** The bolts and studs stay stainless. Stainless fixings in wet aluminium can corrode the aluminium around the holes. Nothing is fitted for the prototype; for deployments the plate is anodised before the studs are pressed in (decided by Amish, 2026-10-02). Anodising adds no measurable mass.

## J. Shock and fixing (R7)

- A 20 g shock on the 0.35 kg unit gives 69 N. One washer pulling through the 5 mm HDPE lid needs about 5,655 N and one M6 bolt carries about 4,221 N [J1], so the fixing has a large margin on strength. Loosening under repeated shocks, and IK08 impact, need a test.
- The 50 g cell needs 10 N of retention at 20 g [J2]; the holder is specified with a strap rather than spring clips alone.
- **Box fixing (new in v0.3).** The box and everything in it, about 250 g, hang on the four M4 studs: 49 N at 20 g, or 12 N per stud. The base floor would need about 2,100 N per stud to pull through under a 9 mm sealing washer (ABS shear strength 30 MPa, assumed), and a press-in stud's push-out rating in 2 mm aluminium is taken as about 900 N (to confirm from the maker's data) [J3]. Strength is not the limit; loosening needs a test.

## K. Cost (R14)

- All eleven BOM lines are priced; the parts total is $59.00 against the $60 value-engineering target (`budget_usd`), $1.00 under [K1]. Lines 10 (box fixings) and 11 (printed mounts and window) were added for construction (BNL-DDR-003). The design decisions register lists the cost drivers and savings worth trying.
- An external lid antenna for steel containers (about $8) would take the total to $67.00, $7.00 over the value-engineering target [K2]. It is not in the BOM: steel containers are left out of the first pilot (decided by Amish, 2026-10-02).
- The deployment finish on the bracket plate (anodised, decided 2026-10-02) is not priced for the prototype, which has no finish; line 2 is unchanged at $5.00.

## L. Results against every requirement

*Table 6. Requirement status at TRL 3.*

| ID | Requirement | Target | Value (tag) | Status |
| --- | --- | --- | --- | --- |
| R1 | Range | 0.03 to 1.5 m below the face | 0 to 1.00 m needed; ultrasonic 0.25 to 4 m, ToF to 0.4 m (A2 to A4) | Met (datasheet ranges to confirm) |
| R2 | Accuracy on real waste | ±10 % of depth for 90 % of readings | Instrument 9.5 mm (ultrasonic), 20 mm (ToF) of 100 mm; surface unknown (B3) | At risk |
| R3 | Reporting and alert timing | Uplink at least every 2 h; alert within 20 min | 1 h (2 h at SF12); 17.5 min (G1) | Met |
| R4 | Battery life | 5 years at SF12; 10-year target | 16.3 years (C cell) (C4) | Met |
| R5 | Sealing | IP67 minimum; IP69K where pressure washed | Stock IP67 enclosure | Not met (IP69K) |
| R6 | Climate range | -20 to +70 °C inside the container (was +60 °C) | Dark lid about 67 °C (H1); standard module at its -20 °C limit, RAK3172-T for cold sites; transducer rating unconfirmed | At risk |
| R7 | Lifting, tipping and lid slams | No loosening; IK08 | 69 N against 4,221 N per bolt (J1); 12 N per stud (J3) | Not verifiable at TRL 3 |
| R8 | Emptying and lid events | Tip event with the next uplink | Accelerometer wake-on-motion | Met by design |
| R9 | Heat warning | Alert within 15 min above 70 °C, or on a 15 K rise in 15 min counted only above 50 °C | 7.5 min with 5 min reads (G2); sun step starts at about 43 °C, below the gate (H3); 10.9 K above the gate (H4) | Met on paper (to be measured) |
| R10 | Open LoRaWAN within radio rules | Class A; EU868, US915, IN865; duty cycle and 30 s/day | 20.8 s/day at SF12 (E4); 11 bytes fits US915 DR0 (E2); steel container 0.35 km (F2) | Not met (steel containers, left out of the first pilot); met for HDPE |
| R11 | Privacy | No camera or microphone; limited payload | BOM and 11-byte layout (E) | Met by design |
| R12 | Installation | 10 min or less, four bolts, no cables | Four through-bolts on a 130 x 60 mm pattern | Not verifiable at TRL 3 |
| R13 | Tamper resistance | Inside the lid; tamper-resistant fasteners | Button-head tamper bolts from above | Met by design |
| R14 | Cost | $60 value-engineering target | $59.00 (K1) | Met, within the target |
| R15 | Open and interoperable | Documented payload; open decoder | Candidate layout in Section E; decoder shared with FieldNode (D5) | Met by design |
| R16 | Mass and size | 400 g or less; within 160 x 90 x 100 mm below the lid | About 350 g (I1); 150 x 80 x 71.5 mm (I3) | Met |

Summary: met 10 (R1, R3, R4, R9, R14, R16 by calculation; R8, R11, R13, R15 by design); at risk 2 (R2, R6); not met 2 (R5, R10 in steel containers); not verifiable at TRL 3, 2 (R7, R12). Version 0.1 had met 8, at risk 3 and not met 3.

## Checks against the TRL 2 figures

| TRL 2 claim | TRL 3 value | Change made |
| --- | --- | --- |
| Daily use about 0.61 to 0.76 mAh; life about 23 to 18 years (C) | 0.664 to 0.856 mAh; 21.0 to 16.3 years | Precis and README updated |
| AA cell about 10 to 7 years | 8.5 to 6.2 years | Precis updated |
| 12-byte payload | 11 bytes, so it fits US915 DR0 | Precis, requirements and media updated |
| Uplink airtime about 5 s/day (SF9) and 18 s/day (SF12) | 5.4 and 20.8 s/day with two alerts | Precis updated |
| Mass about 250 g; R16 met | 435 g with stainless (v0.1); 334 g with the aluminium bracket (v0.2); 350 g constructable (v0.3); R16 met | Requirements, precis and README updated |
| 150 x 80 x 63 mm below the lid | 150 x 80 x 61.5 mm (v0.2); 71.5 mm with the 55 mm box (v0.3) | Requirements and precis updated |
| Temperature inside a dark lid up to about 60 °C | About 67 °C on a 40 °C day | Problem statement and requirements note updated |
| 80 % fill about 0.21 m below the lid | 0.20 m below the transducer face | Precis updated |
| Parts cost about $55 | $55.00 (v0.2); $59.00 with the parts added for construction (v0.3) | BOM, precis and README updated |

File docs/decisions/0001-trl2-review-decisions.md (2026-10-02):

---
doc_id: BNL-DDR-001
title: BinLevel TRL 2 review decisions
project: BinLevel
doc_type: Design decision record
version: "0.3"
status: Draft
date: '2026-10-02'
author: Amish Chadha
license: CERN-OHL-S-2.0
revisions:
- version: "0.1"
  date: '2026-09-25'
  author: Amish Chadha
  change: Record the TRL 2 review recommendations adopted for TRL 3 work and the items that remain open
- version: "0.2"
  date: '2026-09-25'
  author: Amish Chadha
  change: Recommendations accepted by Amish (DDR-002)
- version: "0.3"
  date: '2026-10-02'
  author: Amish Chadha
  change: O1 and O2 decided by Amish on 2026-10-02 (recommendations approved, BNL-DEC-001)
---

# 0001: TRL 2 review decisions

- **Date:** 2026-09-25
- **Status:** accepted. Items D1 to D10 were decided by Amish on 2026-09-25 ("i accept all your recommendations, go with them across all repos"): go with recommendation. Items O1 and O2 carried no recommendation then; recommendations were written later and approved by Amish on 2026-10-02 ("i approve your recommendations for all 555 open decisions."), recorded in Table 2 and the design decisions register BNL-DEC-001. See BNL-DDR-002 for the follow-on decisions.

## Context

The TRL 2 review note (`docs/REVIEW.md`, session 2026-09-25, /populate) listed nine items as "Proposed, awaiting Amish", and the design precis BNL-PRC-001 v0.2 listed six key design choices, each with a rationale. On 2026-09-25 Amish asked for this batch of repos to be taken through the usual process with the instruction "you know the drill, nothing gets past TRL 3". He has not reviewed this repo's items one by one. Every item that carried a recommendation is therefore adopted as recommended for TRL 3 work, open for his review. Items without a recommendation stay open, and no choice is made for them.

## Options considered

The options for each item are those listed in `docs/REVIEW.md` (session 2026-09-25, /populate) and in BNL-PRC-001 v0.2, Key design choices.

## Decision

*Table 1. Items decided by Amish.*

| # | Item | Recommendation adopted | Status |
| --- | --- | --- | --- |
| D1 | First target container | (a) 660 to 1,100 L four-wheel communal containers (EN 840 class); street litter bins follow with the same electronics and a smaller bracket | Decided by Amish, 2026-09-25: go with recommendation |
| D2 | Sensing method | (a) Ultrasonic plus near-range ToF, because the 80 % threshold lies inside the ultrasonic blind zone | Decided by Amish, 2026-09-25: go with recommendation |
| D3 | Cell size | (a) C-size Li-SOCl2 for margin in cold climates and a 10-year service interval; AA revisited for litter bins | Decided by Amish, 2026-09-25: go with recommendation |
| D4 | Radio | (a) LoRaWAN on an STM32WL-class module shared with FieldNode | Decided by Amish, 2026-09-25: go with recommendation |
| D5 | Relationship to FieldNode and TwinKit | Reuse FieldNode's radio module family, payload conventions and decoder, not its enclosure, panel or cell; TwinKit as the reference gateway and data layer | Decided by Amish, 2026-09-25: go with recommendation |
| D6 | Default fill threshold and reporting interval | 80 % and 1 h (2 h at SF11 to SF12) | Decided by Amish, 2026-09-25: go with recommendation |
| D7 | Temperature alert | 70 °C or a rise of 15 K in 15 min, as a maintenance aid only | Decided by Amish, 2026-09-25: go with recommendation |
| D8 | Mounting (precis choice 2) | Under the lid, with four tamper-resistant through-bolts | Decided by Amish, 2026-09-25: go with recommendation |
| D9 | Enclosure (precis choice 5) | Stock IP67 enclosure at TRL 2 to 3; potted or IP69K design later | Decided by Amish, 2026-09-25: go with recommendation |
| D10 | Budget, pitch and problem | No change was recommended: `budget_usd` stays $60 and the pitch and problem lines stay as written | Decided by Amish, 2026-09-25: go with recommendation |

*Table 2. Items left open on 2026-09-25, decided on 2026-10-02.*

| # | Item | Options | Status |
| --- | --- | --- | --- |
| O1 | Steel containers | (a) External lid antenna as an optional variant (about $8, which takes the parts cost to $63, over the $60 budget); (b) exclude steel containers from the first pilot. No recommendation was made. | Decided by Amish, 2026-10-02 (recommendation approved): (b), steel containers left out of the first pilot, which uses plastic containers only; the external lid antenna is revisited once the link loss inside a steel container has been measured (BNL-DEC-001) |
| O2 | First partner and region for co-design and a pilot | No preference stated and no recommendation made. The region also sets the radio plan (EU868, US915 or IN865). | Decided by Amish, 2026-10-02 (recommendation approved): first partner to approach is a municipal waste service or its contractor using EN 840 plastic communal containers in a city with public LoRaWAN coverage, by default a European city on EU868; washing practice asked before committing (BNL-DEC-001) |

## Consequences

- BNL-PRB-001, BNL-PRC-001 and BNL-REQ-001 move to version 0.3. The target container, sensing method, cell, radio, thresholds and mounting are no longer described as proposed; they are the design basis for TRL 3, decided by Amish on 2026-09-25.
- No requirement target was relaxed or redefined by these decisions. R3 and R9 now carry the adopted defaults (D6, D7) as the design values.
- The sizing note BNL-CAL-001 checks the design against every requirement. It adds four findings that need Amish's review (see `docs/REVIEW.md`, session 2026-09-25, TRL 3): the unit is about 435 g against the 400 g limit of R16; hot dark lids reach about 67 °C, above the 60 °C of R6; the 15 K rate-of-rise trigger in D7 is at risk of false alarms on sunny days; and the payload is cut from 12 to 11 bytes so that it fits the US915 slowest data rate.
- The recommended budget is unchanged, so no budget figure awaits Amish.
- Update, 2026-09-25: Amish accepted all recommendations. D1 to D10 are decided; the four findings above were resolved by BNL-DDR-002 (aluminium bracket, R6 to 70 °C, gated rate-of-rise rule, 11-byte payload and 5 min reads confirmed).

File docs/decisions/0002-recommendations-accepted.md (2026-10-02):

---
doc_id: BNL-DDR-002
title: BinLevel recommendations accepted
project: BinLevel
doc_type: Design decision record
version: "0.2"
status: Draft
date: '2026-10-02'
author: Amish Chadha
license: CERN-OHL-S-2.0
revisions:
- version: "0.1"
  date: '2026-09-25'
  author: Amish Chadha
  change: Record Amish's acceptance of all recommendations and the changes made in the repo
- version: "0.2"
  date: '2026-10-02'
  author: Amish Chadha
  change: O1 and O2 decided by Amish on 2026-10-02 (recommendations approved, BNL-DEC-001)
---

# 0002: Recommendations accepted

- **Date:** 2026-09-25
- **Status:** accepted. Every item below that carried a recommendation is "Decided by Amish, 2026-09-25: go with recommendation". Items without a recommendation (O1, O2) were decided on 2026-10-02, when Amish approved the recommendations later written for them ("i approve your recommendations for all 555 open decisions."); see Table 2 and BNL-DEC-001.
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

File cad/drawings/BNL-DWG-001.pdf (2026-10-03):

CONCEPT, NOT FOR FABRICATION | BinLevel · github.com/BoujeeEnjinia1701/binlevel

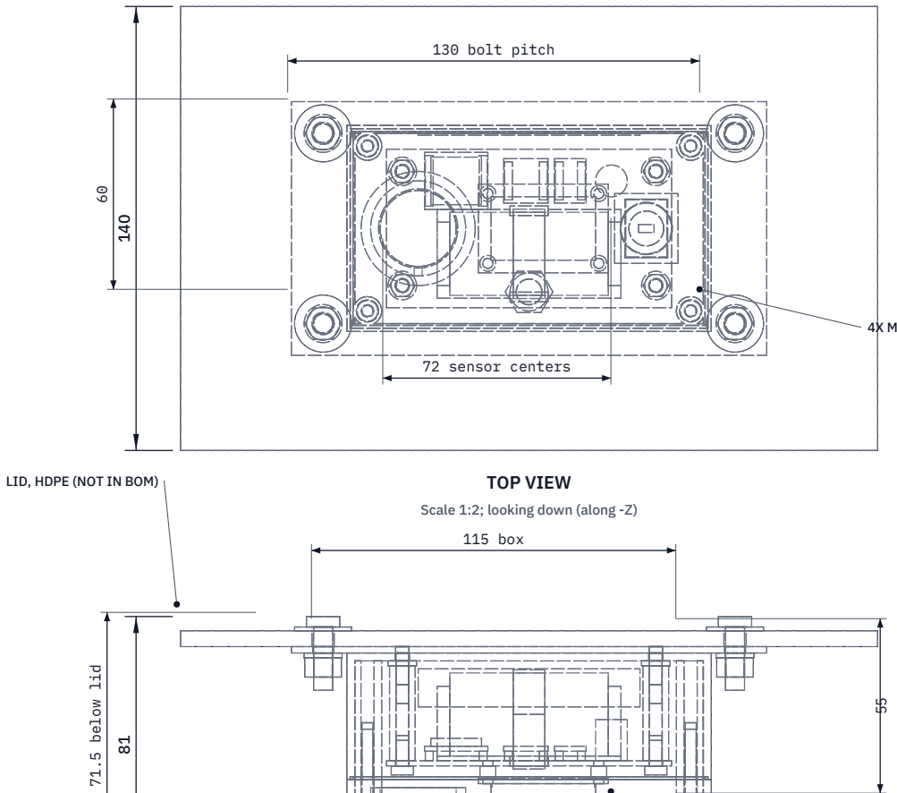
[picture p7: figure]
TOP VIEW; Scale 1:2; looking down (along -Z); 71.5 below lid; 115 box; LID, HDPE (NOT IN BOM); 130 bolt pitch; 72 sensor centers

FRONT VIEW
Scale 1:2; looking at the front (along +Y)

RIGHT VIEW
Scale 1:2; looking at the right side (along -X)

220

3 TRANSDUCER | 4 TOF WINDOW

4X M6 TAMPER BOLT, 7 HOLE IN LID

80 plate

65 box
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

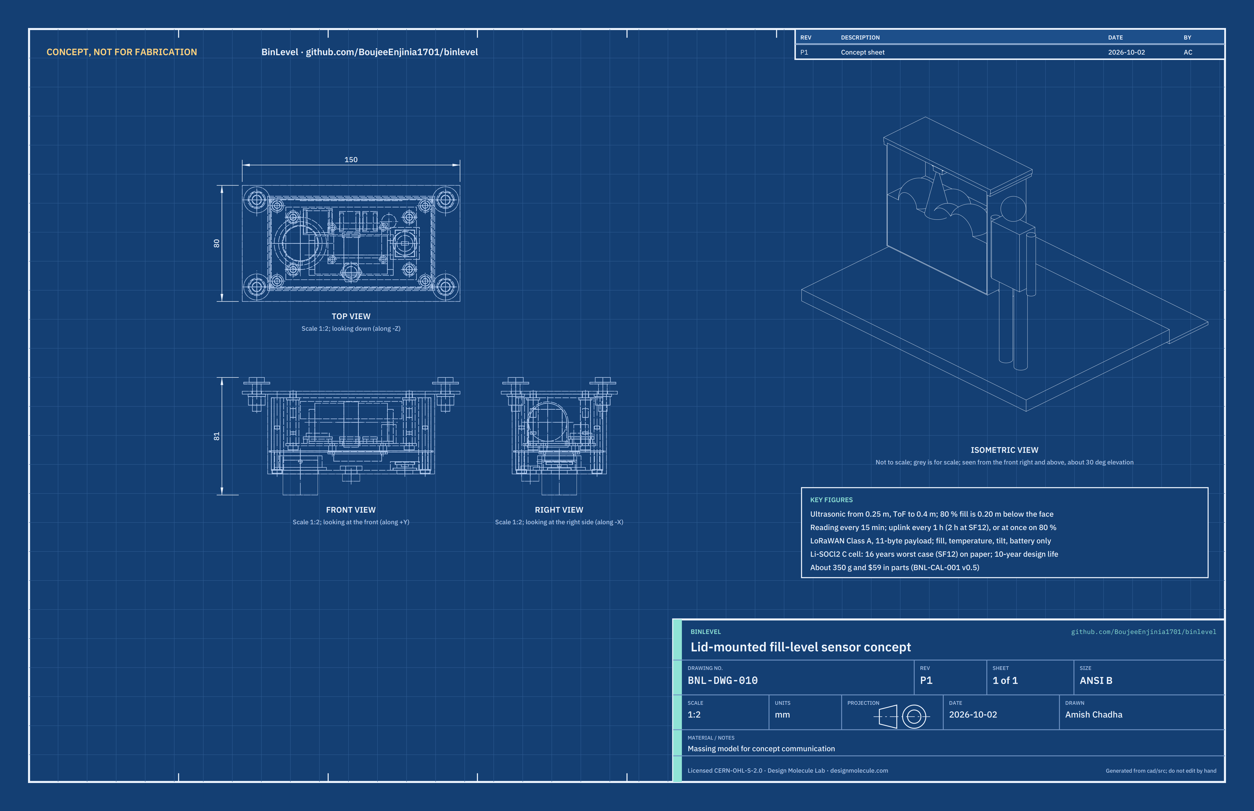
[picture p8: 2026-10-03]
media/concept-blueprint.png

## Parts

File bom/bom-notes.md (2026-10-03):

# BOM notes

- Item numbers match the callouts in `media/exploded.png` and the parts in `cad/src/model.py`.
- Prices are indicative single-unit or small-batch prices in USD for a prototype. Each line names a supplier or supplier type; prices were not re-quoted from a named supplier at TRL 3.
- Total parts cost per sensor is $59.00, $1.00 under the $60 value-engineering target (`budget_usd` in `project.yaml`; BNL-CAL-001 v0.5, section K). The optional external lid antenna for steel containers (about $8) would take it to $67.00, over the target, and is not included: steel containers are left out of the first pilot (decided by Amish, 2026-10-02).
- Design for construction (BNL-DDR-003, 2026-09-30): item 1 is now 55 mm tall; item 2 has no end tabs and M6 x 20 bolts; item 6 is a prototyping board with breakouts for the first prototype; items 10 (box fixings, $2.50) and 11 (printed sensor mounts and window, $1.50) are new.
- TRL 3 changes: item 6 now includes a nanopower 3.3 V regulator (a fresh cell is 3.67 V, above the module's 3.6 V limit) and a 1,000 uF low-leakage buffer; item 7 has a retaining strap; item 5 is named as the RAK3172 (RAK3172-T for cold sites); item 2 was 1.5 mm stainless at TRL 3 v0.1. None changed the indicative prices.
- Mass: item 2 is now a 2 mm 5052-class aluminium bracket (about 63 g without tabs; 83 g with the tabs it had before BNL-DDR-003), decided by Amish on 2026-09-25 (BNL-DDR-002). The unit was about 334 g (now about 350 g after BNL-DDR-003), inside the 400 g limit of R16; the earlier 1.5 mm stainless bracket (183 g) made it about 435 g. The indicative price of item 2 is unchanged at $5.00 (aluminium plate costs about the same as thin stainless for one small part). The bolts stay stainless.
- Item 1: each unit carries a device label with the device identity used at installation; included in the line 1 description, not a separate line, and no price change (decided 2026-10-02; added to `bom.csv` on 2026-10-02).
- Item 2 finish: nothing for the prototype; for deployments the plate is anodised before the studs are pressed in, to isolate the stainless fixings from the aluminium (decided by Amish, 2026-10-02). Now stated in the line 2 description and on drawings BNL-DWG-001 and BNL-DWG-101; no change to the prototype price.
- Not included: the LoRaWAN gateway (shared across many bins; see the lab's TwinKit project, or use a public network such as The Things Network), network server hosting, and installation labor.
- Item 7 is a primary (non-rechargeable) lithium cell. Do not charge it. Recycle spent cells through a battery collection point.

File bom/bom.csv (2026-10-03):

item | qty | spec | supplier | unit_cost_usd | make_buy | notes
1 Enclosure | 1 | IP67 ABS or polycarbonate box 115 x 65 x 55 mm outside, 2.5 mm wall, shallow screw-down cover (about 15 mm deep) with gasket and four corner cover screws into moulded towers. Drilled: 25 mm (transducer), 11 mm (ToF window) and 8.2 mm (vent) in the cover; four 4.5 mm in the base floor for the studs; a device label with the device identity (QR code) on the side of the base, applied at installation | Stock enclosure maker (Hammond 1554 or Bud class, or a generic IP67 box) via an electronics distributor | 6.00 | buy | Indicative price, generic box; 55 mm tall (was 45) so the ultrasonic driver board fits (BNL-DDR-003, P3); a branded IP67 box costs about $8 to $12; IP69K option for pressure-washed bins costs more; device label added to the description (decided 2026-10-02)
2 Aluminium bracket plate and tamper bolts | 1 | 2.0 mm 5052-class aluminium plate 150 x 80 mm, flat, with four 6.6 mm holes on a 130 x 60 mm pattern and four M4 studs (line 10) pressed in; finish: none for the prototype, anodised before the studs are pressed in for deployments; four stainless M6 x 20 tamper-resistant button-head bolts, 18 mm sealing washers under the heads, M6 plain washers and nyloc nuts | Local sheet-metal shop plus fastener supplier | 5.00 | make | Indicative price; aluminium replaces 1.5 mm stainless (BNL-DDR-002); end tabs removed and bolts shortened from M6 x 40 (BNL-DDR-003, P1 and P2); plate about 63 g (BNL-CAL-001 section I); deployment finish anodised (decided 2026-10-02), no change to the prototype price
3 Ultrasonic transducer with driver | 1 | Sealed 40 kHz waterproof transducer (JSN-SR04T class, 3.3 V capable version), 24 mm probe, about 0.25 m blind zone (estimate), with its driver board (about 41 x 28 mm) hung under the electronics board; probe cable shortened to about 0.15 m with its plug | Electronics distributor or online marketplace | 7.00 | buy | Indicative price; temperature rating of the chosen module to confirm (R6)
4 Near-range ToF sensor | 1 | VL53L1X laser ranging breakout, 13 x 18 mm class (27 degree field of view, up to 4 m in the dark), used to 0.4 m, sensor facing down onto the window in the printed holder (line 11) | Electronics distributor or online marketplace (generic breakout) | 5.00 | buy | Indicative price for a generic breakout; branded boards cost about $12 to $15; window fouling unverified
5 LoRaWAN module | 1 | RAK3172 (STM32WLE5) module, 2.0 to 3.6 V, 1.69 uA sleep, on its maker's breakout board for the prototype; RAK3172-T variant (-40 to 85 C) for cold sites; u.FL antenna port; EU868, US915 or IN865 build | RAKwireless store or module distributor | 9.00 | buy | Indicative price; same radio family as FieldNode (DDR-001 D4 and D5)
6 Electronics board and small parts | 1 | For the prototype: perforated prototyping board cut to 90 x 50 mm, standing in for the two-layer carrier PCB, with breakouts and parts: 3-axis accelerometer (LIS2DH12 class, wake-on-motion), temperature sensor, nanopower 3.3 V LDO (fresh cell is 3.67 V), load switch for the sensors, 1,000 uF low-leakage buffer capacitor, switched battery divider, fuse, plug-in headers for the transducer and ToF leads | PCB prototyping supplies plus electronics distributor | 8.00 | make | Indicative price; the carrier PCB layout is TRL 4 work and not started
7 Primary lithium cell and holder | 1 | Li-SOCl2 C size (ER26500 class) 3.6 V, about 8.5 Ah nominal, pulse capable to at least 100 mA; through-board holder with a 10 mm hook-and-loop retaining strap through two board slots; PTC or fuse | Battery distributor (cell from a maker that publishes a datasheet) | 9.00 | buy | Indicative price; AA option about $4; never recharge
8 Antenna | 1 | Flexible 868/915 MHz PCB antenna, adhesive, with u.FL lead, on the inner +Y wall of the base | Electronics distributor | 3.00 | buy | Indicative price; external lid antenna for steel containers (about $8) not included: steel containers are left out of the first pilot (decided 2026-10-02)
9 Gasket and vent | 1 | Cover gasket (with the box); M8 ePTFE pressure-equalizing vent with its nut, in the cover floor facing down | Electronics distributor or vent maker | 3.00 | buy | Indicative price
10 Box fixings | 1 | Four M4 x 12 flush-head self-clinching studs for aluminium sheet; four M4 x 30 aluminium hex standoffs, female both ends, 7 mm across flats; four M4 bonded sealing washers; four M4 x 8 pan-head screws; four M3 x 4 nylon standoffs with M3 x 6 nylon screws; one M3 x 4 nylon-tipped grub screw | Fastener supplier | 2.50 | buy | Indicative price; added for construction (BNL-DDR-003)
11 Printed sensor mounts and window | 1 | Probe collar and ToF holder printed in ASA (about 5 g); 16 mm x 1.5 mm PMMA or glass window disc; two-part plastics epoxy and neutral-cure silicone (small packs shared across builds) | 3D printing filament supplier and hardware store | 1.50 | make | Indicative price; added for construction (BNL-DDR-003)

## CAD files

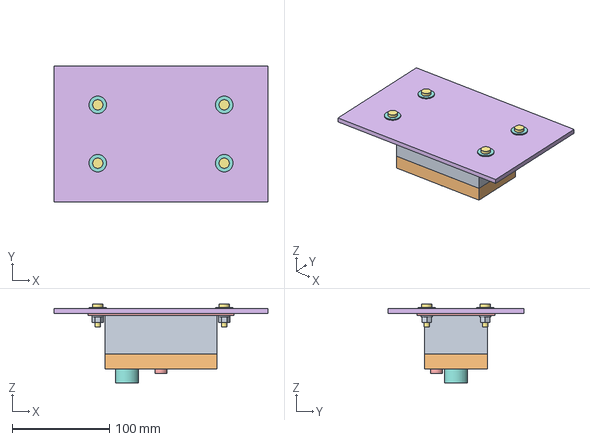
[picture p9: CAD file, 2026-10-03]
cad/step/binlevel-assembly.step
220.0 x 140.0 x 81.0 mm

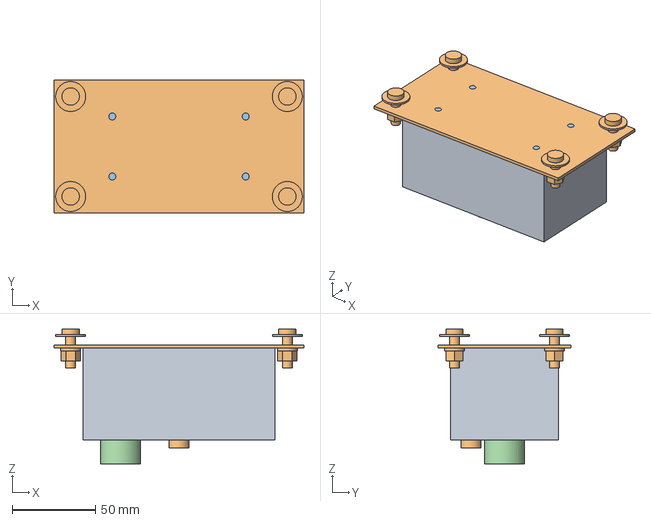
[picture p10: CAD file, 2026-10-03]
cad/step/sensor-unit.step
150.0 x 80.0 x 81.0 mm

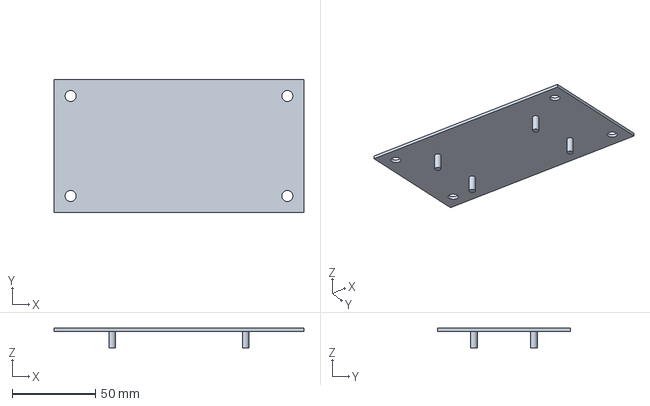
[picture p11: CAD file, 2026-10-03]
cad/step/bracket.step
150.0 x 80.0 x 12.0 mm

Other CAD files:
cad/stl/binlevel-assembly.stl
cad/stl/bracket.stl
cad/stl/sensor-unit.stl

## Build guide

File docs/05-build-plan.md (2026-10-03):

---
doc_id: BNL-BLD-001
title: BinLevel prototype build plan
project: BinLevel
doc_type: Build plan
version: "0.3"
status: Draft
date: '2026-10-02'
author: Amish Chadha
license: CERN-OHL-S-2.0
revisions:
  - version: "0.1"
    date: '2026-09-30'
    author: Amish Chadha
    change: First build plan, with pictures by component and step; design made constructable (BNL-DDR-003)
  - version: "0.2"
    date: '2026-10-02'
    author: Amish Chadha
    change: BNL-DDR-003 accepted by Amish on 2026-10-02
  - version: "0.3"
    date: '2026-10-02'
    author: Amish Chadha
    change: Plate finish for deployments (anodised) added to the plate step and making sketch BNL-DWG-101 Rev P2; general arrangement Rev P5; calculation note v0.5
---

# BinLevel prototype build plan

**Plan, not yet built.** How to build the first proof-of-concept prototype, component by component. Building and testing to it is TRL 4 work. Decisions still to be made are kept in the design decisions register ([docs/06-design-decisions.md](06-design-decisions.md)), not here.

## 1. What you are building

Figure 1. Every component, pulled apart and numbered in build order

*Figure 1. Every component pulled apart and numbered in build order. The base and what goes in it are on the left, the cover and its sensors on the right.*

The prototype is one BinLevel sensor unit and a short length of bin lid to bolt it to: a small grey plastic box that hangs under the lid from a flat aluminium plate. The box's deep half (the base) is fixed to the plate and holds the electronics board, the cell and the antenna; its shallow half (the cover) faces down into the bin and carries the ultrasonic transducer, the window for the near-range light sensor and a breather vent. Figure 1 shows the 18 components in the order you make or fit them. Five are made or worked in a small workshop: the plate (cut, drilled and fitted with pressed-in studs), the two halves of a bought box (drilled), the electronics board (a cut and drilled prototyping board) and two small 3D-printed mounts for the sensors. Everything else is bought and fitted: the box, transducer and its driver board, light sensor, radio module, cell and holder, antenna, vent, standoffs and fixings. The work is cutting and drilling thin aluminium and plastic, one press fit, two small prints, bonding with epoxy and silicone, and soldering bought breakout boards together. The parts cost about $59 from the bill of materials.

> **Safety:** The prototype holds a primary lithium thionyl chloride cell (3.6 V, about 30 Wh). It must never be charged, shorted, crushed or heated; a damaged cell can vent toxic, corrosive gas or catch fire. Keep it out of the holder until safety stop S3 (section 6), and never connect a bench supply to the board while the cell is in. Cut aluminium edges are sharp: deburr everything. Printing ASA and curing epoxy give off fumes; work in a ventilated space. Fitting to a real bin is outside this plan; bins hold sharps and biological waste.

## 2. What changed to make it buildable

The concept showed what the unit does; some of its parts could not be made or fixed as drawn. Each change below keeps what the unit does, and all of them are recorded in decision record BNL-DDR-003, accepted by Amish on 2026-10-02.

*Table 1. Changes from the concept.*

| Component | The concept had | The buildable design has | Why |
| --- | --- | --- | --- |
| Box to plate | Two tabs folded down from the plate beside the box ends, with nothing holding the box; the tabs could not be folded from a flat blank | No tabs. Four studs pressed into the plate pass through the box floor; a sealing washer and a standoff on each one clamp the box to the plate (Figure 4) | The plate stays flat against the lid, the box stays sealed, and the standoffs also carry the board |
| Tamper bolts | Bolts 40 mm long, sticking 24 mm out below the nuts; the nuts drawn inside the plate | Bolts 20 mm long, a sealing washer under each head on the lid, a washer and locking nut under the plate (Figure 19) | Right length for the lid and plate; the nut sits 1.5 mm clear of the box |
| Box height | 45 mm tall, with no room for the transducer's driver board | 55 mm tall; the driver board hangs under the electronics board (Figure 10) | The driver board is part of the bought transducer kit; the unit is still well inside its size limit |
| Electronics board | A full-size board floating at mid height, clashing with the box's corner screw towers and touching the transducer | A 90 x 50 mm prototyping board on the four standoffs, 10 mm above the transducer (Figure 9) | It has a fixing, clears the towers and stands in for the circuit board, whose layout is later work |
| Transducer | Pushed into its hole with nothing holding it | A printed collar bonded inside the cover, with a clamp screw; silicone seals the hole (Figure 16) | Holds it at the right depth without more holes in the box |
| Light sensor window | A plug in the hole, and the sensor board floating above it | A printed holder bonded over the hole, holding a window disc and the sensor board (Figure 18) | The window seals from inside, so water pressure pushes it onto its seat |
| Vent, gasket, cell | Vent missing from the model; gasket drawn outside the box walls; cell floating with no holder | Vent in the cover facing down; gasket in the base rim groove; cell in a holder with a strap through the board (Figures 11 and 14) | Every part has a place and a fixing |
| Sensor leads | No way to take the cover off | Plugs on the transducer cable and the light sensor lead | The cover comes away from below for service |

## 3. Making the components

Make and check each component before the assembly step that needs it. Sizes are in millimetres. "Front" is the long side of the unit that faces you when you stand at the bin; "left" and "right" are as seen from the front. The unit hangs upside down compared with most boxes: the plate is on top and the cover faces down. Workshop tolerance is 0.5 mm unless a step says otherwise; drawings do not carry tolerances before TRL 4.

### 3.1 Bracket plate

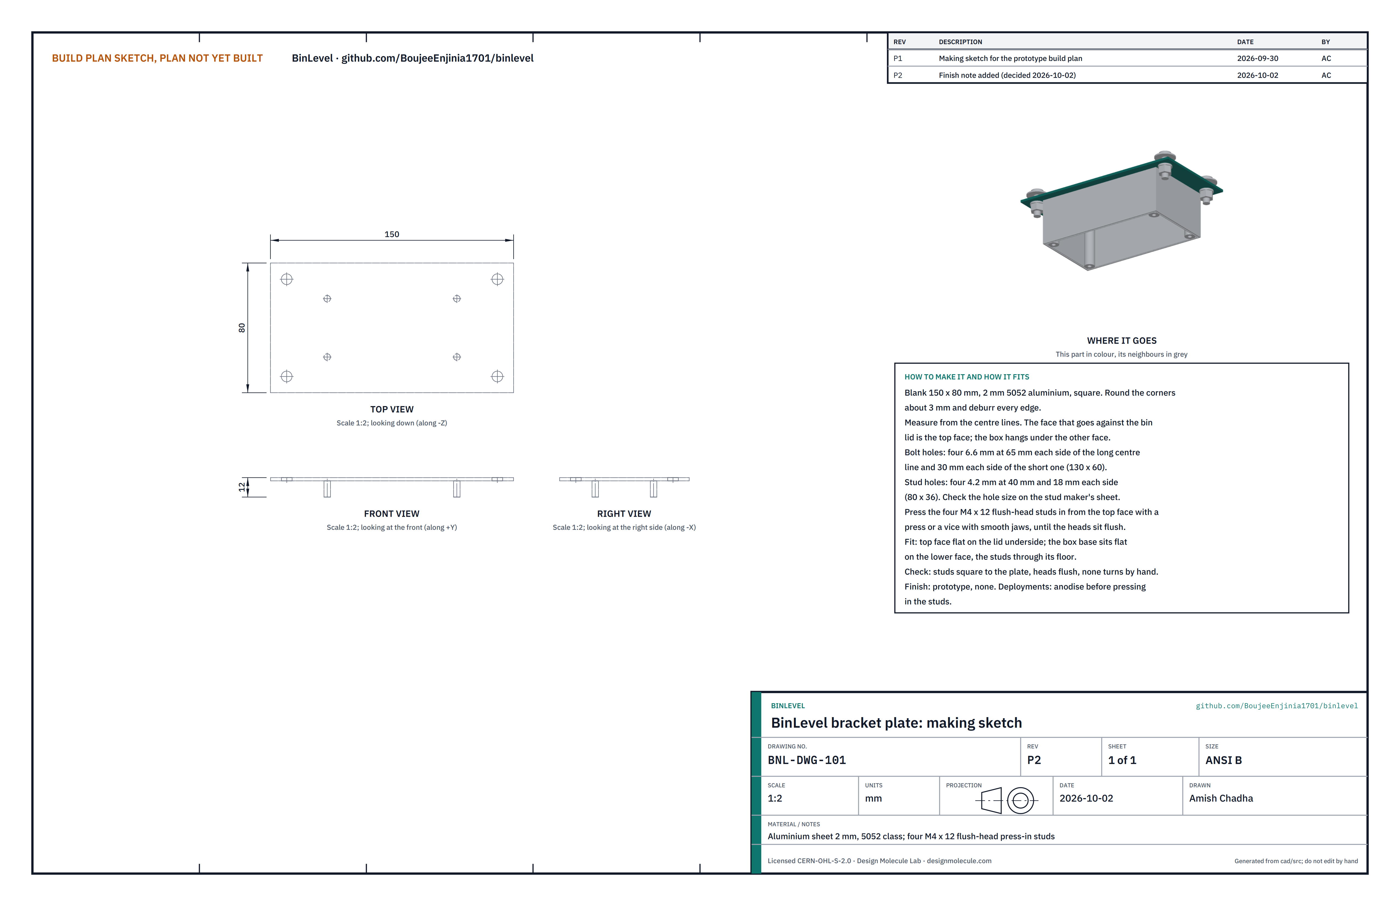
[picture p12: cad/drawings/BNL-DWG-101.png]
Figure 2. Making sketch of the bracket plate


*Figure 2. Bracket plate making sketch (BNL-DWG-101).*

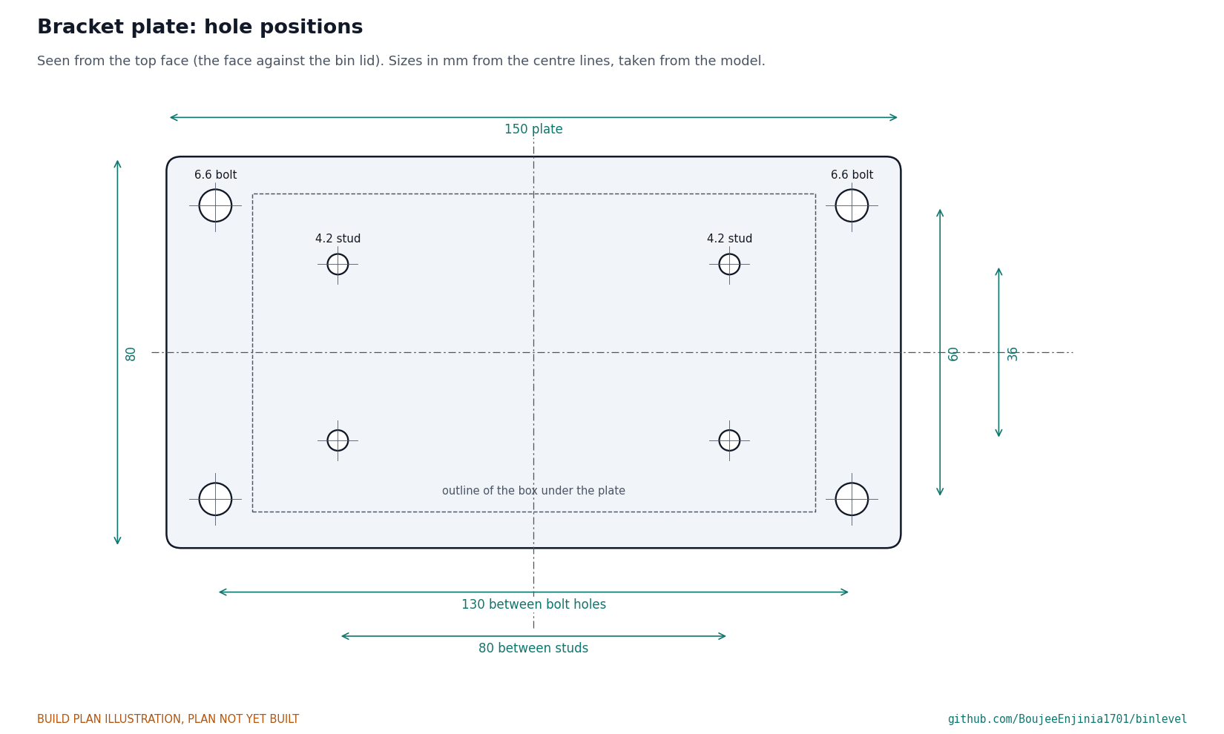
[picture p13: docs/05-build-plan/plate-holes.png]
Figure 3. Hole positions in the bracket plate


*Figure 3. Hole positions, measured from the two centre lines, with the outline of the box under the plate.*

**What it is and what it is made from.** The flat plate that sits against the underside of the bin lid and carries the box. Aluminium sheet 2 mm thick, 5052 class, 150 x 80 mm, with four M4 x 12 flush-head press-in studs.

**How to make it.**

1. Cut the blank to 150 x 80 mm, square. Round the corners to about 3 mm and deburr every edge.
2. Scribe both centre lines. Choose one face as the top (the face against the lid) and mark it.
3. Bolt holes: four 6.6 mm holes, 65 each side of the short centre line and 30 each side of the long one (130 x 60 apart).
4. Stud holes: four 4.2 mm holes, 40 each side and 18 each side (80 x 36 apart). Check the hole size against the stud maker's data sheet before drilling.
5. Deburr every hole on both faces.
6. Press the four studs in from the top face, with an arbor press or a vice with smooth jaws, until each head sits flush with the top face.

**Finish.** The prototype plate has no finish. A plate for a deployed unit is anodised after drilling and before the studs are pressed in, so that the stainless studs and bolts do not corrode the aluminium around the holes.

**How it fits the parts next to it.**

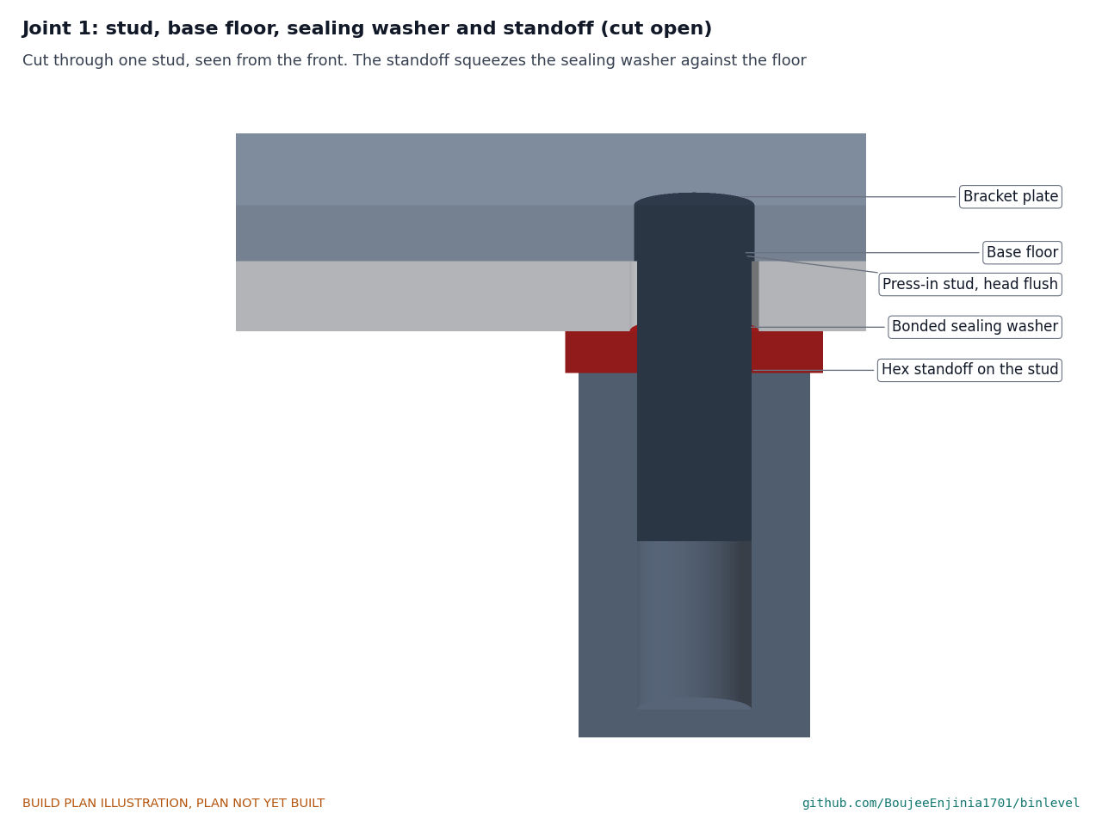
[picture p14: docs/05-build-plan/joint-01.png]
Figure 4. Joint 1: stud, base floor, sealing washer and standoff


*Figure 4. Each stud passes through the box floor; inside, a bonded sealing washer and a hex standoff clamp the floor to the plate.*

The top face lies flat on the underside of the bin lid. The box base sits flat on the lower face, centred, with the four studs through its floor. The bolt holes stand clear of the box ends by 1.5 mm at the washers.

**Check before moving on.** The studs stand square to the plate, their heads are flush with the top face, and none turns when you twist it with pliers.

### 3.2 Enclosure base, drilled

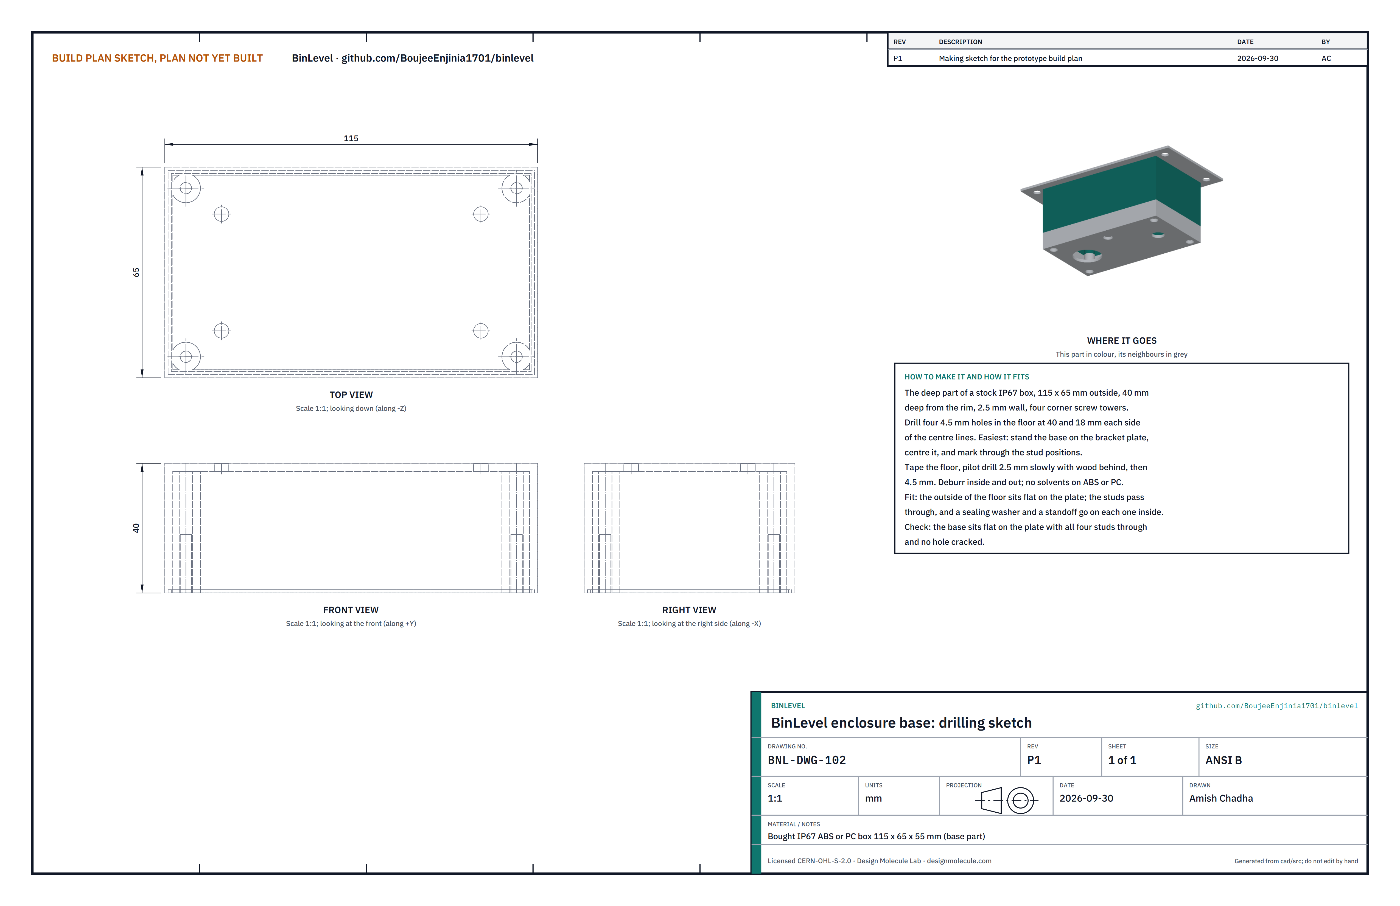
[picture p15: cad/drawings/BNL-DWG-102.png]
Figure 5. Drilling sketch of the enclosure base


*Figure 5. Enclosure base drilling sketch (BNL-DWG-102).*

**What it is and what it is made from.** The deep half of a bought IP67 box, 115 x 65 x 55 mm outside with a 2.5 mm wall, ABS or polycarbonate, with four corner screw towers for the cover screws. Four holes are drilled in its floor.

**How to make it.**

1. Stand the base on the lower face of the plate, centred, and mark the floor through the four stud positions (or measure 40 and 18 each side of the centre lines).
2. Cover the floor with masking tape. Put a block of wood behind it, pilot drill 2.5 mm at low speed, then open each hole to 4.5 mm. Do not centre punch hard; the plastic can crack.
3. Deburr inside and out, peel the tape and clean with water and mild soap only; solvents craze polycarbonate.

**How it fits the parts next to it.** The outside of the floor sits flat on the plate with the four studs through it. Inside, a bonded sealing washer (rubber side to the floor) and a 30 mm hex standoff go on each stud (Figure 4); the standoffs pull the floor onto the plate and later carry the electronics board.

**Check before moving on.** The base sits flat on the plate with all four studs through, and no crack runs from any hole under a bright lamp.

### 3.3 Electronics board

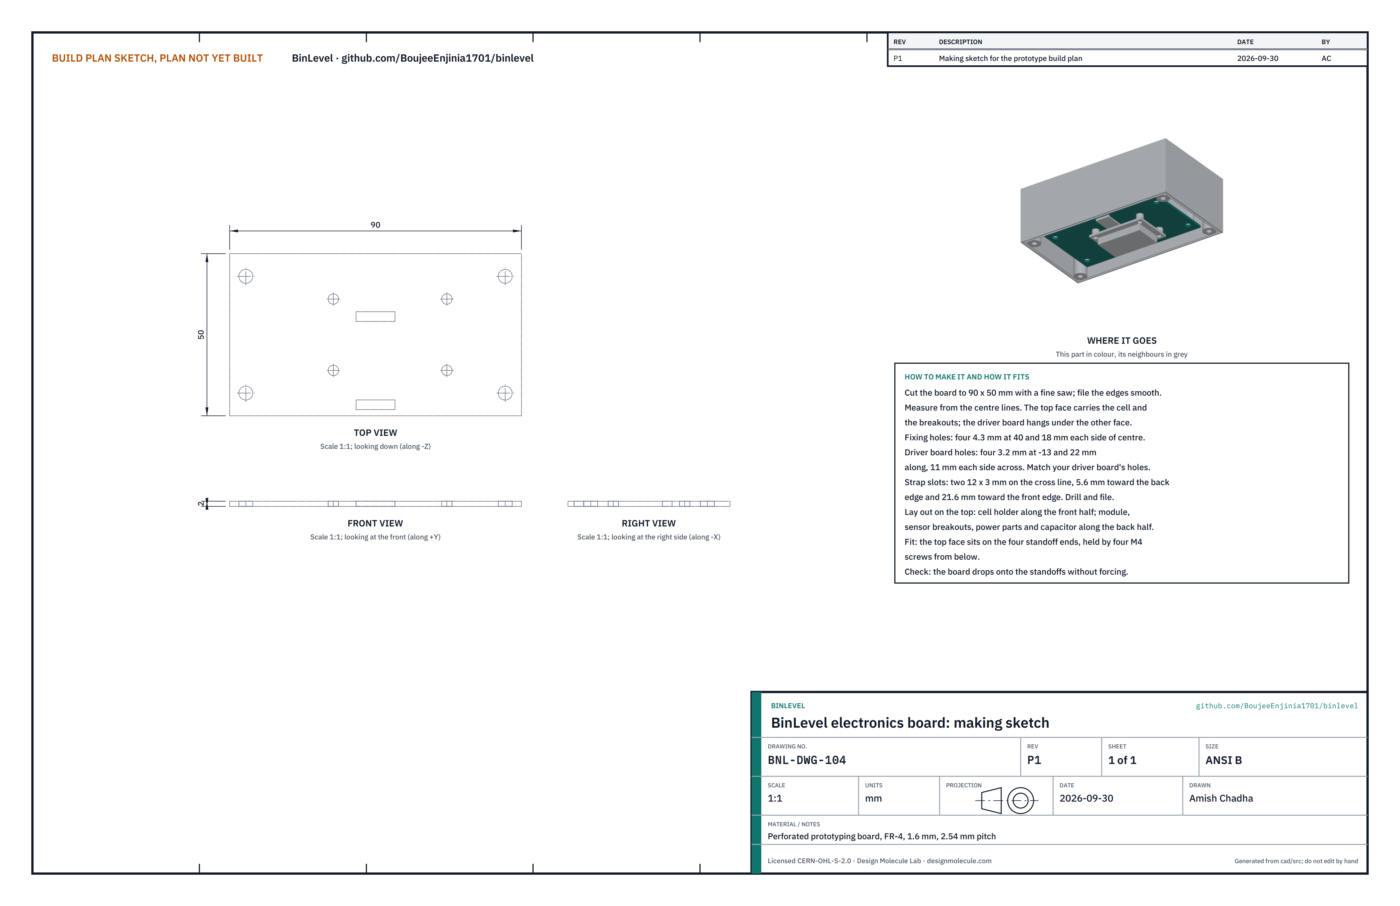
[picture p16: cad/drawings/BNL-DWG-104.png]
Figure 6. Making sketch of the electronics board


*Figure 6. Electronics board making sketch (BNL-DWG-104).*

**What it is and what it is made from.** The board that carries the cell, the radio module and the small electronic parts, and has the transducer's driver board hanging under it. For the prototype it is a perforated prototyping board (glass-fibre, 1.6 mm, 2.54 mm hole pitch) standing in for the custom circuit board, whose layout is later work.

**How to make it.**

1. Cut the board to 90 x 50 mm with a fine saw and file the edges smooth.
2. Scribe the two centre lines. The face that will carry the cell is the top face; the long edge that will face the front of the unit is the front edge.
3. Fixing holes: four 4.3 mm holes, 40 each side and 18 each side of centre.
4. Driver board holes: four 3.2 mm holes at 13 mm left and 22 mm right of centre, 11 each side of the long centre line. Hold your driver board on the board and adjust these to its own holes.
5. Strap slots: two slots 12 x 3 mm on the short centre line, centred 5.6 mm toward the back edge and 21.6 mm toward the front edge. Drill a row of 1.5 mm holes and file each slot square.
6. Lay out the parts as Figure 7 shows: the cell holder along the front half, the radio module, sensor breakouts, power parts and capacitor along the back half. Solder each on its pins.
7. Fit the driver board under the board on four 4 mm nylon standoffs and M3 nylon screws, its parts facing down (Figure 10).
8. Wire everything as Figure 8 shows (section 3.3.1).

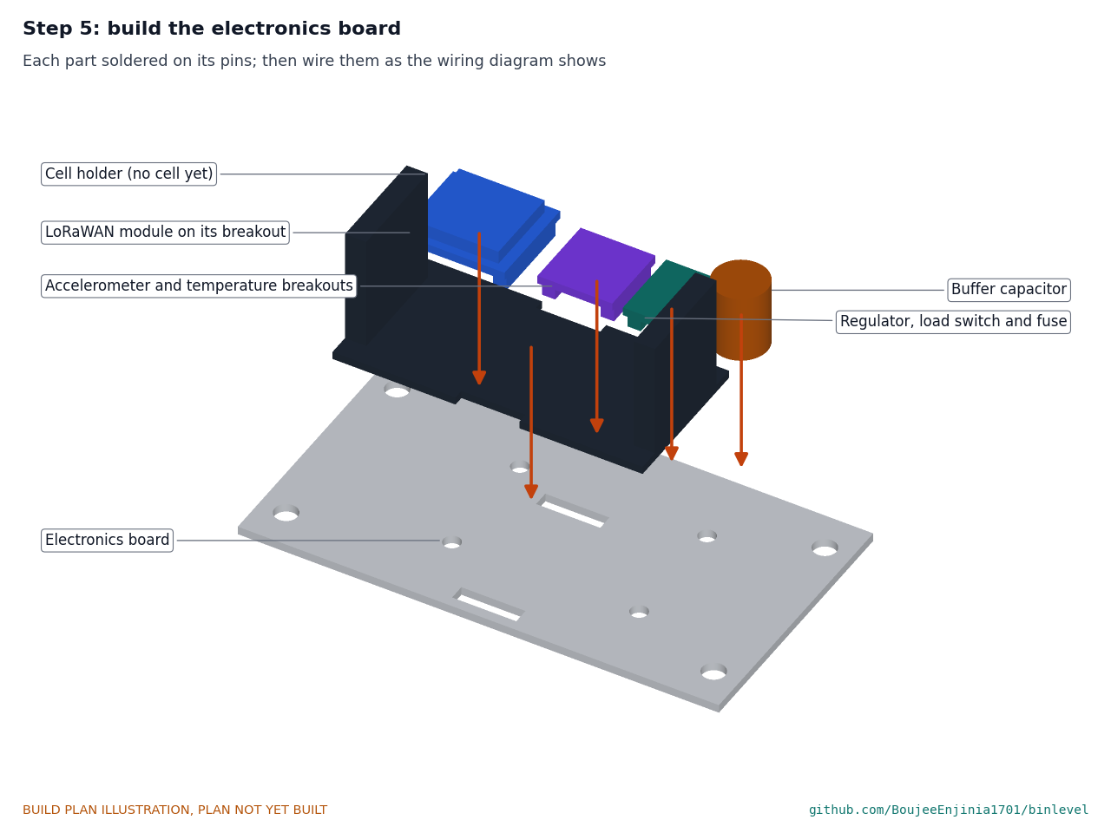
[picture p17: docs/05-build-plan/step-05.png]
Figure 7. Step 5 picture: parts on the electronics board


*Figure 7. Where each part goes on the top face of the board.*

#### 3.3.1 Wiring

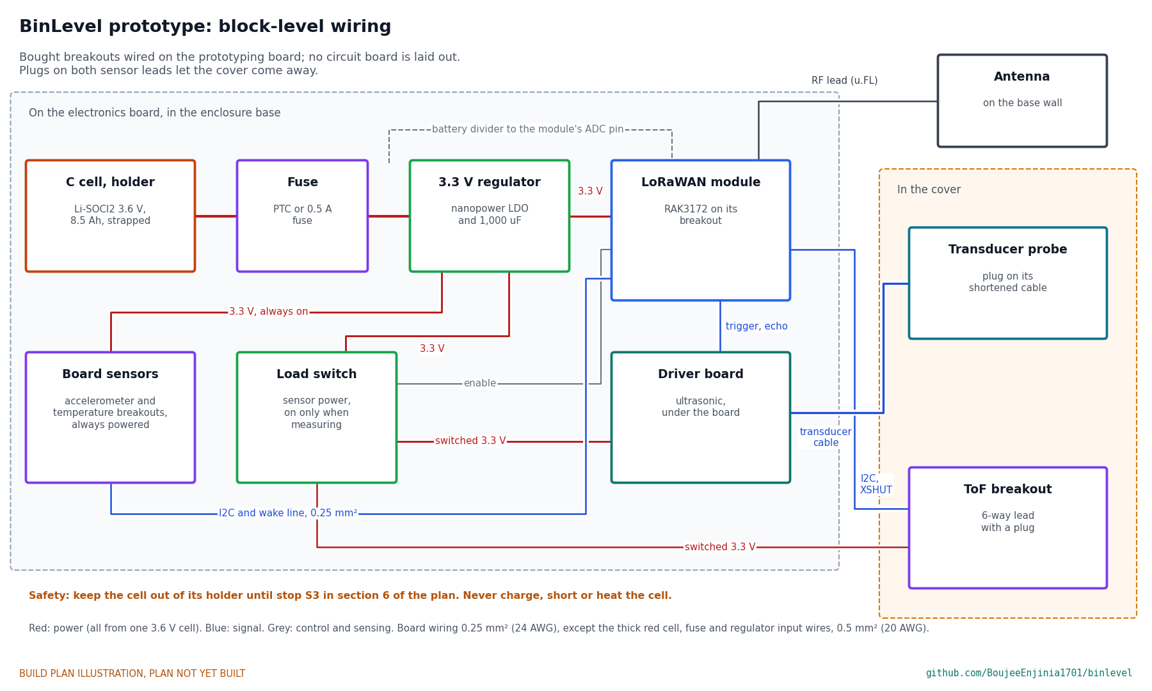
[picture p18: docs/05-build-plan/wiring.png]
Figure 8. Block-level wiring


*Figure 8. Block-level wiring with wire sizes. No circuit board is laid out at this stage; bought breakouts stand in for it.*

*Table 2. Parts on the electronics board.*

| Part | What to buy or fit |
| --- | --- |
| Radio module | RAK3172 (RAK3172-T for sites colder than -20 °C) on its maker's breakout board, with a u.FL antenna socket |
| Board sensors | Three-axis accelerometer breakout with a wake-on-motion output (LIS2DH12 class) and a low-power temperature sensor breakout |
| 3.3 V regulator | Nanopower low-dropout regulator, 3.3 V out, quiescent current under 1 µA, at least 100 mA |
| Buffer capacitor | 1,000 µF low-leakage electrolytic or polymer capacitor, 6.3 V or more, across the regulator input |
| Load switch | Low-leakage load switch with an enable input, feeding the driver board and the light sensor only while measuring |
| Fuse | Resettable fuse or 0.5 A fuse in the cell lead |
| Battery divider | Two resistors of about 1 MΩ, switched by the module, from the fused cell lead to an analog input |
| Plugs | Two-way plug for the transducer cable (the driver board's own) and a six-way plug for the light sensor lead |

Wire it like this, with ferrules or solder on every joint:

1. Cell holder to the fuse, and the fuse to the regulator input: 0.5 mm² (20 AWG).
2. Regulator output (3.3 V) to the radio module, the board sensors and the load switch input: 0.25 mm² (24 AWG).
3. Load switch output to the driver board supply and to the light sensor plug: 0.25 mm².
4. Radio module to the load switch enable, the driver board's trigger and echo pins, the board sensors (I2C and the wake line) and the light sensor plug (I2C and its shut-down line): 0.25 mm².
5. Battery divider from the fused cell lead to the module's analog input.
6. Antenna lead from the module's u.FL socket to the antenna on the base wall, away from the power wires.

**Check before moving on.** Every wire continues end to end; with no cell in the holder, the cell terminals read open to every rail; every lead and plug is labelled.

**How it fits the parts next to it.**

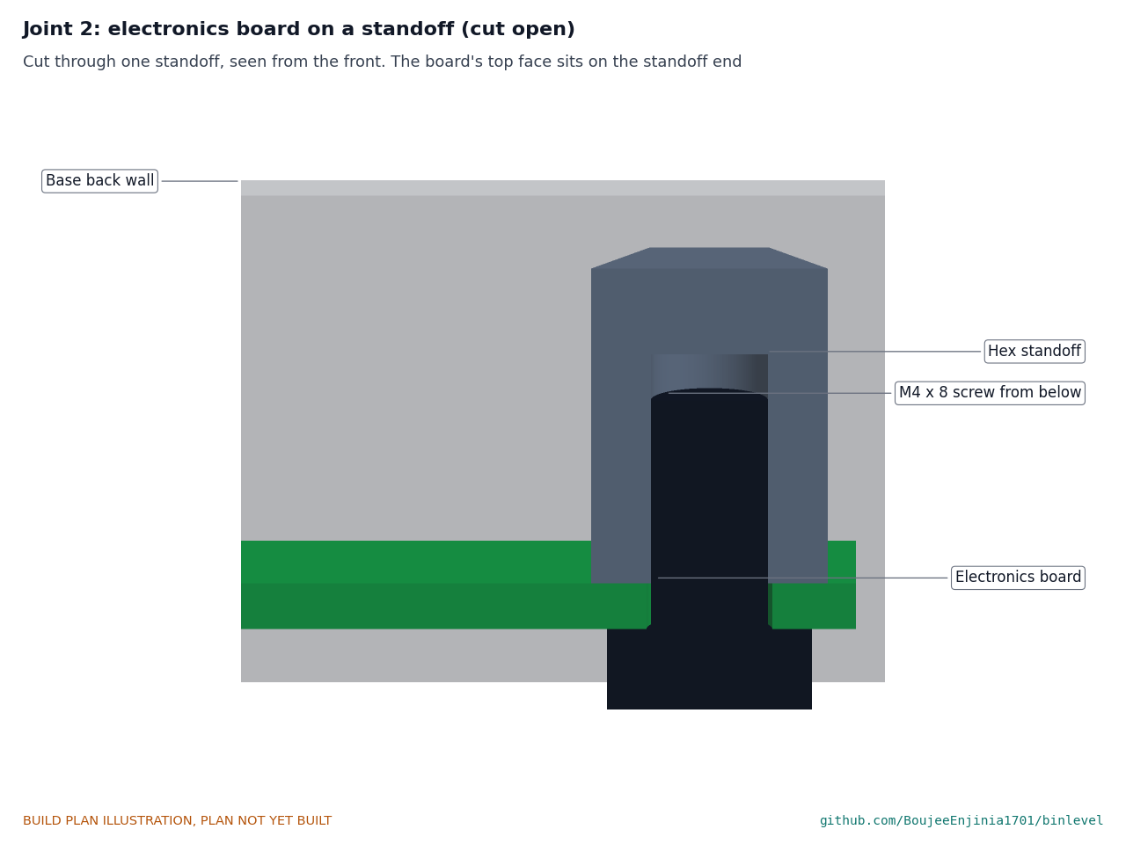
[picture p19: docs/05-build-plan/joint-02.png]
Figure 9. Joint 2: electronics board on a standoff


*Figure 9. The board's top face sits on the end of each standoff, held by one M4 x 8 screw from below.*

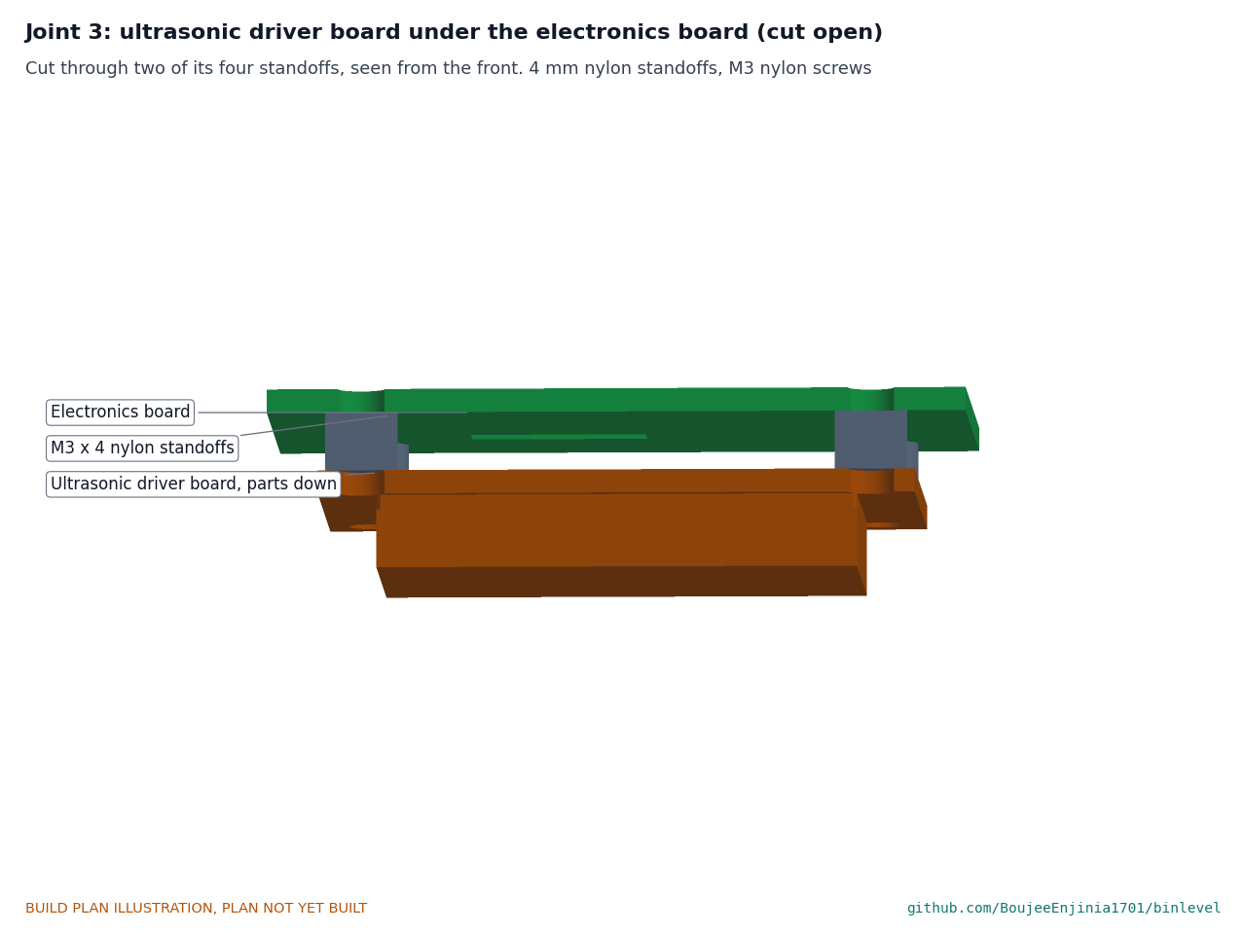
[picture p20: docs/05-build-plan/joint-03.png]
Figure 10. Joint 3: driver board under the electronics board


*Figure 10. The driver board hangs 4 mm under the electronics board on nylon standoffs, its parts facing down, clear of the transducer and the light sensor holder.*

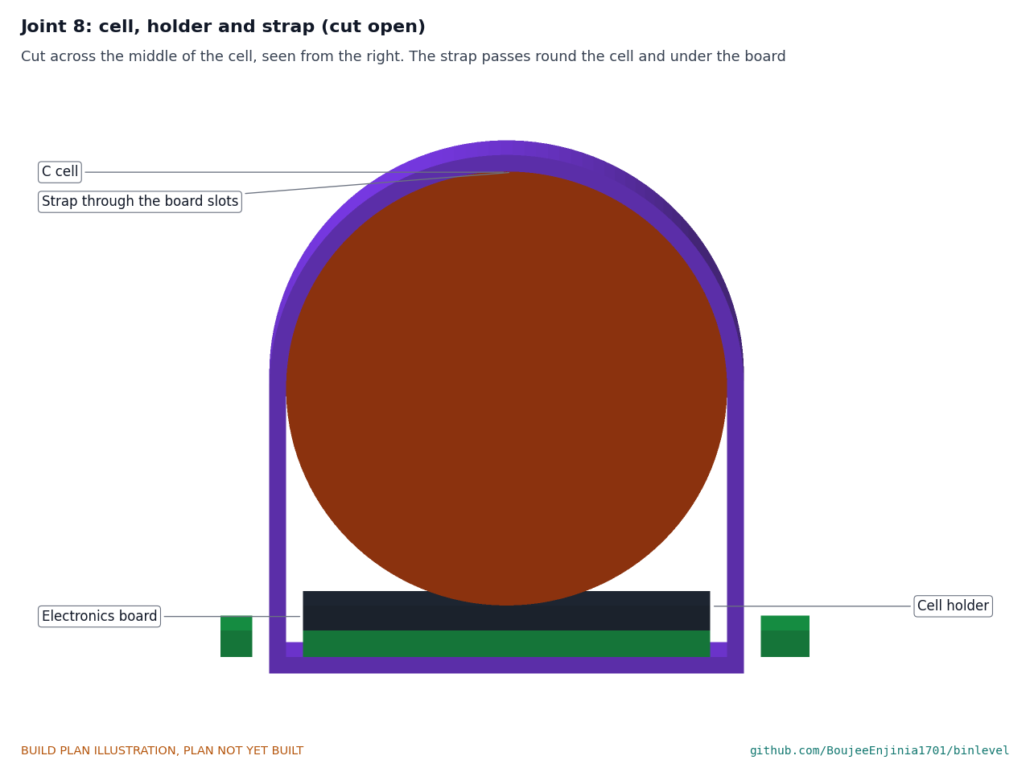
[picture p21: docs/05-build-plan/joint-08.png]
Figure 11. Joint 8: cell, holder and strap


*Figure 11. The strap passes round the cell, through the holder base and the board slots, and under the board.*

The board hangs 31.5 mm below the inside of the box floor, with 1.6 mm between its corners and the box's screw towers. The cell clears the box floor by 3.8 mm, and the transducer sits 10 mm below the board.

**Check before moving on.** The board drops onto the four standoffs without forcing, and the driver board does not touch anything below it when the cover is offered up.

### 3.4 Enclosure cover, drilled

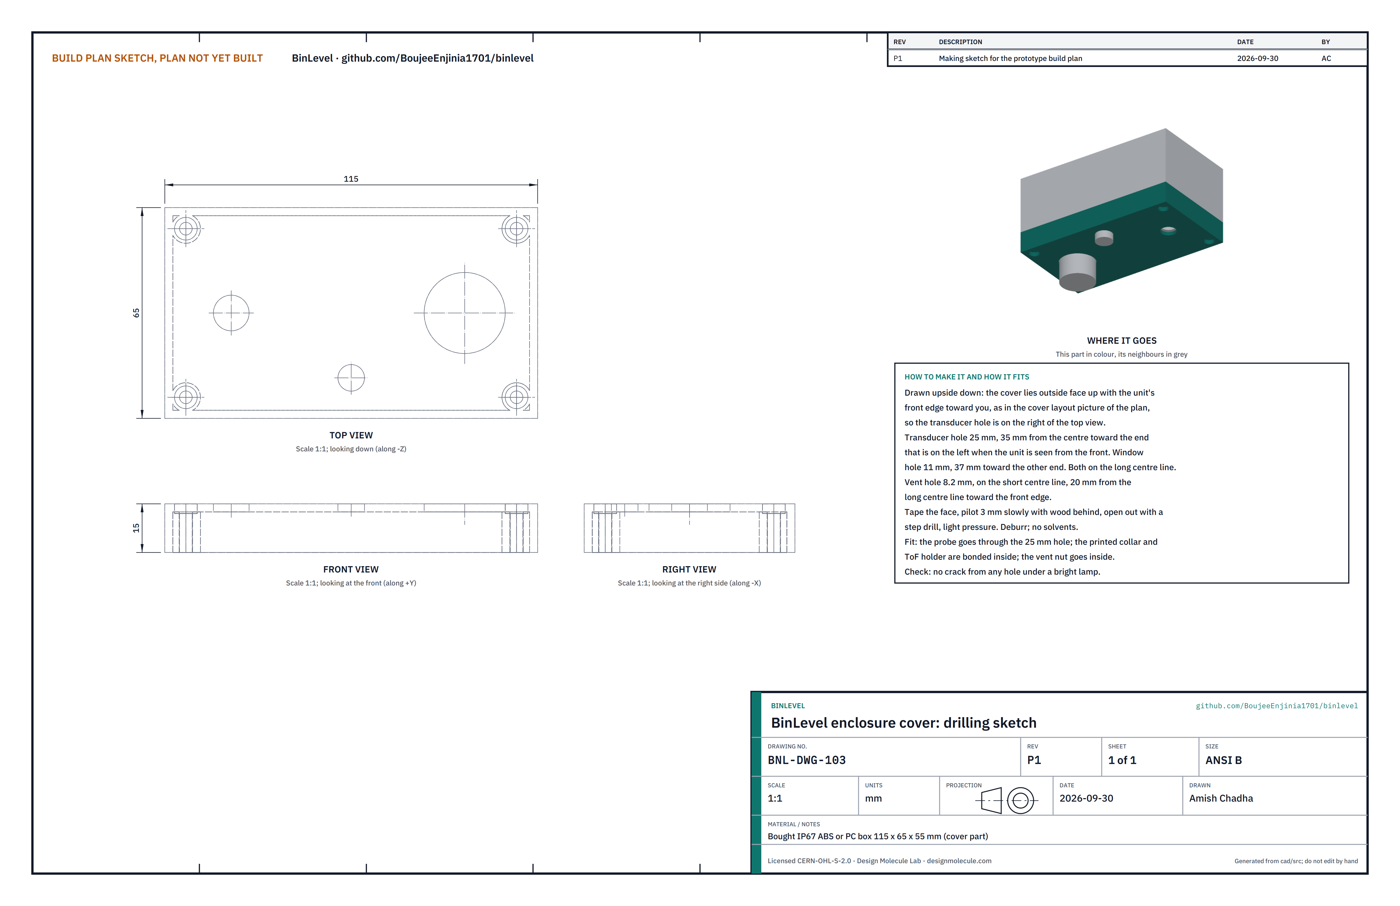
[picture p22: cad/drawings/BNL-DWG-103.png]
Figure 12. Drilling sketch of the enclosure cover


*Figure 12. Enclosure cover drilling sketch (BNL-DWG-103), drawn upside down so the top view shows the outside of the floor.*

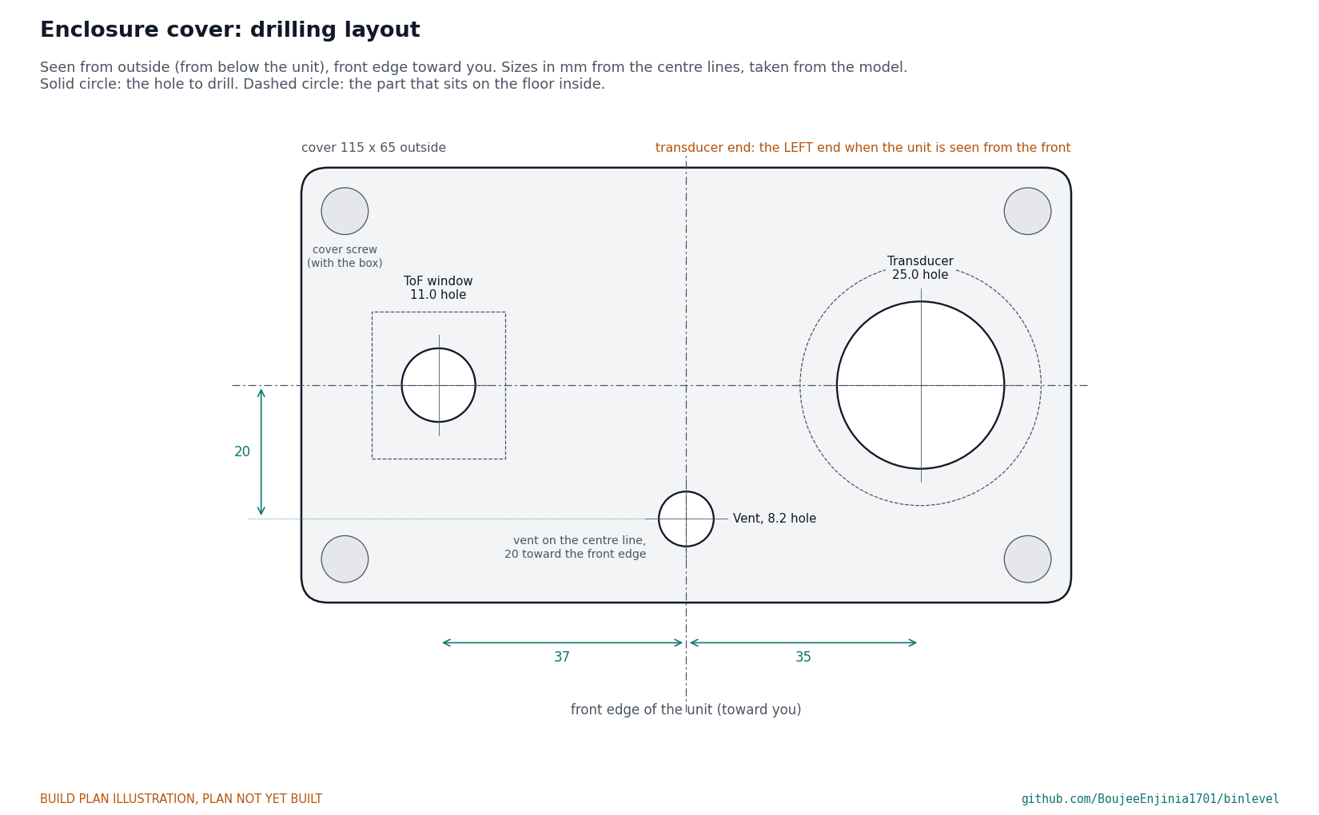
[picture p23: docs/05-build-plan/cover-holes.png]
Figure 13. Cover drilling layout


*Figure 13. Drilling layout, seen from outside with the front edge toward you. The transducer end is on your right here; it is the left end when the unit hangs under the lid and you see it from the front.*

**What it is and what it is made from.** The shallow half of the same bought box, 15 mm deep, with its four corner cover screws. Three holes are drilled in its floor.

**How to make it.**

1. Lay the cover outside face up, front edge toward you. Cover the floor with masking tape and scribe both centre lines.
2. Mark the holes from Figure 13: the transducer hole 25 mm across, 35 right of centre on the long centre line; the window hole 11 mm across, 37 left of centre on the same line; the vent hole 8.2 mm across, on the short centre line, 20 toward you.
3. Put a block of wood inside under the floor. Pilot drill each hole 3 mm at low speed, then open it with a step drill and light pressure. Check the transducer hole against your probe before the last step: it should be 1 mm larger than the probe.
4. Deburr inside and out and clean with water and mild soap only.

**How it fits the parts next to it.** The transducer, its collar, the window holder and the vent fit in the cover (sections 3.5 and 3.6, steps 9 to 11). The cover rim closes onto the gasket in the base rim groove, pulled up by the four corner screws:

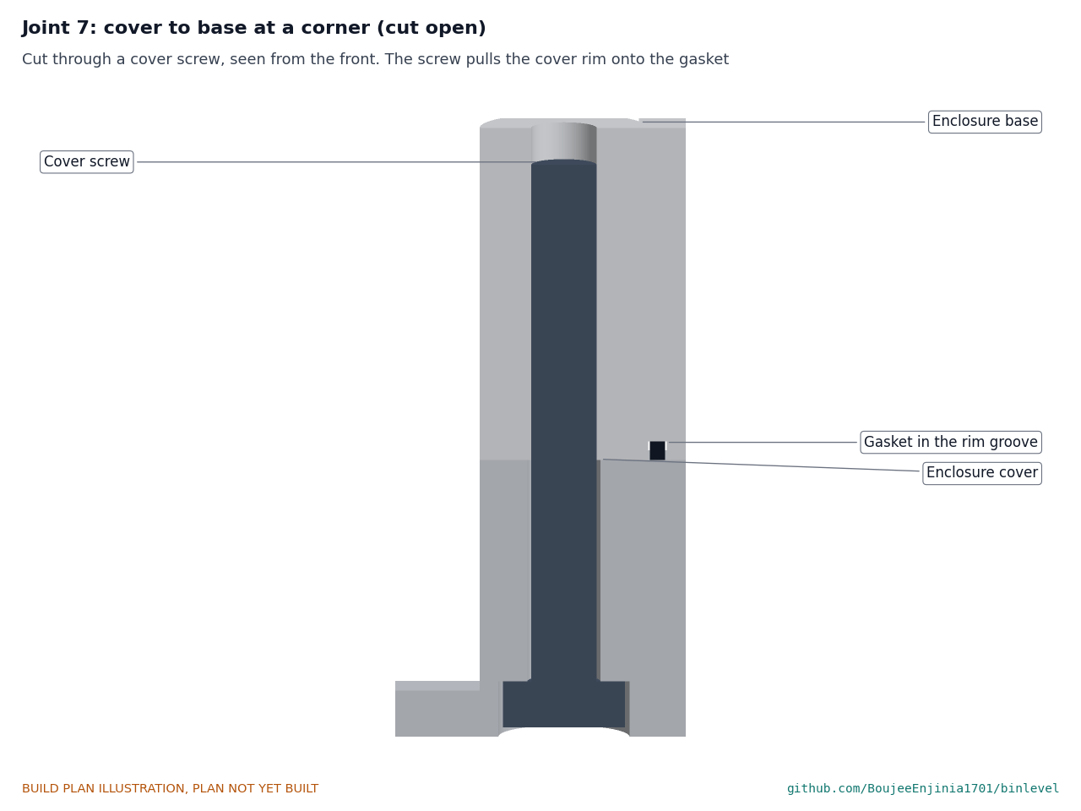
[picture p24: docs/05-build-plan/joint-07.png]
Figure 14. Joint 7: cover to base at a corner


*Figure 14. Each cover screw passes up through a tower in the cover into a tower in the base, pulling the cover rim onto the gasket.*

**Check before moving on.** No crack runs from any hole, and the cover still closes on the base with all four screws.

### 3.5 Probe collar

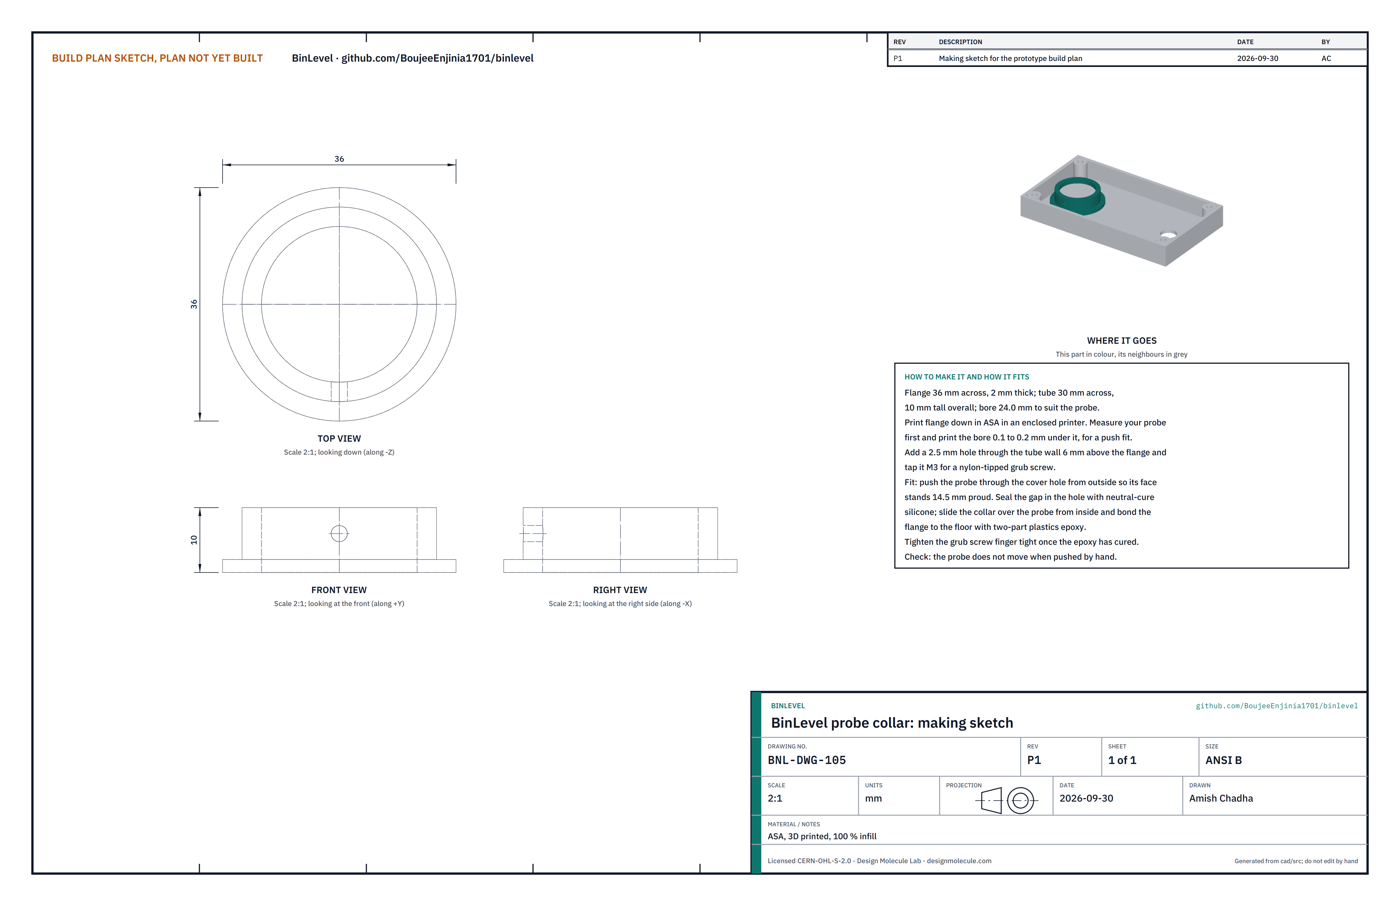
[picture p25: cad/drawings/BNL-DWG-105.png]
Figure 15. Making sketch of the probe collar


*Figure 15. Probe collar making sketch (BNL-DWG-105).*

**What it is and what it is made from.** A short printed sleeve that holds the transducer probe at the right depth inside the cover. ASA plastic, printed at 100 % infill in an enclosed printer.

**How to make it.**

1. Measure your probe's diameter. The model assumes 24 mm.
2. Print the collar flange down: a flange 36 mm across and 2 mm thick, a tube 30 mm across and 10 mm tall overall, and a bore 0.1 to 0.2 mm smaller than the probe, for a push fit. Let it cool on the bed.
3. Drill a 2.5 mm hole through the tube wall, 6 mm above the flange, on the side that will face the front, and tap it M3.

**How it fits the parts next to it.**

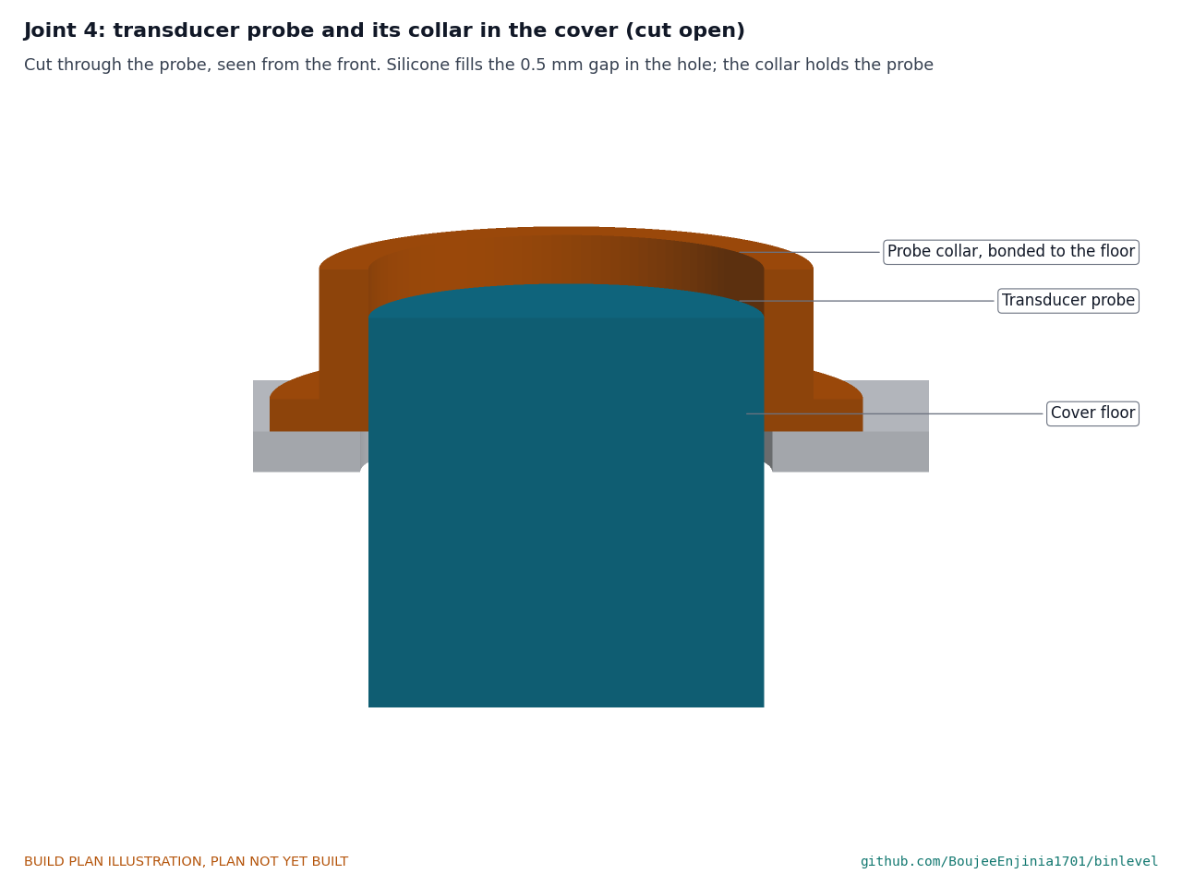
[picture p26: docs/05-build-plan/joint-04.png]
Figure 16. Joint 4: transducer probe and collar in the cover


*Figure 16. The probe passes through the 25 mm hole, its face 14.5 mm proud of the cover; silicone fills the 0.5 mm gap; the collar flange is bonded to the floor and its screw clamps the probe.*

**Check before moving on.** The collar slides onto the probe with hand pressure and does not rock.

### 3.6 Light sensor holder and window

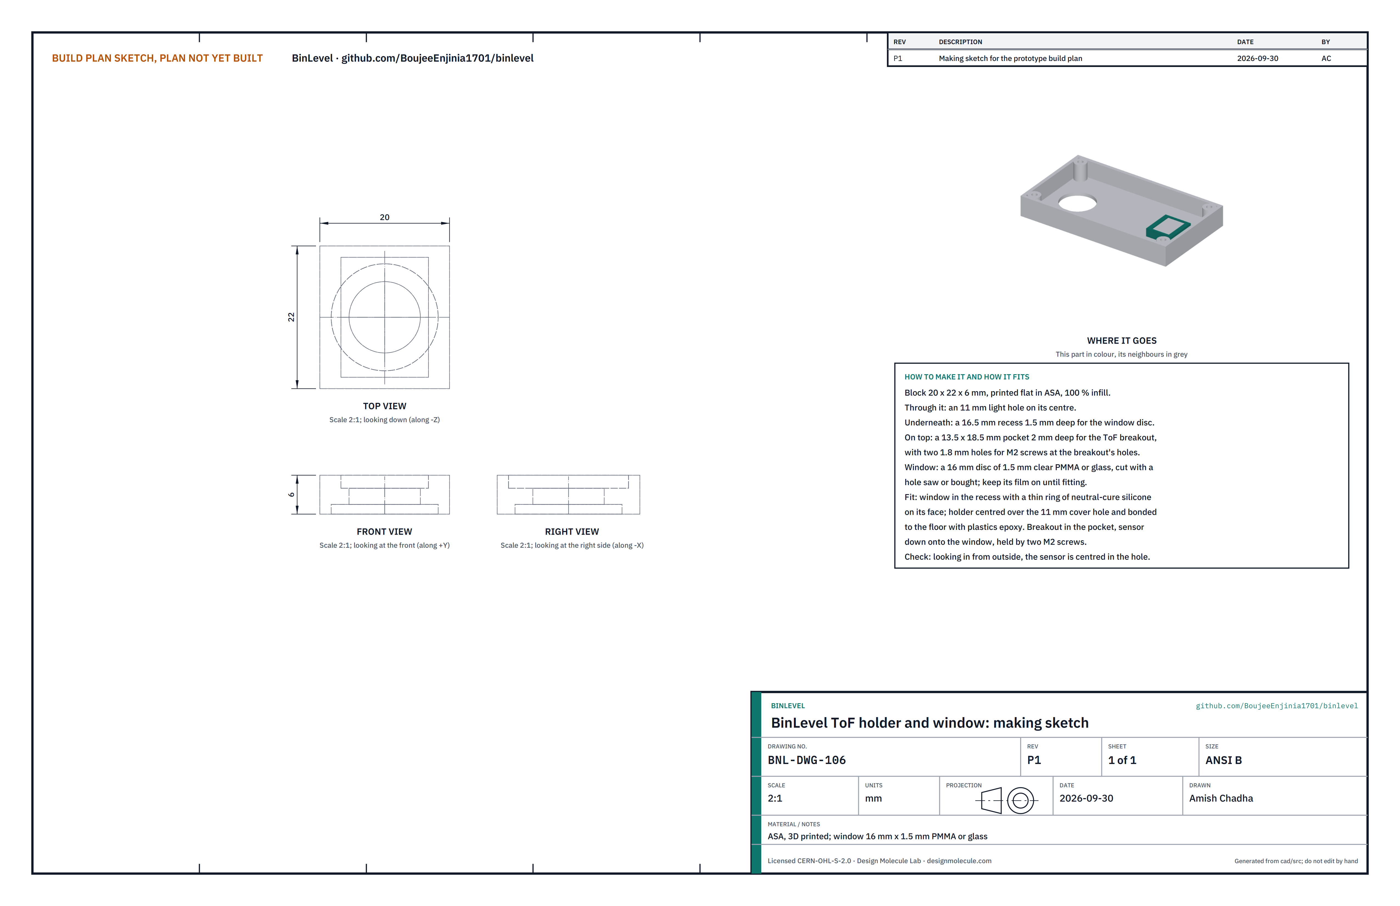
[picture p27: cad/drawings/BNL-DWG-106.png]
Figure 17. Making sketch of the light sensor holder


*Figure 17. Light sensor (ToF) holder and window making sketch (BNL-DWG-106).*

**What it is and what it is made from.** A small printed block that holds a clear window disc over the 11 mm hole and the light sensor breakout just above it. ASA plastic, 100 % infill; the window is a 16 mm disc of 1.5 mm clear PMMA or glass.

**How to make it.**

1. Print the block 20 x 22 x 6 mm, flat, with an 11 mm light hole through its centre, a 16.5 mm recess 1.5 mm deep underneath for the window, and a 13.5 x 18.5 mm pocket 2 mm deep on top for the breakout. Adjust the pocket to your breakout's size and add two 1.8 mm holes at its mounting holes.
2. Cut the window disc with a hole saw at low speed, or buy a 16 mm disc. Keep its protective film on until fitting.

**How it fits the parts next to it.**

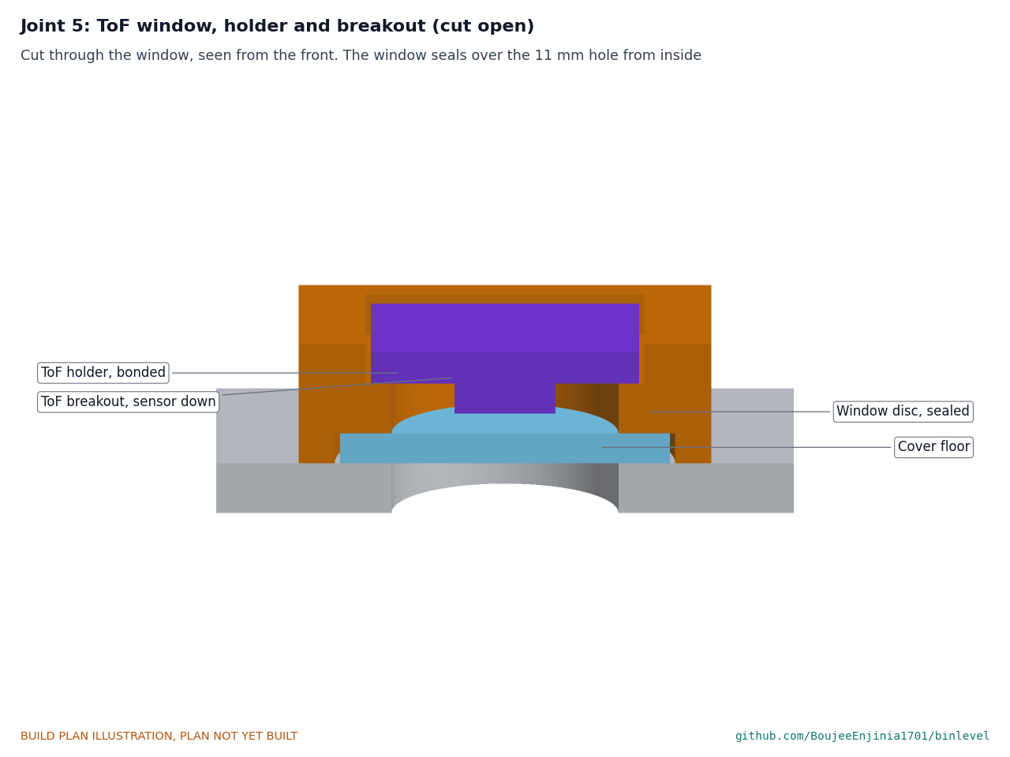
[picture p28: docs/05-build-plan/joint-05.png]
Figure 18. Joint 5: window, holder and light sensor


*Figure 18. The window sits in the holder's recess on the cover floor over the 11 mm hole; the breakout sits in the top pocket, sensor facing down onto the window.*

**Check before moving on.** Looking in through the hole from outside, the sensor is centred and the window is clean.

### 3.7 Bought components

Buy to specification, not brand. Line numbers are those of the bill of materials.

- **Enclosure (line 1).** IP67 ABS or polycarbonate box 115 x 65 x 55 mm outside, 2.5 mm wall, a 15 mm deep screw-down cover with gasket and four corner screws.
- **Bolts, washers and nuts (line 2).** Four stainless M6 x 20 tamper-resistant button-head bolts with their driver, four 18 mm sealing washers, four M6 plain washers and four M6 nyloc nuts.

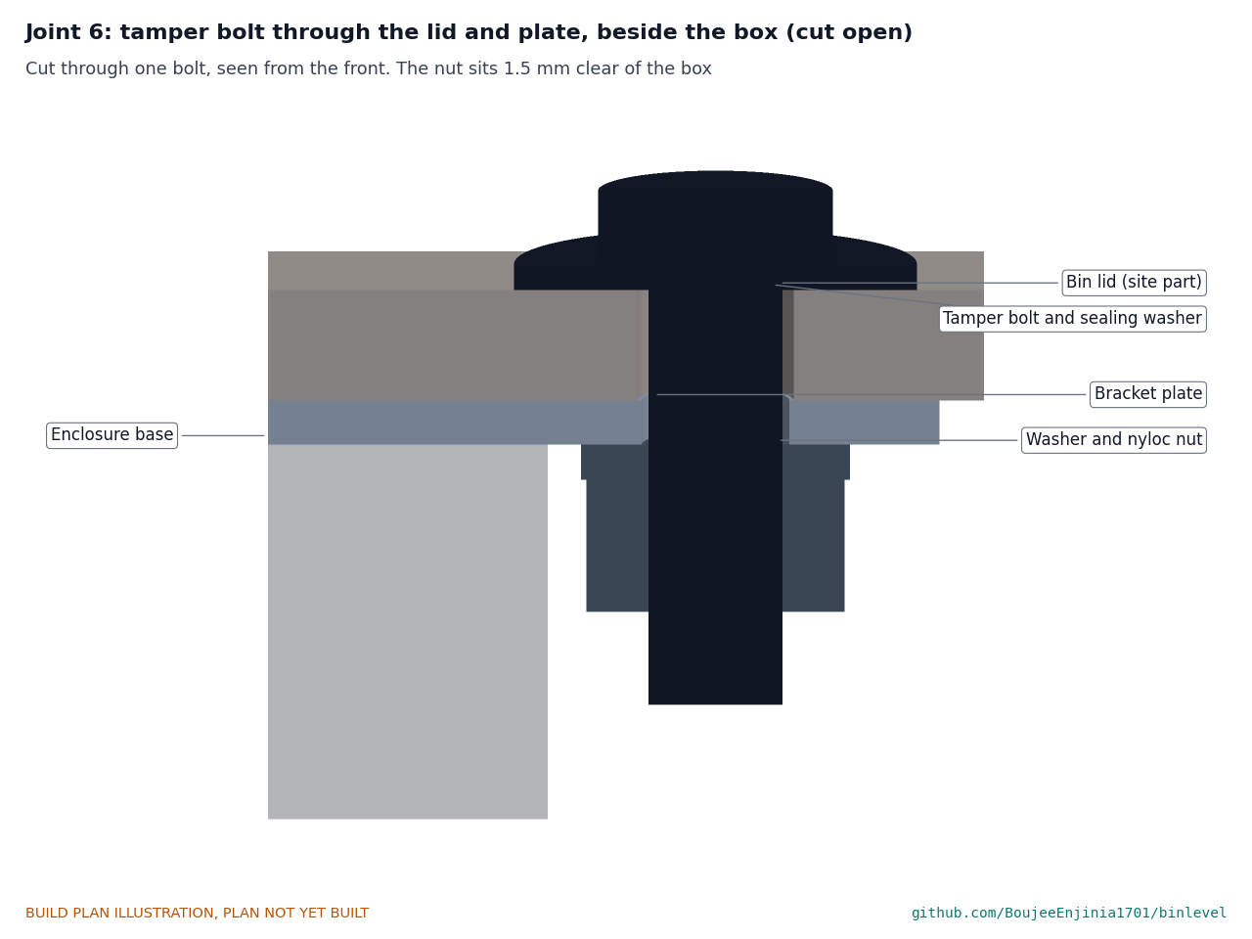
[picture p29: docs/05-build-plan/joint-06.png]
Figure 19. Joint 6: tamper bolt through the lid and plate


*Figure 19. The bolt passes down through its sealing washer, the lid and the plate; the washer and nut sit under the plate, 1.5 mm clear of the box.*

- **Transducer and driver board (line 3).** Sealed 40 kHz waterproof ultrasonic transducer, 3.3 V capable (JSN-SR04T class), 24 mm probe, with its driver board of about 41 x 28 mm. Shorten the probe cable to about 0.15 m and refit its plug.
- **Light sensor (line 4).** VL53L1X laser ranging breakout, about 13 x 18 mm, sensor on the underside.
- **Radio module (line 5).** RAK3172 on its maker's breakout, built for the band of the pilot region.
- **Electronics parts (line 6).** As Table 2, with the perforated board.
- **Cell, holder and strap (line 7).** C size lithium thionyl chloride cell (ER26500 class), 3.6 V, about 8.5 Ah, rated for pulses of at least 100 mA, from a maker that publishes a data sheet; a through-board holder; a 10 mm hook-and-loop strap.
- **Antenna (line 8).** Flexible 868/915 MHz adhesive antenna with a u.FL lead.
- **Vent (line 9).** M8 ePTFE pressure-equalising vent with its nut.
- **Box fixings (line 10).** Four M4 x 12 flush-head press-in studs for aluminium sheet; four M4 x 30 aluminium hex standoffs, female both ends, 7 mm across flats; four M4 bonded sealing washers; four M4 x 8 pan-head screws; four M3 x 4 nylon standoffs with M3 nylon screws; one M3 x 4 nylon-tipped grub screw.
- **Printed mounts and window (line 11).** ASA filament, the window disc, two-part epoxy for plastics and neutral-cure silicone sealant.
- **Test lid.** A piece of 5 mm HDPE sheet about 220 x 140 mm, drilled with the plate as a template, stands in for the bin lid.

## 4. Putting it together

In each picture the parts already fitted are grey and the parts being fitted are in colour, with an arrow showing the way they go in. Several pictures look up from below, because the unit hangs under the lid.

### Step 1: press the studs into the plate

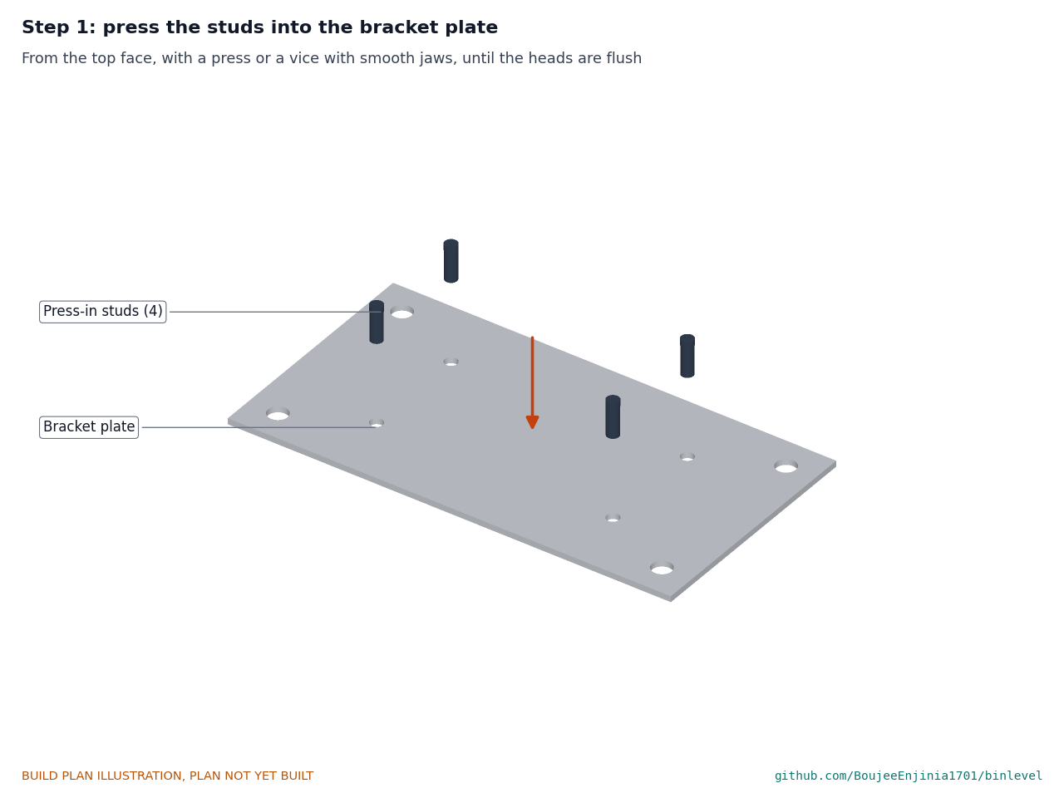
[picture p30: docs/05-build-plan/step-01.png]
Step 1


From the top face, until the heads are flush (section 3.1).

### Step 2: base onto the plate

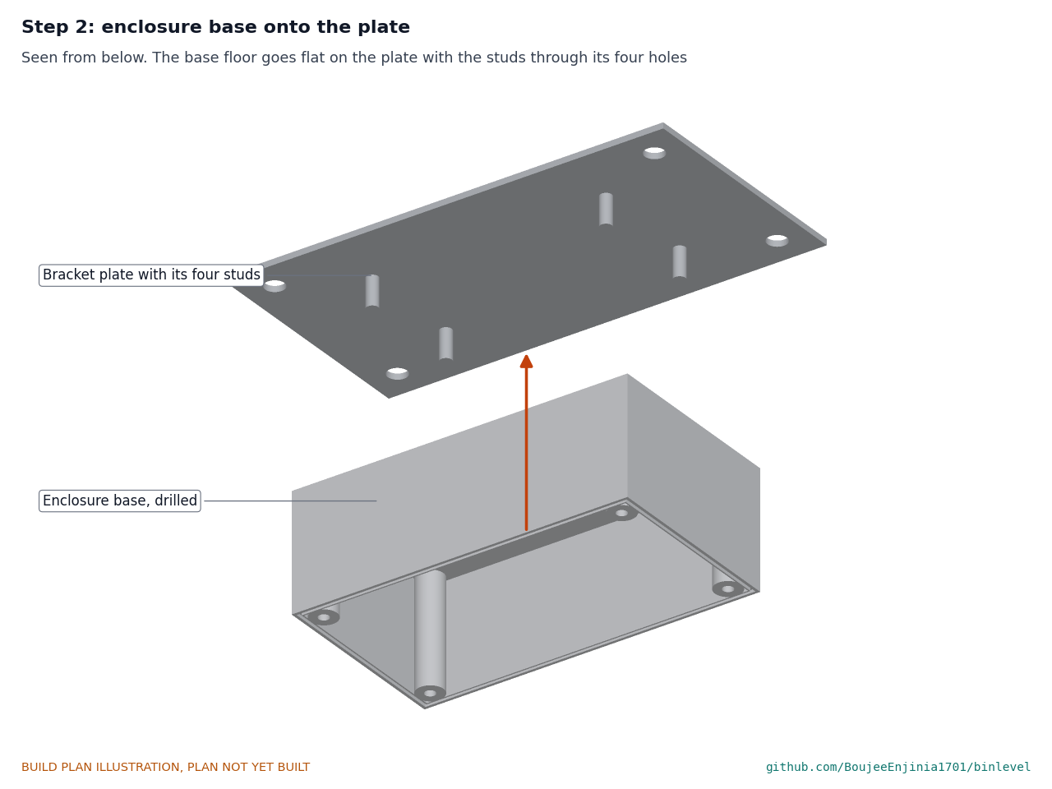
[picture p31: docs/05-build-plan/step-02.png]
Step 2


Hold the plate top face down on the bench. Put the base on it, floor down, with the four studs through the floor holes.

### Step 3: sealing washers and standoffs onto the studs

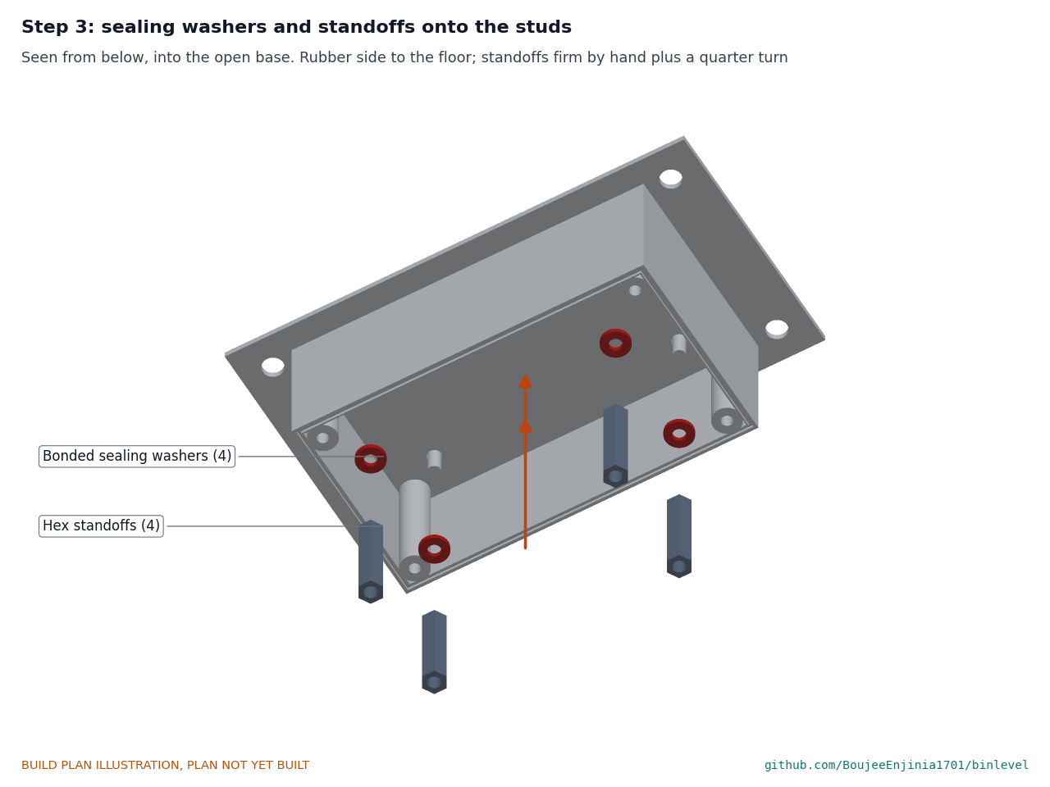
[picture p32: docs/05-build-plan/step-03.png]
Step 3


On each stud, inside the base: a bonded sealing washer, rubber side to the floor, then a 30 mm standoff, hand tight plus a quarter turn with a 7 mm spanner. **Hold point:** the base does not move on the plate when pushed by hand.

### Step 4: antenna onto the inner wall

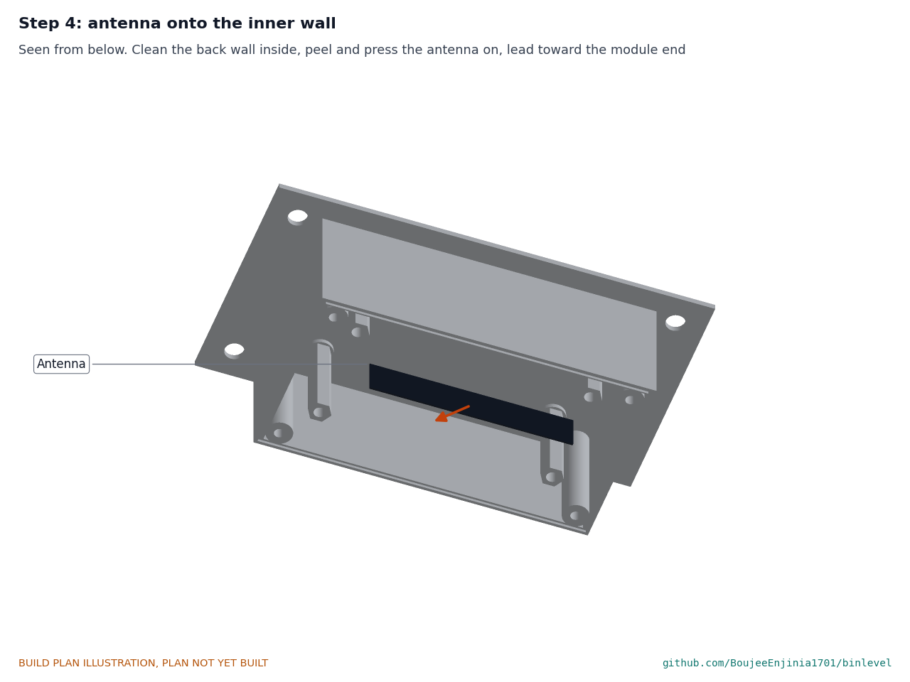
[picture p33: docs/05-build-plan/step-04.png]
Step 4


Clean the inside of the back wall with isopropyl alcohol on a cloth and let it dry. Peel the antenna and press it on, 3 to 15 mm from the floor, centred, with its lead toward the end where the radio module will sit.

### Step 5: build the electronics board

Step 5

Solder the radio module, board sensors, power parts, capacitor and the cell holder (no cell) to the board as section 3.3 describes, then wire them as Figure 8. **Hold point:** safety stop S2 (section 6).

### Step 6: driver board under the board

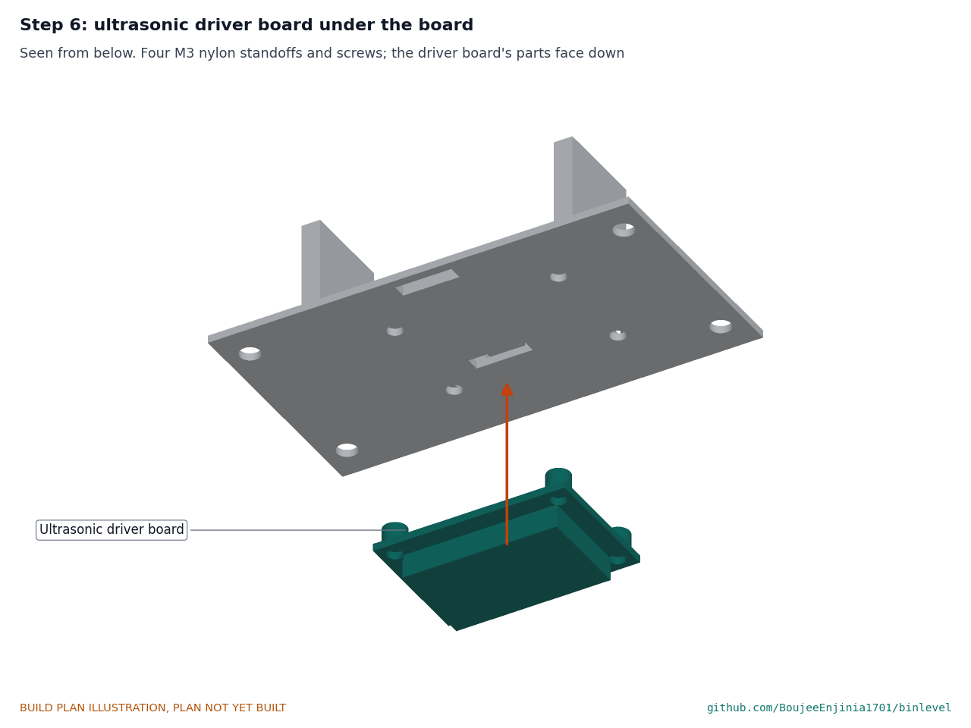
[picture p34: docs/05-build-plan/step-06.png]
Step 6


Four 4 mm nylon standoffs and M3 nylon screws, its parts facing down. Plug its supply, trigger and echo wires to the board.

### Step 7: cell and strap

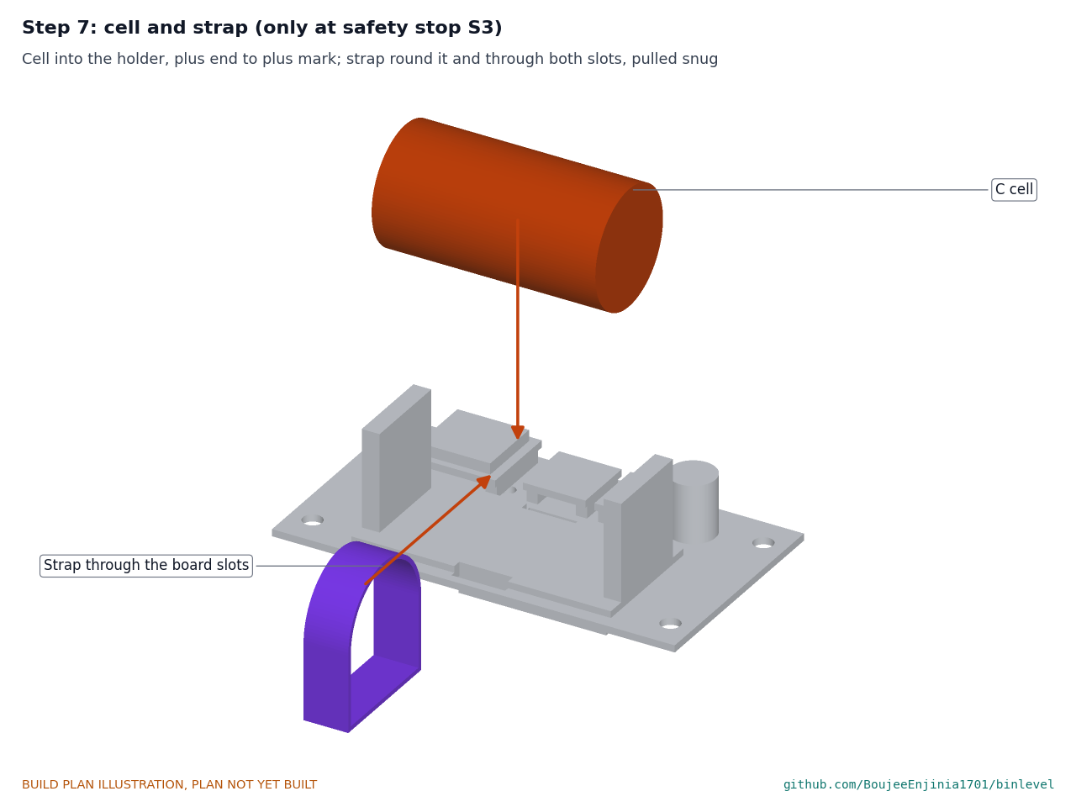
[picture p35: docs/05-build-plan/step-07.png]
Step 7


**Only at safety stop S3.** Put the cell in the holder with its positive end at the holder's plus mark, checked with a meter, not by colour. Pass the strap round the cell, through both slots and under the board, and pull it snug.

### Step 8: electronics board into the base

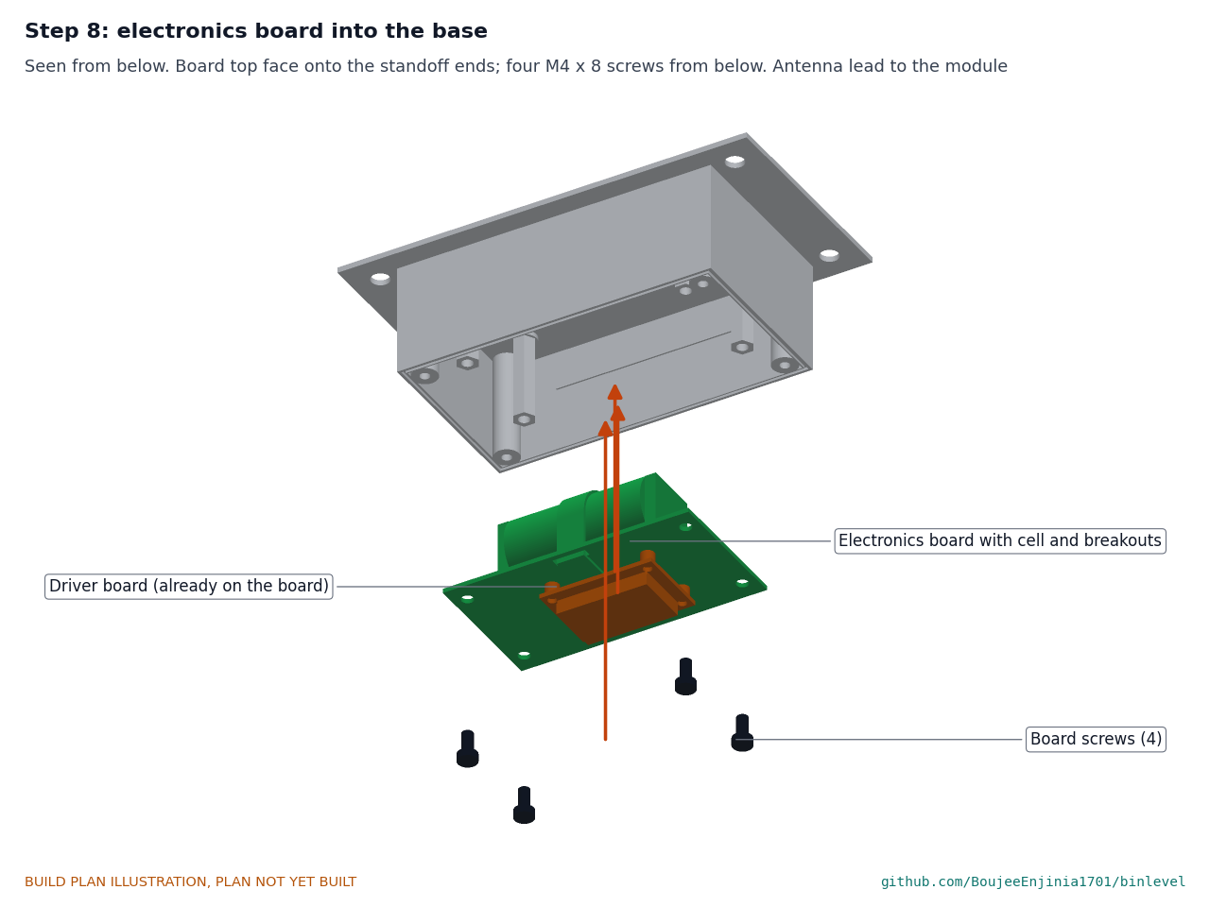
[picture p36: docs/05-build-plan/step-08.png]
Step 8


Plug the antenna lead into the module. Hold the board top face up into the base and fit four M4 x 8 screws through it into the standoffs. No wire may lie across the base rim.

### Step 9: transducer and collar into the cover

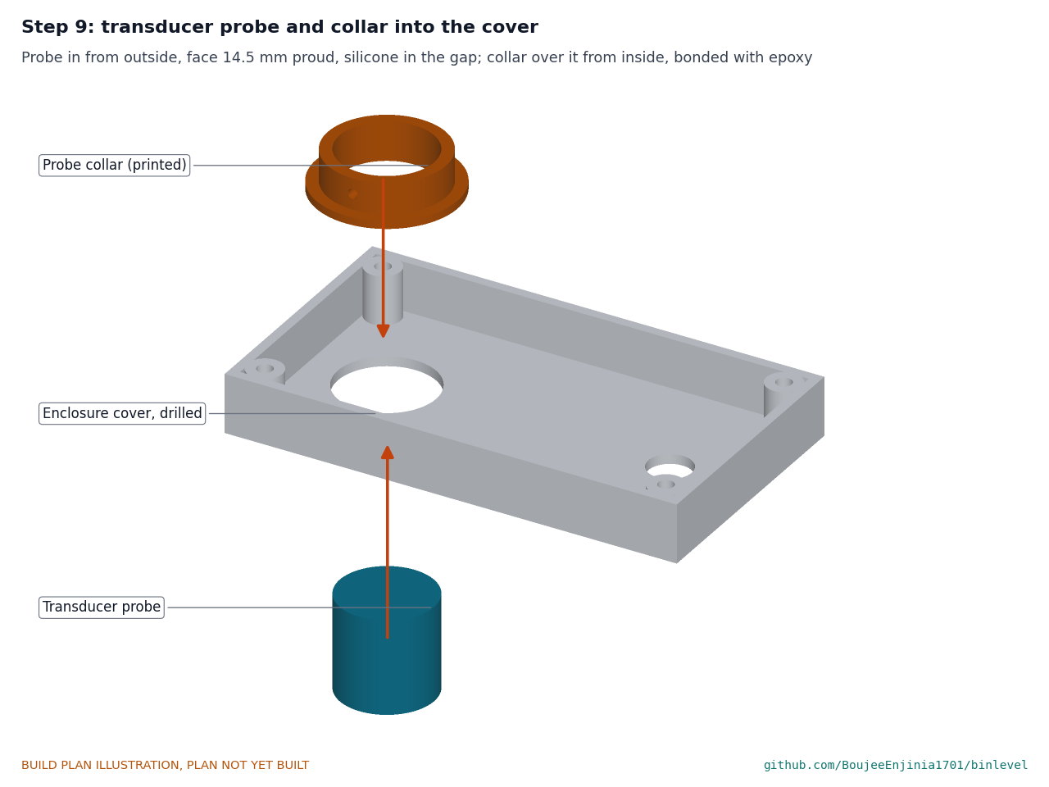
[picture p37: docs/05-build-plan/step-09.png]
Step 9


Push the probe through the 25 mm hole from outside until its face stands 14.5 mm proud of the cover. Run a bead of neutral-cure silicone round the probe in the hole. From inside, slide the collar down the probe onto the floor, its screw hole toward the front, and bond the flange to the floor with two-part plastics epoxy. Leave both to cure for 24 hours, then fit the grub screw finger tight.

### Step 10: window, holder and light sensor into the cover

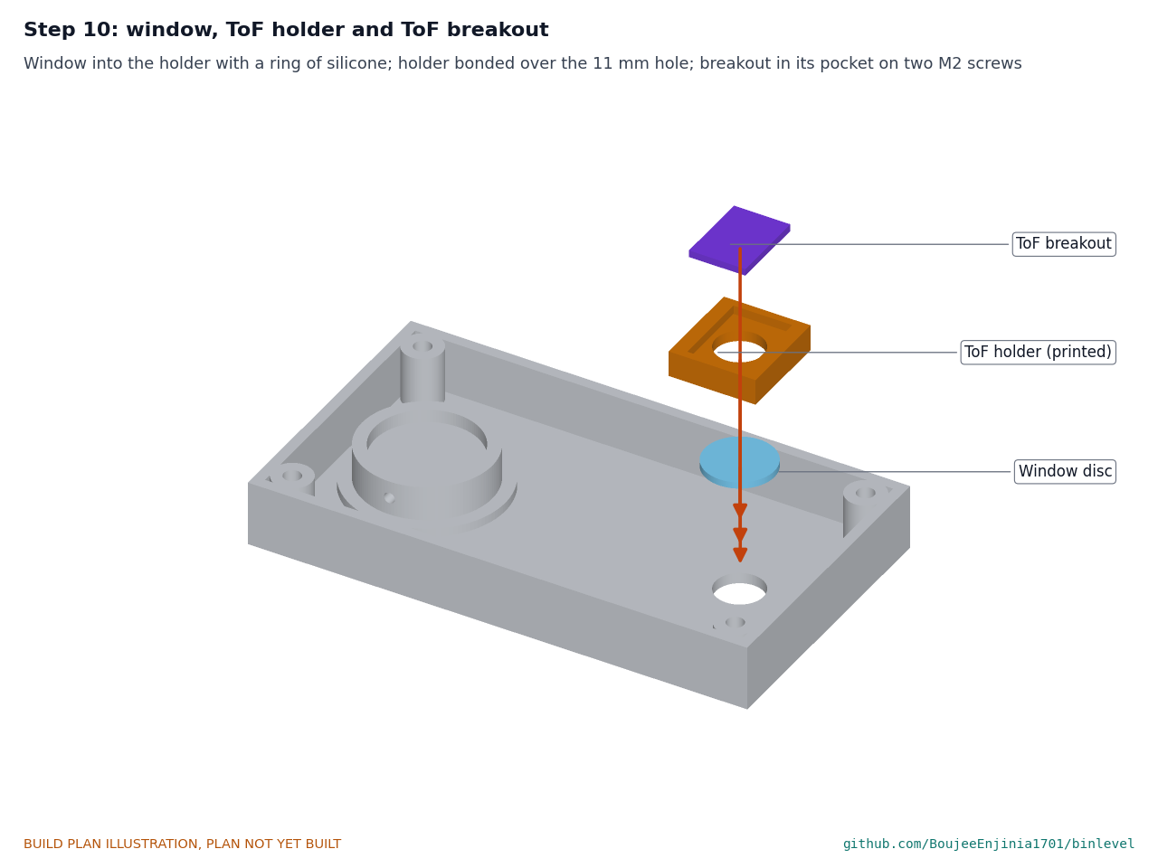
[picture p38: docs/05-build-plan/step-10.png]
Step 10


Peel the window film. Put a thin ring of silicone on the window's outer face and press it into the holder's recess. Bond the holder over the 11 mm hole with plastics epoxy, the window toward the floor, and leave it to cure. Fit the breakout in the top pocket, sensor down, with two M2 screws.

### Step 11: vent into the cover

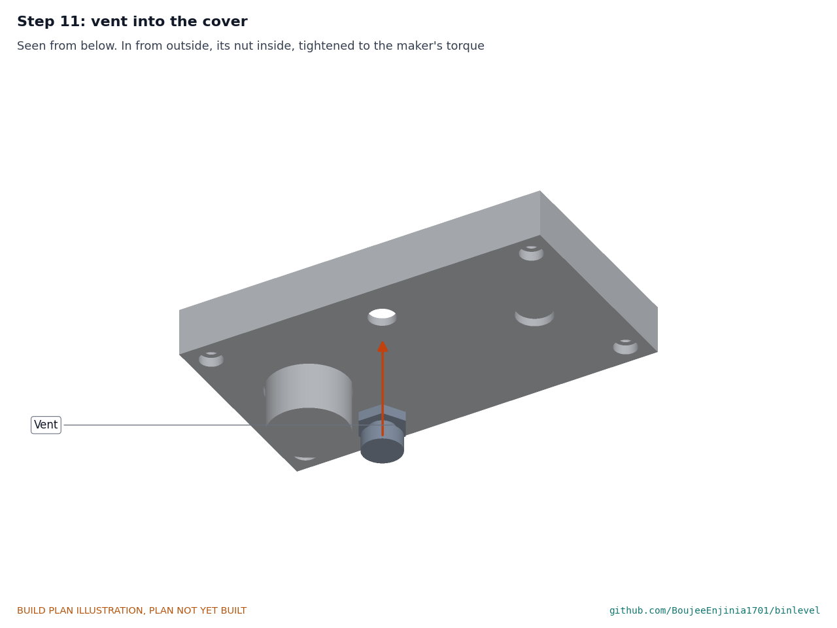
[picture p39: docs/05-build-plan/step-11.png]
Step 11


In from outside, its nut inside, tightened to the maker's torque.

### Step 12: close the cover

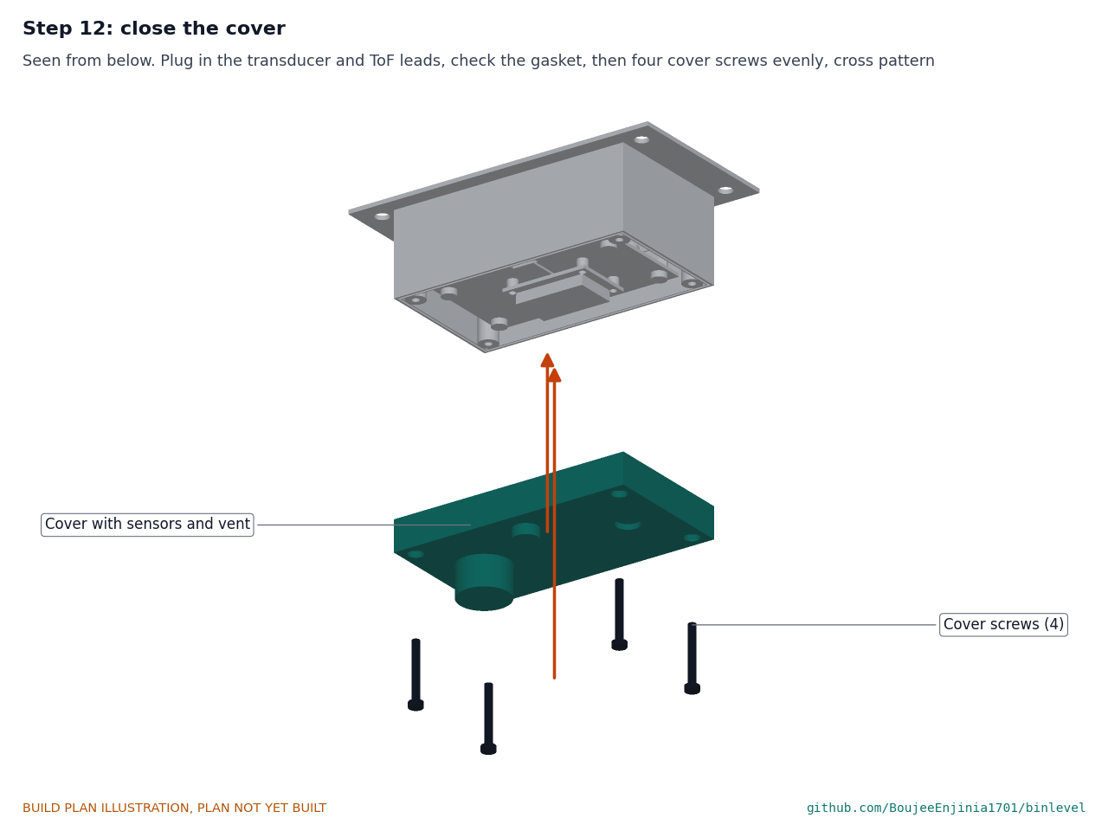
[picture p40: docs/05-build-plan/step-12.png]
Step 12


Plug the transducer cable into the driver board and the light sensor lead into its socket on the board. Check that the gasket is clean and seated in its groove with no wire across it. Offer the cover up and tighten the four cover screws evenly in a cross pattern. **Hold point:** safety stop S4 before the radio transmits.

### Step 13: unit onto the lid

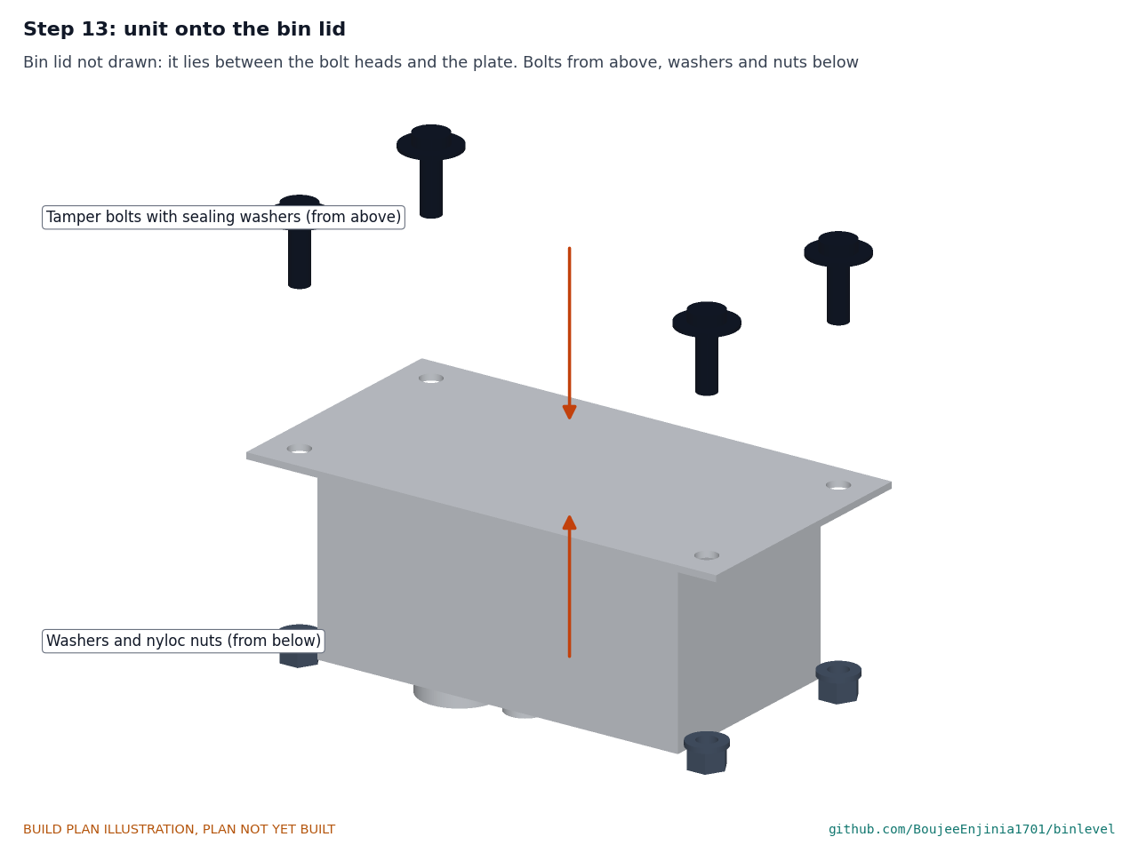
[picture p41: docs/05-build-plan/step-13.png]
Step 13


Drill the test lid through the plate's four bolt holes at 7 mm. Hold the plate flat against the lid's underside. From above, put a sealing washer on each bolt and pass it down through the lid and the plate; below, fit a plain washer and a nyloc nut. Hold each nut with a 10 mm open spanner from the side and tighten from above with the tamper driver. **Hold point:** safety stop S5.

## 5. First checks

These are the checks a TRL 4 test report would record; this plan only lists them. Requirement numbers are those of BNL-REQ-001.

*Table 3. First checks.*

| Check | Requirement | How | Pass when |
| --- | --- | --- | --- |
| Seals seated | R5 | Look at the gasket, the vent, the probe and the window under a lamp, cover closed | Gasket evenly squeezed all round; silicone bead unbroken; no gaps (the spray test comes later) |
| Size and mass | R16 | Measure the unit on the test lid; weigh it without the lid | 71.5 mm or less below the lid, within 150 x 80 mm; 400 g or less (about 350 g estimated) |
| Supply rails | R4, R6 | Cell out, bench supply at 3.6 V, current limit 50 mA, in place of the cell; measure the 3.3 V rail | 3.3 V, give or take 0.1 V; no part warm to the touch |
| Sleep current | R4 | Same supply, unit asleep, meter in series | About 6 µA (the calculation's figure); record the value |
| Sensors switched off in sleep | R4 | Measure the supply at the driver board and light sensor plug while asleep | 0 V |
| Ranging | R1 | Cell in, cover closed, unit face down above a flat board at 0.1, 0.3, 0.5 and 1.0 m | Light sensor reads 0.1 and 0.3 m, transducer reads 0.3 to 1.0 m, each within 20 mm |
| Tilt wake | R8 | Tip the unit through 90° | The module wakes and logs a tip event |
| Radio | R10, R15 | Unit near a gateway on the pilot region's band | Joins the network and sends an 11-byte uplink that the open decoder reads |
| Fixing | R7, R12, R13 | Fit the unit to the test lid with a stopwatch; try the bolt heads with an ordinary hex key | Fitted in 10 minutes or less; nothing moves when pushed by hand; the heads cannot be turned without the tamper driver |

## 6. Safety stops

Stop at each point. Carry on only when everything listed is true.

- **S1. Before the cell comes into the workshop.** The cell has its maker's data sheet; its voltage is about 3.6 to 3.7 V; it is not swollen, dented, leaking or warm. It is stored in its packaging away from metal objects, on a non-combustible surface, with dry sand or a Class D or lithium-rated extinguisher within reach; never water on a lithium metal cell.
- **S2. Before the board is powered for the first time.** No cell in the holder. The fuse is in the cell lead. With a meter, no rail reads a short to ground, and the holder's polarity matches the wiring. The bench supply is set to 3.6 V with a 50 mA current limit and connected at the holder's leads, never across the cell.
- **S3. Before the cell goes in.** The bench checks of section 5 (supply rails, sleep current, sensors switched off) pass. The bench supply is disconnected and stays disconnected while the cell is in: a supply connected across a primary cell would charge it, which can make it vent or burst. The strap is ready to go round the cell straight away.
- **S4. Before the radio transmits.** The antenna is plugged into the module and matches the pilot region's band. Transmitting without an antenna can damage the radio.
- **S5. Before the unit goes near a real bin (outside this plan).** Only on an emptied and cleaned container, with cut-resistant gloves and eye protection; drill swarf kept out of the container; clear of the lifting gear of collection trucks. The temperature alert is a maintenance aid and never fire detection.

## 7. Tools, skills and workspace

**Tools.** Hacksaw or bandsaw with a fine blade; bench vice with smooth jaws (or a small arbor press); bench drill or a drill in a stand; drills 1.5 to 7 mm; a step drill to 25 mm (or a 25 mm hole saw); M3 tap and tap wrench; deburring tool; flat and needle files; scriber, steel rule, engineer's square and calipers; 3D printer with an enclosure that prints ASA; temperature-controlled soldering iron, solder and flux; wire strippers; multimeter with a microamp range; bench power supply with an adjustable current limit; 7 mm and 10 mm spanners; small screwdrivers; the tamper-bolt driver; scale to 1 kg; stopwatch; mixing sticks and gloves for epoxy.

**Skills.** No certified trade is needed. Basic metalwork (marking out, drilling, filing, a press fit), careful drilling of thin plastic, through-hole soldering, safe use of a bench power supply and care with lithium metal cells. All circuits are extra-low voltage: 3.6 V at the cell and 3.3 V on the board. The bench supply must be a certified, undamaged unit; no mains wiring is part of this build.

**Workspace.** A bench about 1.2 x 0.6 m; a metalwork corner kept apart from the electronics so chips stay off the boards; a ventilated place for the printer, epoxy and silicone; the cell storage place of S1.

**Personal protective equipment.** Safety glasses for cutting, drilling and soldering; nitrile gloves for epoxy and silicone; cut-resistant gloves for sheet edges; no gloves near a turning drill.

## 8. Where the numbers come from

- Model and constructability checks: `cad/src/model.py` (`python cad/src/model.py --check`); STEP and STL exports in `cad/step/` and `cad/stl/`.
- Pictures: `cad/src/build_plan_media.py`, using `.kit/build_views.py`; written to `docs/05-build-plan/` and `cad/drawings/BNL-DWG-101` to `BNL-DWG-106`.
- General arrangement: `cad/drawings/BNL-DWG-001.pdf`, Rev P5.
- Calculations: `docs/04-calcs/01-sizing.md` (BNL-CAL-001 v0.5) and `docs/04-calcs/sizing.py`; geometry [A1] to [A3], mass and size [I1], [I3], fixing [J1] to [J3], cost [K1].
- Bill of materials: `bom/bom.csv`.
- Decisions: `docs/decisions/0003-design-for-construction.md` (BNL-DDR-003), with BNL-DDR-001 and BNL-DDR-002.
- Requirements: `docs/03-requirements.md` (BNL-REQ-001 v0.5).

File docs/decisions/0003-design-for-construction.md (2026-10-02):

---
doc_id: BNL-DDR-003
title: BinLevel design for construction
project: BinLevel
doc_type: Design decision record
version: "0.3"
status: Draft
date: '2026-10-02'
author: Amish Chadha
license: CERN-OHL-S-2.0
revisions:
- version: "0.1"
  date: '2026-09-30'
  author: Amish Chadha
  change: Changes that make the concept physically buildable, with the reason for each; made under Amish's 2026-09-30 instruction and open for his review
- version: "0.2"
  date: '2026-10-01'
  author: Amish Chadha
  change: Budget treated as a value-engineering target
- version: "0.3"
  date: '2026-10-02'
  author: Amish Chadha
  change: Accepted by Amish, including the recommendation for A2
---

# 0003: Design for construction

- **Date:** 2026-09-30
- **Status:** accepted. Amish, 2026-10-02: "i approve your recommendations for all 555 open decisions." This covers every change in Tables 1 and 2 and the recommendation for A2, now decided as recommended and recorded in the design decisions register (BNL-DEC-001). A1 is a value-engineering note, not a decision; it is carried in the register's Value engineering section. Made under Amish's 2026-09-30 instruction to make the design physically buildable. Nothing here changes what BinLevel does, its pitch or its safety case.

## Context

On 2026-09-30 Amish asked for every repo to carry an illustrated prototype build plan that shows how each component is made and how it fits the next, and wrote: "If you are realising that the design cannot be built as per concept - fix the design assumptions to match and be physically feasible as you draw the illustrations." The TRL 3 model of BNL-DDR-002 was a massing model: it showed what BinLevel does, but several of its parts floated, overlapped or had no fixing, and one bought part (the ultrasonic driver board) was missing. Checking the model with build123d found the eleven problems below. The review note of 2026-09-26 had already found three of them (the bolt shank above the head, the nut inside the plate and the missing sealing washer).

The changes keep what the unit does: the same sensing (ultrasonic plus ToF, same positions along the box), radio, cell, antenna, mounting under the lid with four tamper bolts on the same 130 x 60 mm pattern, and the same privacy and safety features. Every change is in `cad/src/model.py`, which now builds every component by name and runs 192 constructability checks (`python cad/src/model.py --check`): no two parts overlap, the 32 pairs that must touch do touch, the 0.5 mm gap round the transducer is within what silicone can fill, 22 clearances are met, every part touches at least one other, and the unit fits the R16 envelope. All 192 pass.

## Decision

*Table 1. Changes made to the model, the BOM and the calculations.*

| # | Problem in the concept | Change made | Why this way |
| --- | --- | --- | --- |
| P1 | The box had no fixing to the bracket. Two 60 x 30 mm end tabs hung from the plate to "clamp the enclosure ends", but nothing held them to the box, and their fold lines lay 16.5 mm in from the plate ends, so they could not be folded from a flat blank. | Tabs removed. Four M4 x 12 flush-head press-in studs in the plate (80 x 36 mm pattern) pass through 4.5 mm holes in the base floor; inside, an M4 bonded sealing washer and an M4 x 30 hex standoff go on each stud and clamp the base to the plate. | The plate's top face stays flat against the lid (the stud heads are flush), the box seals at each hole, and the standoffs also carry the electronics board. Press-in studs are a routine sheet-metal shop operation. Each stud carries 12 N at 20 g against a pull-through strength of about 2,100 N [J3]. |
| P2 | The M6 x 40 bolts ran 2.7 mm above their heads and 24 mm below the nut; the nyloc nuts overlapped the plate by 2 mm; the sealing washers were in the BOM but not the model. | M6 x 20 tamper bolts with an 18 mm sealing washer under each head on top of the lid; an M6 plain washer and nyloc nut under the plate, 1.5 mm clear of the box end. | Grip of 16 mm plus two threads. The nut is turned with an open spanner from the side while the bolt is held from above. |
| P3 | The ultrasonic module's driver board (about 41 x 28 mm, part of BOM line 3) was not in the model, and there was no room for it in a 45 mm tall box. | Box height 45 to 55 mm (115 x 65 x 55 mm). The driver board hangs under the electronics board on four 4 mm nylon standoffs, between the transducer and the ToF holder. | The cell (26 mm) above the board and the driver board and sensors below it need 50 mm inside. The unit is now 71.5 mm below the lid, inside R16's 100 mm. |
| P4 | The carrier board floated at mid height with no fixing, cut 0.1 mm into the top of the transducer, and at 105 x 55 mm clashed with the corner screw towers that every stock box has. The board layout is TRL 4 work. | For the prototype, a 90 x 50 mm perforated prototyping board with bought breakouts stands in for the carrier PCB. It hangs from the four standoffs on M4 x 8 screws, 10 mm above the transducer. | Same function and parts; clear of the towers by 1.6 mm. Board slots carry the cell strap (P9). |
| P5 | The transducer sat in its 25 mm hole with nothing holding it. | A printed ASA collar slides over the probe inside the cover and is bonded to the floor with plastics epoxy; an M3 nylon-tipped grub screw clamps the probe; neutral-cure silicone fills the 0.5 mm gap in the hole. | Holds the probe at its 14.5 mm protrusion without new holes in the box, and lets the probe be replaced. |
| P6 | The ToF board floated 4.8 mm above the floor, and the window was drawn as a plug inside the 11 mm hole. | A printed ASA holder is bonded over the hole. It holds a 16 x 1.5 mm PMMA or glass window disc against the floor (sealed with silicone) and the breakout, sensor down, in a pocket 3.5 mm above the window. | The window seals from inside, so water pressure pushes it onto its seat. |
| P7 | The M8 vent was in BOM line 9 but not in the model. | Vent in the cover floor on the short centre line, 20 mm toward the front edge, facing down, its nut inside. | Faces down so it drains; clear of the driver board by 4.8 mm. |
| P8 | The gasket was drawn as a ring outside the box walls, cutting into them. The box was one solid. | Box modelled as a base (fixed to the plate) and a 15 mm cover (carrying the sensors), with the stock gasket in the base rim groove, four corner screw towers and four cover screws. | Matches a stock IP67 box; the cover faces down, so it is opened from below with the bin lid lifted. |
| P9 | The cell floated 2 mm above the board in no holder. | Cell holder on the board's top face; a 10 mm hook-and-loop strap passes round the cell and through two 12 x 3 mm slots in the holder base and the board. | Retains the cell at 20 g (10 N needed [J2]). |
| P10 | The radio module floated above the board. | The RAK3172 on its maker's breakout, on 3 mm header pins. | Bought part for the prototype. |
| P11 | The sensors in the cover were wired to the board with no way to take the cover off. | The transducer cable and a six-way ToF lead end in plugs at the board. | The cover comes away from below once both plugs are out. |

*Table 2. Knock-on changes.*

| Item | Change | Reason |
| --- | --- | --- |
| Mass | 334 to 350 g, inside R16's 400 g [I1]. | Taller box (+20 g), fixings (+22 g), printed parts (+5 g); tabs (-20 g) and shorter bolts (-12 g) removed. |
| Envelope | Below the lid 150 x 80 x 61.5 mm to 150 x 80 x 71.5 mm (R16: 160 x 90 x 100) [I3]. | Box 10 mm taller. |
| Measurement geometry | Transducer face to container floor 1,011 to 1,000 mm; 80 % fill now 200 mm below the face; ultrasonic reads to 75.0 % fill and ToF from 60.0 %; R2 allowance ±100 mm [A1] to [A3], [B3]. | The face is 10 mm lower. R1 and R2 status unchanged. |
| Shock | 66 to 69 N on the fixing [J1]; new check of the studs [J3]. | Heavier unit. |
| Cost | BOM lines 1, 2, 3, 6, 7 and 9 respecified; lines 10 (box fixings, $2.50) and 11 (printed mounts and window, $1.50) added. Parts $55.00 to $59.00, within the unchanged $60 value-engineering target (`budget_usd`) by $1.00 [K1]; with the external lid antenna (O1) $67.00 [K2]. | Parts added for construction. |
| Drawings | BNL-DWG-001 Rev P4; making sketches BNL-DWG-101 to 106 added. | Follows the model. |
| Documents | BNL-CAL-001 v0.3, BNL-REQ-001 v0.5, BNL-PRC-001 v0.5: mass, envelope, geometry and cost figures updated. No requirement changed status. | Follows the model. |
| Thermal and radio | Unchanged. The unit's assumed heat capacity (400 J/K) already covered about 0.4 kg; the antenna stays on the inner back wall. | |

*Table 3. Items proposed for Amish; A2 accepted as recommended on 2026-10-02.*

| # | Question | Options | Recommendation |
| --- | --- | --- | --- |
| A1 | Value engineering (a note, not a decision). The estimated cost is $59.00 against the $60 value-engineering target, $1.00 under. | (a) confirm prices at TRL 4; (b) look for savings now (for example a cheaper generic box). | (a). |
| A2 | Swapping the cell now means lowering the electronics board (four screws) after the cover is off; the cell lasts about 16 years, so this is rare. | (a) accept; (b) move the cell below the board, which needs a taller box again. | (a). Accepted by Amish, 2026-10-02. |

## Consequences

- With A2 accepted, a cell swap means lowering the electronics board on its four screws after the cover is off.
- `design_state: constructable` in `project.yaml`. The build plan BNL-BLD-001 shows every component and step in pictures generated from the model (`cad/src/build_plan_media.py`).
- Requirement status is unchanged: not met 2 (R5 IP69K, R10 in steel containers), at risk 2 (R2, R6), not verifiable at TRL 3 2 (R7, R12), met 10 (BNL-CAL-001 v0.3).
- The photoreal renders (`media/render-*.png`), `media/card.png`, `media/social-preview.png` and the appearance model `cad/src/product_model.py` still show the concept: 45 mm box, end tabs and a full-size board. They need updating on Amish's Mac, where Blender is.
- The stock box, the transducer, the driver board, the ToF breakout and the studs are chosen at TRL 4; their sizes must be checked against the model then (design decisions register, "To confirm when parts are bought").

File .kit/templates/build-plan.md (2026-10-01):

---
doc_id: PRJ-BLD-001
title: Project prototype build plan
project: Project name
doc_type: Build plan
version: "0.1"
status: Draft
date: YYYY-MM-DD
author: Amish Chadha
license: CERN-OHL-S-2.0
revisions:
  - version: "0.1"
    date: YYYY-MM-DD
    author: Amish Chadha
    change: First build plan; design made constructable
---

# Project prototype build plan

**Plan, not yet built.** How to build the first proof-of-concept prototype, component by component. Building and testing to it is TRL 4 work. Decisions still to be made are kept in the design decisions register (`docs/06-design-decisions.md`), not here.

## 1. What you are building

Every component, pulled apart and numbered in build order

One short paragraph: what the prototype is, how many components, which are made and which are bought, and the main ways they are made.

## 2. What changed to make it buildable

| Component | The concept had | The buildable design has | Why |
| --- | --- | --- | --- |

## 3. Making the components

### 3.1 Component name

Making sketch

**What it is and what it is made from.**

**How to make it.**

1. Mark out ...
2. Cut ...

**How it fits the parts next to it.**

Close-up of the joint

**Check before moving on.**

## 4. Putting it together

### Step 1: ...

Step 1

## 5. First checks

| Check | Requirement | How | Pass when |
| --- | --- | --- | --- |

## 6. Safety stops

## 7. Tools, skills and workspace

## 8. Where the numbers come from

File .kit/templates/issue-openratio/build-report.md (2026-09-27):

---
name: Build report
about: Tell us what happened when you built, printed or tested part of this design
title: "Build report: "
labels: build-report
---

This is a research and educational prototype, not a medical device. It is a TRL 3 concept and is not released for fabrication. If you build any part of it, you do so at your own risk. Reports help everyone.

**What you built** (part, sub-assembly or test)

**Materials, tools and settings**

**What worked**

**What did not work, with photos or measurements if you have them**

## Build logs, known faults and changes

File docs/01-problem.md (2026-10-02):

---
doc_id: BNL-PRB-001
title: BinLevel problem statement
project: BinLevel
doc_type: Problem statement
version: "0.5"
status: Draft
date: '2026-10-02'
author: Amish Chadha
license: CERN-OHL-S-2.0
revisions:
- version: "0.1"
  date: '2026-09-25'
  author: Amish Chadha
  change: Initial scaffold
- version: "0.2"
  date: '2026-09-25'
  author: Amish Chadha
  change: Users, context, constraints, prior work with sources and open questions for TRL 2
- version: "0.3"
  date: '2026-09-25'
  author: Amish Chadha
  change: Target container adopted for TRL 3 (BNL-DDR-001, D1); lid temperature updated from BNL-CAL-001
- version: "0.4"
  date: '2026-09-25'
  author: Amish Chadha
  change: Recommendations accepted by Amish (DDR-002)
- version: "0.5"
  date: '2026-10-02'
  author: Amish Chadha
  change: First partner to approach, steel containers out of the first pilot and pilot data layer, as decided on 2026-10-02 (BNL-DEC-001)
---

# BinLevel problem statement

Most municipal waste is still collected on a fixed timetable, so crews drive to bins that are half empty while others overflow between visits. The collection service has no cheap way to know how full each bin is. BinLevel is a low-cost, open, battery-powered fill-level sensor that sits under the lid of a communal or public bin and reports its fill level by LoRaWAN radio, so routes can be planned around bins that need emptying.

## Why it matters

Waste collection is one of the largest services a city runs, and it is growing. The World Bank estimates that 2.56 billion tonnes of municipal waste were produced in 2022 and that this will reach 3.86 billion tonnes by 2050 under business as usual ([World Bank, *What a Waste 3.0*](https://www.worldbank.org/en/publication/what-a-waste)). UNEP puts the global direct cost of waste management in 2020 at about USD 252 billion ([UNEP, *Global Waste Management Outlook 2024*](https://www.unep.org/resources/global-waste-management-outlook-2024)).

Where budgets are thin, collection coverage is low: the World Bank reports collection rates as low as 31 % in Sub-Saharan Africa and 67 % in South Asia, and public spending on waste in most low- and middle-income countries is well below 0.15 % of GDP, against about 0.3 to 0.5 % needed for basic collection ([World Bank](https://www.worldbank.org/en/publication/what-a-waste)). Every truck trip spent on a half-empty bin is a trip not spent on an overflowing one.

## Users and context

| User | Need | Context |
| --- | --- | --- |
| Municipal waste service or contractor (route planner) | Know which bins are near full before the crew leaves the depot | Daily or weekly routes; dispatch office with a laptop |
| Collection crew | Fewer wasted stops; warning of overfull or burning bins | Truck cab, phone or printed route |
| Housing estates, markets, campuses, parks | Keep communal bins from overflowing without paying for extra lifts | Shared 660 to 1,100 L containers or street litter bins |
| Community groups and small towns | A sensor they can build, repair and own, feeding their own map | Often no budget for commercial subscriptions |
| Residents and passers-by | Clean streets; no surveillance | The sensor must be visibly harmless: no camera, no microphone |

**Target containers (decided by Amish, 2026-09-25: go with recommendation; BNL-DDR-001, D1).** The first design case is the four-wheel communal container of the EN 840 class (660 to 1,100 L, plastic or steel, flat or domed lid), with public street litter bins (50 to 240 L) as a second case. The concept model uses an 1,100 L container of typical size (about 1,370 x 1,070 x 1,340 mm outer, an estimate from common catalog dimensions).

**Operating environment.** Outdoors under the lid, shaded but in a closed box that can reach high temperatures in sun (a dark lid reaches about 67 °C on a 40 °C day in full sun, and a light lid about 55 °C; estimates from BNL-CAL-001, section H) and below freezing in winter; condensation, food waste acids, dust and insects; repeated shocks when the bin is lifted and tipped into the truck; and periodic washing, sometimes with hot pressure water.

## Constraints

- Garage-buildable prototype, about $60 USD in parts per sensor (the `budget_usd` in `project.yaml`); the gateway is separate and shared.
- Off-the-shelf modules and a stock enclosure; no custom tooling at TRL 2 to 3.
- Battery only: no wiring to the bin and no solar panel, because lids are opened, slammed and tipped.
- Open radio: LoRaWAN, so it works with any network server, including the lab's TwinKit gateway and The Things Network (TTN).
- Privacy by design: counts and levels only. No images, audio or personal data leave the device, and the device has neither a camera nor a microphone.
- Radio rules: EU868 sub-bands are limited to a 0.1 % to 1 % duty cycle under ETSI EN 300 220, and TTN's fair use policy allows 30 s of uplink airtime per device per day ([TTN](https://www.thethingsnetwork.org/docs/lorawan/duty-cycle/)).

## Out of scope

- Route optimization software itself (BinLevel feeds a standard open-source vehicle routing tool through the lab's TwinKit project as the data layer, or a city system if the pilot partner already runs one; decided 2026-10-02).
- Compaction, bin redesign or collection vehicles.
- Waste identification or sorting (that is the WasteWise family).
- Certified fire detection. A temperature alert is a maintenance aid, not a safety system.

## Prior work

- **Commercial ultrasonic bin sensors.** Sensoneo sells single-beam and four-beam ultrasonic bin sensors with replaceable batteries, accelerometers for tilt and pickup detection, a temperature reading and LoRaWAN, Sigfox or NB-IoT radios ([Sensoneo product page](https://www.sensoneo.com/products/ultrasonic-bin-sensor/)). The vendor reports a Prague deployment of more than 3,000 sensors and claims about $156 of savings per bin per year ([Sensoneo](https://sensoneo.com/)); this is a vendor claim, not an independent result.
- **Sensing compactor bins.** Bigbelly sells solar compacting street bins with fullness reporting and claims that its data can reduce collections by 80 % ([Bigbelly](https://bigbelly.com/)); again a vendor claim, and a whole-bin replacement rather than a retrofit.
- **Gap.** Commercial sensors are closed and sold with a subscription. There is no widely used open, documented retrofit sensor that a small town, campus or community group can build for tens of dollars and connect to its own LoRaWAN network. BinLevel aims to fill that gap by using the same principle (ultrasonic ranging, tilt and temperature) with open hardware and a documented payload.

## Open questions

- [ ] Which container types and lid materials dominate in the first partner city? Steel containers block the radio if the antenna sits inside (BNL-CAL-001 gives about 0.35 km of range); steel containers are left out of the first pilot, which uses plastic containers only (decided by Amish, 2026-10-02; BNL-DDR-001, O1).
- [x] Is an ultrasonic blind zone of about 0.25 m acceptable, or must the top 20 % of the bin be measured directly? Measured directly: the ToF sensor covers the top 0.4 m (BNL-DDR-001, D2; BNL-CAL-001, section A).
- [ ] How are containers washed (hot pressure water needs IP69K-class sealing)?
- [ ] Who owns the data and the gateway: the city, the contractor or a community group?
- [ ] What fill threshold triggers a collection for each waste stream (general, recycling, organics)?

## User research and co-design

This design is for communities the author is not part of, so requirements come from the people who will use it.

- [ ] Identify a local partner organization. First candidate to approach (decided 2026-10-02, not yet agreed): a municipal waste service or its contractor using EN 840 plastic communal containers in a city with public LoRaWAN coverage, by default a European city on the EU868 band
- [ ] Run co-design sessions with intended users; record who, where and what was learned
- [ ] Validate load, distance, terrain and cost assumptions in the field
- [ ] Revise requirements (REQ) from findings before freezing the design

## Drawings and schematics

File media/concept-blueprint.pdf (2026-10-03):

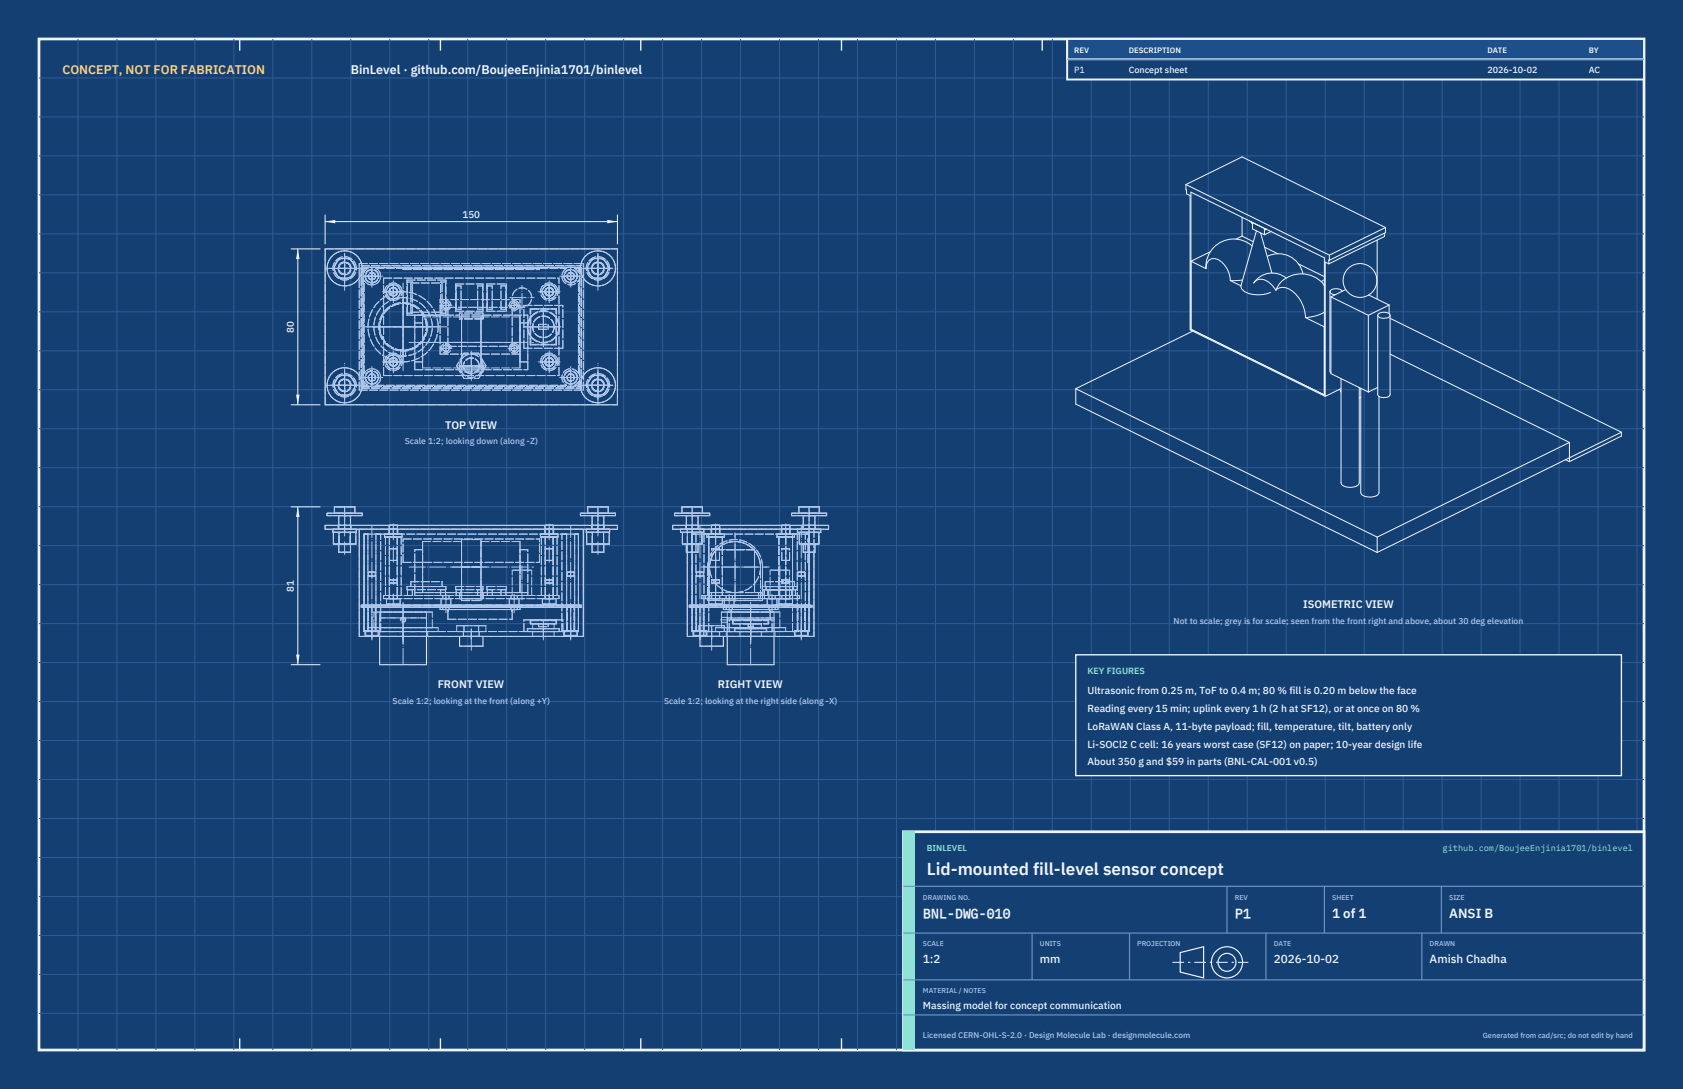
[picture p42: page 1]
CONCEPT, NOT FOR FABRICATION; BinLevel · github.com/BoujeeEnjinia1701/binlevel; FRONT VIEW; TOP VIEW; RIGHT VIEW; ISOMETRIC VIEW; REV; DESCRIPTION; DATE; Concept sheet; BINLEVEL; github.com/BoujeeEnjinia1701/binlevel; DRAWING NO. BNL-DWG-010; REV P1; SHEET 1 of 1; SIZE ANSI B; SCALE 1:2; UNITS mm; PROJECTION; DRAWN Amish Chadha; Licensed CERN-OHL-S-2.0 · Design Molecule Lab · designmolecule.com; Generated from cad/src; do not edit by hand

Scale 1:2; looking down (along -Z)

Not to scale; grey is for scale; seen from the front right and above, about 30 deg elevation

KEY FIGURES
Ultrasonic from 0.25 m, ToF to 0.4 m; 80 % fill is 0.20 m below the face
Reading every 15 min; uplink every 1 h (2 h at SF12), or at once on 80 %
LoRaWAN Class A, 11-byte payload; fill, temperature, tilt, battery only
Li-SOCl2 C cell: 16 years worst case (SF12) on paper; 10-year design life
About 350 g and $59 in parts (BNL-CAL-001 v0.5)

Scale 1:2; looking at the front (along +Y)

Scale 1:2; looking at the right side (along -X)

Lid-mounted fill-level sensor concept

MATERIAL / NOTES
Massing model for concept communication

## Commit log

2026-09-25 Initial scaffold: standard open hardware layout, CERN-OHL-S v2 + MIT licenses
    Claude-Session: https://claude.ai/code/session_01XuhhSU4W6fYhgCfURbrkut
    [bom.csv]
2026-09-26 Populate to TRL 2: problem, requirements, precis, concept media, BOM and README use cases
    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
    [bom.csv]
2026-09-26 Advance to TRL 3: DDR-001, CAL-001 sizing, parametric model with STEP/STL, GA drawing, priced BOM; TRL 4 on hold
    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
    [binlevel-assembly.step, binlevel-assembly.stl, bom.csv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]
2026-09-26 Accept all recommendations (DDR-002), switch footer to designmolecule.com, add README write-up with new inspiration point
    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
    [binlevel-assembly.step, binlevel-assembly.stl, bom.csv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]
2026-09-27 Product appearance model and photoreal renders
    Adds cad/src/product_model.py (appearance model for renders only, all main
    dimensions from model.py) and Blender renders in media/render-*.png,
    captioned with the project, repository and viewing direction. README leads
    with the product render; trl stays 3.
    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
2026-10-01 Image quality pass: legible exploded views, flow diagrams and drawing sheets
    Kit 1.6.1 image layout: the parts list sits in its own column, number bubbles sit on visible parts and never overlap, small parts get a leader, pictures are cropped to the subject, flow labels keep numbers with their units, and sheet captions and the revision table no longer overprint. Concept images, blueprint and general arrangement sheet regenerated; repo-specific labels moved clear of other text and lines.
2026-10-01 Kit 1.7.0: constructable design, illustrated build plan and design decisions register
    The design is now constructable: every part can be made and fits its neighbours, with each change recorded in a Design for construction decision record (made under Amish's 2026-09-30 instruction; ope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
    [binlevel-assembly.step, binlevel-assembly.stl, bom.csv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]
2026-10-01 Budget treated as a value-engineering target
    Amish, 2026-10-01: the budget is a hypothetical control target that keeps the design on a value-engineering lens, not a spending limit. Documents now state the value-engineering target and the estima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
2026-10-02 Record Amish's approval of the open-decision recommendations
    Amish approved the recommendation on every open decision in the design decisions register ("i approve your recommendations for all 555 open decisions.", 2026-10-02). Each decision is moved to Decisio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
2026-10-03 Carry approved follow-ups into the design and redo photoreal renders
    Amish approved the follow-up actions from the open-decision sign-off ("APPROVED CHANGES, COMPLETE THESE", 2026-10-02), the design-for-construction change tables in ten repos, the last wave's open dec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
    [binlevel-assembly.step, bom.csv, bracket.step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]

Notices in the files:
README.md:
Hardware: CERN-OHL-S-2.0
